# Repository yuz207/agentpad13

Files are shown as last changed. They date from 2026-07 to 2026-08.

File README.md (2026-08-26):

# agentpad13

A 13-key macropad for agentic work, designed from scratch: RP2040, USB-C, 12×1U + 1×2U hot-swap
keys, a clickable EC11 encoder, an analog tilt joystick, a capacitive-touch key, and 24 RGB LEDs
(per-key plus edge underglow) that an open Raw HID protocol drives to show what your agents are
doing — thinking, running, waiting, done, one key each.

## Build one

### → [Open the configurator](https://yuz207.github.io/agentpad13/configurator/site/)

Pick your options, turn the pad around in 3D, and get back an order sheet where every line links to
the exact file you upload to a fab or drop into a slicer. That is the way in. Prefer paper?
[`release/HOW-TO-ORDER.md`](release/HOW-TO-ORDER.md) is the same thing, static.

<p align="center">
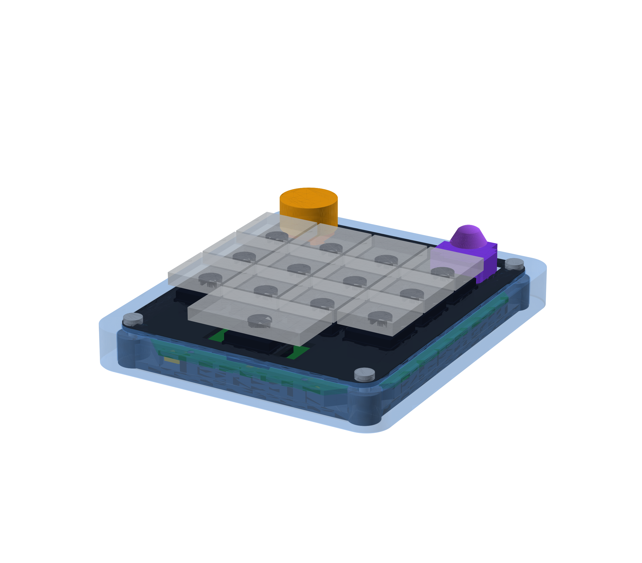
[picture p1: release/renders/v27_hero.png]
agentpad13 v5 board in the v2 case, from CAD
  
</p>

<p align="center"><sub>The shipping v5 board in the v2 case, straight from the CAD.</sub></p>

## What is where

```
release/            The bundle — everything you order, print or flash.
  HOW-TO-ORDER.md     The configurator's static form.
  RELEASE.md          What shipped and why, section by section.
  MANIFEST.md         Every file in the bundle with its md5 and byte count.
  hardware/           Board fab package, case, plate, bases, keycaps, toppers, gasket.
  firmware/           Flashable UF2s, BRING-UP.md, POLARITY-NOTE.md.
configurator/       The published site and its consumption assets; current outputs are copied from development.
firmware/           vial-qmk tree, simulations, conformance tests, BUILD.md.
docs/               The Raw HID protocol contract, and the design reviews.
```

Before you send anything to a fab, run `python3 manifest_selfverify.py` — it should print
**9/9 checks PASS**. Every listed file is present with the right hash, and nothing unlisted is
hiding in the bundle.

## Printed toppers already? Print them again

The v1 encoder knobs and stick caps are retired. The current release carries three Ø17.5 encoder
knob styles and three joystick toppers: a compact nub, restored TPU puck, and a conventional Ø12
topper paired with a TPU restrictor. Details are in [`release/RELEASE.md`](release/RELEASE.md) §(f).

## Status

- **PCB — complete.** v5_8, 84.2 × 100 mm, 2-layer, DRC clean, fab package ready to upload. It retains the v5.7 LED correction, adds the Ø4.0 TP5 solder landing, and factory-populates the encoder.
- **Case — complete.** v2.17: FR4 or printed plate, band in three sidewalls, printed tray.
- **Bases — complete.** Three optional printed bases; the case is finished without one.
- **Firmware — validated.** Emulator-booted and protocol-conformant. Flash `agentpad13.uf2`.
- **Configurator — live.** Static files: no build step, no network calls, no dependencies.

### AgentPad13 Direct OAI (experimental alternative)

The isolated `codex_oai` keymap is an experimental alternative for direct
Codex Desktop control. It is not Vial firmware and does not replace the normal,
recommended `release/firmware/prebuilt/agentpad13.uf2`. Codex Desktop talks to
this target directly—no helper, daemon, bridge, or Vial protocol—using the
locked `Codex Micro Lab OAI LED` identity (`303A:8360`, usage `FF00:61`, Report
ID 6, 64-byte reports).

The current unflashed candidate is
`release/firmware/prebuilt/agentpad13_codex_oai.uf2`, 93,696 bytes, SHA-256
`fcb50b2419419be43b7cf90b00a96b16063fcaf182bc24b9642d57e2e8adf54d`.
Start with the [keymap contract](firmware/loudest_micro/keymaps/codex_oai/README.md),
[source hand-off](firmware/CODEX-OAI-SOURCE.md), and
[Direct OAI build procedure](firmware/BUILD.md#agentpad13-direct-oai-experimental-alternative).
Run the complete host suite from the repository root:

```sh
python3 -m unittest discover -s firmware/tests/codex_oai -p 'test_*.py'
```

The checked-in [emulator capture](firmware/evidence/codex-oai-emulator.json)
and [current manifest](firmware/evidence/codex-oai-current-manifest.json) bind
that exact UF2 to the offline USB/protocol/LED checks. Physical validation is
still entirely PENDING; no install or flash occurred. Any future hardware
operation requires the literal authorization and observation record in the
[physical runbook](docs/codex-oai-physical-runbook.md).

## First power-on

Flash [`agentpad13.uf2`](release/firmware/prebuilt/agentpad13.uf2) — hold BOOTSEL and drag the file on. Then hold
SW14, the button in the back, for about a second and follow the 13 key LEDs: the board measures its
own joystick and stores the result. About 15 seconds, no host software, no reflash, once ever —
full procedure in [`release/firmware/BRING-UP.md`](release/firmware/BRING-UP.md). If an axis reads
backwards that is polarity, not calibration:
[`release/firmware/POLARITY-NOTE.md`](release/firmware/POLARITY-NOTE.md).

Firmware source is in [`firmware/loudest_micro/`](firmware/loudest_micro/); the exact Vial/QMK
build recipe and validation commands are in [`firmware/BUILD.md`](firmware/BUILD.md). The plain-QMK,
byte-reproducible build is [`agentpad13_reference.uf2`](release/firmware/prebuilt/agentpad13_reference.uf2).

## Licensing

- `release/hardware/` — **CERN-OHL-W-2.0** (PCB and case CAD).
- `firmware/` and `release/firmware/` — **GPL-2.0-or-later** (QMK/vial-qmk
  derivative), except `firmware/tests/conformance/protocol_oracle.py`, which is
  **MIT**. Corresponding source for the prebuilt UF2s = this tree built against
  [vial-qmk](https://github.com/vial-kb/vial-qmk) per `firmware/BUILD.md`.

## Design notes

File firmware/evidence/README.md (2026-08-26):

# Evidence files

`codex-oai-emulator.json` is the current emulator capture for
`release/firmware/prebuilt/agentpad13_codex_oai.uf2`. It was regenerated from
this checkout and must match the UF2 SHA-256 and byte size recorded in
`codex-oai-current-manifest.json`. The current port rebuild is 93,696 bytes
with SHA-256
`fcb50b2419419be43b7cf90b00a96b16063fcaf182bc24b9642d57e2e8adf54d`.

Two earlier provenance layers remain explicit:

- The imported phase-3 migration baseline was 92,160 bytes with SHA-256
  `d1768471eef4d0be12c1fc264279f20b9a7d293ea902c0608ebcfb4643ae35be`.
  It was copied byte-for-byte before the destination rebuild and is superseded
  by the current port artifact; it is not a claim about the final source.
- `codex-oai-manifest.json` is retained as historical full-image evidence for
  the still older 92,672-byte artifact with SHA-256
  `11ee3ed649cf198186fc1e3c190fcaf6a7a1cfbdb18f68ebbead974b09a1712b`.
  Its ELF metrics and hash intentionally refer to that older artifact; it is
  not a claim about the current release UF2.

To produce a new full manifest after a clean QMK build, run
`firmware/tools/verify_codex_oai_artifact.py` with the newly generated ELF, the
current emulator JSON and an output path below this directory. The verifier
checks the UF2 hash, ELF size/symbols and emulator handshake atomically; no
device or removable volume is accessed.

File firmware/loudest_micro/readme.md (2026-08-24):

# agentpad13

Open-hardware agent macropad (Rev A, RP2040). 13 keys (12x 1U grid + 1x 2U
hero), EC11 encoder with push, planar analog joystick, TTP223 touch pad, and
24 addressable LEDs (13 per-key + 1 layer indicator + 10 underglow) driven as
a live agent-status display over Raw HID.

* Keyboard Maintainer: [yuz207](https://github.com/yuz207)
* Hardware Supported: agentpad13 Rev A PCB (RP2040, public board `v5_8`)
* Hardware Availability: open source (CERN-OHL-W v2), <https://github.com/yuz207/agentpad13>

The QMK keyboard/module name is `loudest_micro` (the project's working name);
the user-visible product name, USB product string, and Vial sidebar name are
**agentpad13**. The directory name is kept because QMK derives build targets,
artifact names, and file names from it. The public Raw HID contract is
`docs/PROTOCOL-V1-CONTRACT.md`.

Pin map source of truth: the definitive table embedded in
`firmware/check_pins_v4.py`, extracted twice from the final copper and
re-verified against v5_6. The public v5_8 board retains the v5.7 LED20/LED21
orientation, so the GPIO map is identical; see `release/hardware/pcb/V5-NOTES.md`.

Make example for this keyboard (after setting up your build environment):

    qmk compile -kb loudest_micro -km default
    qmk compile -kb loudest_micro -km vial

Flashing example for this keyboard:

    qmk flash -kb loudest_micro -km default

To enter the bootloader, hold BOOTSEL while plugging in USB (or double-tap
RESET), then copy the `.uf2` onto the `RPI-RP2` drive.

See the [build environment setup](https://docs.qmk.fm/#/newbs_getting_started) and
the [make instructions](https://docs.qmk.fm/#/getting_started_make_guide) for more
information. Brand new to QMK? Start with our [Complete Newbs
Guide](https://docs.qmk.fm/#/newbs). The exact reproducible toolchain for this
board (vial-qmk fork, patch, versions) is in `firmware/BUILD.md`.

## Layout

```
 [JS]        USB        (ENC)      <- top control band (not in the key matrix)
 +----+----+----+----+
 |SW1 |SW2 |SW3 |SW4 |            row 0
 +----+----+----+----+
 |SW5 |SW6 |SW7 |SW8 |            row 1
 +----+----+----+----+
 |SW9 |SW10|SW11|SW12|            row 2
 +----+----+----+----+
 |TP| |  SW13   | |EP|            row 3: touch [3,2] | SW13 2U [3,0] | encoder push [3,1]
 +--+ +---------+ +--+
```

Direct-pin matrix (Rev A x-monotonic routing remap - logical positions are
unchanged, only the physical GPIOs moved):

| Function | GPIO |
|---|---|
| SW1..SW4 (row 0) | GP12, GP9, GP5, GP2 |
| SW5..SW8 (row 1) | GP11, GP8, GP4, GP1 |
| SW9..SW12 (row 2) | GP10, GP7, GP3, GP0 |
| SW13 (2U hero) | GP6 |
| Encoder A / B / push | GP13 / GP14 / GP15 |
| Touch (TTP223 OUT) | GP16 |
| WS2812 data (via level shifter) | GP17 |
| Joystick X / Y (ADC) | GP26 / GP27 |

## Firmware feature notes

* `ENCODER_MAP` - per-layer encoder actions (volume by default).
* `JOYSTICK` - GP26/GP27 analog axes as a HID gamepad; the `JS_MODE` keycode adds
  custom arrow (8-way) and scroll modes. **The board calibrates itself**: hold
  SW14 (the button in the back, inert while firmware runs) for about a second
  and the key LEDs guide a ~15 s routine that writes rest/min/max to EEPROM,
  where it survives unplugging and reflashing. No host software, no second
  firmware, no rebuild — see `firmware/BRING-UP.md`. The shipped
  `low 0 / rest 512 / high 1023` values are only the uncalibrated fallback.
* `RAW_ENABLE` - status protocol **v1** (`SET_KEY`/`SET_LAYER`/`CLEAR`/`PING`,
  plus `GET_JOYSTICK`/`SET_CALIBRATION`/`RESET_CALIBRATION` — the same
  calibration store the SW14 routine writes, exposed for host tooling), wire
  contract in `docs/PROTOCOL-V1-CONTRACT.md` with
  `firmware/tests/conformance/protocol_oracle.py` as the public, dependency-free
  host oracle. In the vial build the
  protocol coexists with VIA/Vial through a `via_command_kb()` dispatcher
  (see `firmware/BUILD.md` for the documented edge-case collisions).
* Touch key gated by the `TP_TOG` keycode.

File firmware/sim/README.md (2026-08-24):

# agentpad13 — pre-hardware behavioral simulation

Boots the **real production `.uf2`** in a headless RP2040 emulator and drives it
the way a user would: presses every switch, turns the encoder, taps the touch
pad, moves the joystick, and paints every LED over raw HID — then checks what
came back out over USB and what landed in the LED chain buffer.

This is the layer above [`firmware/tests/emulator/`](../tests/emulator/), which
proves the binary *boots, muxes its pins correctly, enumerates, and answers one
PING*. This directory answers the four questions you actually care about before
the boards land:

| Question | Answered here? |
|---|---|
| Do presses register? | **Yes** — all 13 switches, each to its own keycode |
| Do the LEDs trigger? | **Yes** — the ws2812 DMA buffer is read back per frame |
| Are they individually addressable? | **Yes** — 24/24 chain positions, byte-exact, in isolation |
| Does the firmware work? | **Now yes — after it found the reason it didn't.** See below. |

> ## ✅ FIXED 2026-08-13 — this harness caught a ships-broken defect, and the fix is in
>
> **As originally written, both shipped `.uf2`s FAILED 4 of 33 checks under the
> default `--touch=board`.** The cause was a real, ships-broken defect: the
> TTP223 touch strap is wired active-**high** and the firmware assumed
> active-**low**. Detail in
> [The defect this harness catches](#the-defect-this-harness-catches).
>
> The **firmware-only** remedy was applied (boards were already fabricated *and
> populated*, so the `R10` rework was not available): `GP16` was removed from
> `matrix_pins.direct` and is polled with its own active-high sense in
> `loudest_micro.c` `matrix_scan_kb()`, injecting the key event at the same
> logical `[3,2]`. **The current `firmware/prebuilt/*.uf2` pass 33/33 under
> `--touch=board`** — see [After the fix](#after-the-fix).
>
> Nothing in `behavior.cjs` was changed to make that happen; the harness that
> passed the fixed binaries was byte-identical to the one that failed the broken
> ones. *(`behavior.cjs` was edited once since, on 2026-08-15, and only to ADD
> the `--encoder=` A/B described below — an extension, not a relaxation: the
> check count is still 33 and the four touch failures under `--touch=firmware`
> are still byte-identical to the ones quoted here. No check was ever adjusted to
> make a failing thing pass.)*

---

## Run it

One-time setup (installs `rp2040js` and fetches the RP2040 B1 bootrom dump into
the *existing* emulator directory — this directory adds no dependencies of its
own):

```bash
cd firmware/tests/emulator
./get-bootrom.sh && npm install
```

Then:

```bash
cd firmware/sim
node behavior.cjs                                # reference build, board truth on both A/Bs
node behavior.cjs ../prebuilt/agentpad13.uf2     # the vial build
node behavior.cjs --touch=firmware               # the polarity config.h used to assume
node behavior.cjs --encoder=firmware             # the A/B landing config.h used to assume

node joystick.cjs                                # protocol-v1 referee (0x50/0x51/0x52 + EEPROM
                                                 #   + the SW14 on-board routine, section 10)
node joystick.cjs --no-eeprom                    # its counterfactual arm; must FAIL
```

or `npm run sim:default` / `sim:vial` / `sim:default:fwpolarity` /
`sim:default:fwencoder` / `joystick:default` / `joystick:vial` from this
directory. `behavior.cjs` takes **~35 s** on an M-series Mac and `joystick.cjs`
**~6 min** (it grew from ~45 s on 2026-08-15: section 10 drives the real
on-board calibration routine, which is ~15 s of *emulated* time per run and is
run three times — there is no way to shorten it without shortening the routine
the owner actually performs). Both exit non-zero on any failure, so they drop
straight into CI. No network, no account, no cloud upload, no browser.

> **Artifact names changed 2026-08-15.** `firmware/prebuilt/` now ships
> `agentpad13.uf2` (the vial build — the one users want) and
> `agentpad13_reference.uf2` (the plain-QMK, byte-reproducible reference). They
> replace `loudest_micro_vial.uf2` and `loudest_micro_default.uf2`, which is why
> older transcripts in this file name the old files.

### `--touch=` — the most important flag

| Mode | GP16 at rest | Meaning |
|---|---|---|
| `board` *(default)* | **LOW** | What the v5 PCB does. `R10` (0 Ω) ties `TOUCH_AHLB → GND`; on a TTP223, AHLB low selects **active-high** output, so Q idles LOW and drives HIGH while touched. **This is the mode that must pass.** |
| `firmware` | HIGH | The polarity `config.h` *used to* assume — *"idle high, touched low"*. Kept as the counterfactual arm of the A/B; it does **not** describe any board that exists, and since the fix it is the arm that fails. |

Both shipped builds, run four ways — **before** the fix (Rev-A binaries
`4af788ae…` / `e5008942…`) and **after** it (`cf5bd628…` / `b31673a7…`):

> **Hash note, 2026-08-15.** The shipped pair moved again — `1c0ff911…`
> (default) / `286fb09d…` (vial) — for the isotropic RGB layout and the
> `housekeeping_task_user()` de-duplication. Neither touches polarity, and the
> table below re-measures **identically** on the new binaries: 33/33 PASS under
> `--touch=board`, 4 failures under `--touch=firmware`. The `cf5bd628…` /
> `b31673a7…` labels are kept because this table is the record of the *touch
> fix*'s A/B, not a statement about which bytes ship today.

| Build | `--touch=firmware` | `--touch=board` |
|---|---|---|
| `loudest_micro_default.uf2` **before** | 33 checks, **0 failures** — PASS | 33 checks, **4 failures** — FAIL |
| `loudest_micro_vial.uf2` **before** | 33 checks, **0 failures** — PASS | 33 checks, **4 failures** — FAIL |
| `loudest_micro_default.uf2` **after** | 33 checks, **4 failures** — FAIL | 33 checks, **0 failures** — **PASS** |
| `loudest_micro_vial.uf2` **after** | 33 checks, **4 failures** — FAIL | 33 checks, **0 failures** — **PASS** |

That A/B is the whole diagnostic, and it inverted cleanly: **the same binary
passes under one polarity and fails under the other, and the fix moved which one
is which.** The keymap, the LED chain, the USB stack, the encoder and the
joystick were always fine — only the strap sense was wrong, and the four
failures are exactly the four polarity-bearing checks. A post-fix
`--touch=firmware` failure is therefore expected and *correct*: it is the harness
still proving it can tell the two polarities apart. (The DIAGNOSIS prose printed
in that arm was written for the pre-fix direction and now reads backwards; it is
left verbatim because `behavior.cjs` is the referee and was deliberately not
edited as part of the fix.)

### `--encoder=` — the same idea, for the EC11

Added **2026-08-15**, and for the same reason the touch A/B exists: this harness
had a hard-coded belief about the board that turned out to be false.

A quadrature walk on `GP13`/`GP14` has **no intrinsic handedness**. Which of the
two walks is a physically *clockwise* detent depends on which EC11 terminal
landed on `ENC_A` and which on `ENC_B` — a board fact, exactly like the AHLB
strap. `behavior.cjs` used to assert one answer outright: *the forward walk is
clockwise, therefore it must produce `KC_VOLU`.* Nobody had measured that.

**The owner measured it on the assembled board on 2026-08-15: turning the knob
clockwise produced volume-DOWN.** The firmware was corrected
(`config.h`: `#define ENCODER_DIRECTION_FLIP`, which swaps which walk vial-qmk's
`drivers/encoder/encoder_quadrature.c` calls clockwise), and the harness's
falsified assumption was turned into a switch rather than left standing:

| Mode | "Clockwise" is | Meaning |
|---|---|---|
| `board` *(default)* | the **reversed** GP13/GP14 walk | The fabricated v5_6 A/B landing, measured on hardware and unchanged in public v5_8. **This is the mode that must pass.** |
| `firmware` | the **forward** walk | What this file asserted before 2026-08-15, i.e. the pre-flip assumption. It describes no board that exists; since the flip it is the arm that fails. |

Both modes assert the **same behavior** — CW must give `KC_VOLU`, CCW must give
`KC_VOLD`. Only the walk that stands for "clockwise" moves, which is the one
thing the board decides. No check was relaxed and the count is still 33.

The two switches are independent and compose, which is itself the proof that
each isolates its own fault. Measured on both current builds:

| `--touch=` | `--encoder=` | checks | failures | which |
|---|---|---|---|---|
| `board` | `board` | 33 | **0 — PASS** | the gate |
| `board` | `firmware` | 33 | 2 | both encoder checks, and only those |
| `firmware` | `board` | 33 | 4 | the four touch checks, byte-identical to the 2026-08-13 table above |
| `firmware` | `firmware` | 33 | 6 | 4 + 2, no interaction |

---

## The defect this harness catches

> **Historical record — everything in this section describes the firmware as it
> shipped BEFORE 2026-08-13.** The board facts are still current; the firmware
> quotes are not (both comments were corrected). Kept verbatim so the failure and
> its evidence stay legible. See [After the fix](#after-the-fix).

**Board truth**, confirmed directly in the released board:

* `release/hardware/pcb/v5_8.kicad_pcb` — footprint `R10`, value `0R`, pads
  `1 → TOUCH_AHLB`, `2 → GND`

On a TTP223, **AHLB tied low selects active-high output**: `Q` idles LOW and
goes HIGH while the pad is touched.

**Firmware assumption**, which is the opposite:

* `firmware/loudest_micro/config.h:21` — *"The PCB straps the AHLB pad
  active-low, so the pad reads like a normal direct pin (idle high, touched
  low)."*
* `firmware/loudest_micro/keyboard.json:32` — *"PCB straps AHLB active-low so it
  reads like a normal direct pin"*

**And nothing reconciles them.** `MATRIX_INPUT_PRESSED_STATE` is never defined
anywhere in the keyboard tree, so QMK's default applies: a direct pin reading
LOW is *pressed*. There is no inversion in `matrix.c`, none in
`loudest_micro.c` (the only touch-related code there is `touch_enabled`, a
TP_TOG gate, not a polarity flip).

### What that does, as the sim demonstrates

GP16 rests LOW → matrix `[3,2]` is **held from power-on**. `[3,2]` is the
layer-cycle key, `TO(L_CTRL)` on layer 0. So:

```
0b. boot layer — the layer indicator must say layer 0 (BASE)
  ..   layer indicator (chain 13) at boot: 31,23,0
  [FAIL] device booted into layer 0 (indicator is pure red, hue 0)  <- 31,23,0

0c. blast radius — SW1 at the as-booted layer must still be KC_F13
  [FAIL] SW1 emits KC_F13 (0x68) from the as-booted layer  <- no keyboard report at all
  !!   The layer-0 keymap is unreachable: every one of the 12 macro keys, and the
  !!   2U hero key, resolves against L_CTRL instead (RGB/media/JS_MODE), and the
  !!   encoder maps to RGB_MOD rather than volume.

0d. touch polarity — the layer must advance ON TOUCH, not on release
  ..   layer indicator: rest 31,23,0 -> touched 31,23,0 -> released 15,31,0
  [FAIL] the layer advances while the pad is TOUCHED  <- still 31,23,0 while touched
  [FAIL] the layer does NOT advance again when the finger LIFTS  <- ... -> released 15,31,0
  !!   DIAGNOSIS: the layer moved on finger LIFT — the inverted-polarity signature.
```

Three separate user-visible symptoms, all from one strap:

1. **The pad boots into layer 1 (CTRL) and can never reach layer 0 (BASE).**
   `F13`–`F24` — the entire product — are unreachable. Indicator hue 32 (orange)
   at power-on instead of hue 0 (red).
2. **Pressing SW1 emits nothing at all**, because layer 1 puts `JS_MODE` there,
   a custom keycode with no USB report. The encoder becomes `RGB_MOD` instead of
   volume.
3. **Touch fires on finger LIFT, not on touch** — every touch action is off by
   one edge.

### How it was fixed — and one trap that was avoided

**⚠ `MATRIX_INPUT_PRESSED_STATE 1` is NOT the fix.** That define is *global*, not
per-pin: QMK's `readMatrixPin()` applies it to every direct pin
([`quantum/matrix.c:97`](https://github.com/qmk/qmk_firmware/blob/master/quantum/matrix.c)),
so setting it to `1` would invert all 13 mechanical switches — which really are
active-low to GND — and trade one broken key for thirteen.

There were two real options, **alternatives, not both**:

* **Hardware.** Move `R10` from `GND` to `+3V3`. AHLB high selects active-low
  output, which is what the firmware already expected — exactly the escape hatch
  `SCHEMATIC-REVIEW.md:156` documents (*"move to +3V3 for active-low"*). **Not
  available:** the boards are already fabricated *and populated*, so this would
  be a per-unit 0402 rework.
* **Firmware (the one taken, 2026-08-13).** `GP16` was dropped from
  `matrix_pins.direct` (`[3][2] → null`) and is polled in `loudest_micro.c`
  `matrix_scan_kb()` — matrix-scan cadence, 5 ms debounce — with its own
  active-high sense, injecting `action_exec(MAKE_KEYEVENT(3, 2, pressed))` so the
  key keeps its logical position, its keycode, its `TO()` layer chain and its
  `TP_TOG` gate. `keyboard_pre_init_kb()` configures the pin (pull-**down**, so a
  high-Z `U6` reads untouched), because `matrix_init_pins()` no longer sees it.
  Cost: Vial's matrix tester cannot display `[3,2]`, since that reads the scanned
  `matrix[]`.

Both comments that asserted the wrong polarity — `config.h:21` and
`keyboard.json:32` — were corrected in the same change.

---

## After the fix

`--touch=board` — the real hardware polarity — **33/33 on both builds**. This is
the acceptance run; the harness was not modified to produce it.

> **This transcript is the 2026-08-13 acceptance run, kept verbatim as the record
> of the touch fix.** It names `loudest_micro_default.uf2`, which no longer
> exists, and it predates the `--encoder=` A/B, so its summary line has no
> encoder model on it. The current gate is
> `node behavior.cjs --touch=board --encoder=board` against
> `agentpad13_reference.uf2` / `agentpad13.uf2`, and it still reads
> **33 checks, 0 failures** on both.

```
agentpad13 behavioral sim — loudest_micro_default.uf2
loaded 173 UF2 blocks
touch model: BOARD TRUTH — TTP223 AHLB->GND (R10) = active-high, GP16 idles LOW

0. boot + USB enumeration
  [ok] USB configured
  ..   interfaces: #0 cls3/proto1 in1  #1 cls3/proto0 in2/out3
  [ok] ws2812 DMA source buffer located
  ..   pixel buffer @ 0x200020c0 (24 x uint32, GRB in bits 31:8)
  [ok] pixel words carry GRB<<8 (low byte always 0)

0b. boot layer — the layer indicator must say layer 0 (BASE)
  ..   layer indicator (chain 13) at boot: 31,0,0
  [ok] device booted into layer 0 (indicator is pure red, hue 0)

0c. blast radius — SW1 at the as-booted layer must still be KC_F13
  [ok] SW1 emits KC_F13 (0x68) from the as-booted layer

0d. touch polarity — the layer must advance ON TOUCH, not on release
  ..   layer indicator: rest 31,0,0 -> touched 31,23,0 -> released 31,23,0
  [ok] the layer advances while the pad is TOUCHED
  [ok] the layer does NOT advance again when the finger LIFTS
  [ok] touch sends no USB key report (TO() is a layer move)

1. LED chain — 24 positions, one unique color each (raw HID SET_KEY)
  [ok] all 24 chain positions independently addressable
  ..   0-12 per-key: 10,100,200  13,98,195  ...  46,76,140
  ..   13 indicator: 49,74,135
  ..   14-23 underglow: 52,72,130  ...  79,54,85
  [ok] repainting LED 9 alone moves only LED 9
  [ok] LED 9 took the exact requested color 254,2,127

2. CLEAR releases the chain back to the on-device animation
  [ok] no LED is still holding its host-set color
  [ok] chain is live (some LED is lit by the local animation)
  ..   layer-0 indicator (chain 13): 31,0,0
  [ok] layer-0 indicator is pure red (hue 0 = layer 0)

3. every switch — GPIO low -> the keycode the default keymap assigns
  [ok] GP12 SW1  [0,0] -> KC_F13 (0x68) then release
  [ok] GP 9 SW2  [0,1] -> KC_F14 (0x69) then release
  [ok] GP 5 SW3  [0,2] -> KC_F15 (0x6a) then release
  [ok] GP 2 SW4  [0,3] -> KC_F16 (0x6b) then release
  [ok] GP11 SW5  [1,0] -> KC_F17 (0x6c) then release
  [ok] GP 8 SW6  [1,1] -> KC_F18 (0x6d) then release
  [ok] GP 4 SW7  [1,2] -> KC_F19 (0x6e) then release
  [ok] GP 1 SW8  [1,3] -> KC_F20 (0x6f) then release
  [ok] GP10 SW9  [2,0] -> KC_F21 (0x70) then release
  [ok] GP 7 SW10 [2,1] -> KC_F22 (0x71) then release
  [ok] GP 3 SW11 [2,2] -> KC_F23 (0x72) then release
  [ok] GP 0 SW12 [2,3] -> KC_F24 (0x73) then release
  [ok] GP 6 SW13 [3,0] 2U hero -> KC_MPLY (consumer 0xcd)
  [ok] GP15 ENC_SW [3,1] push -> KC_MUTE (consumer 0xe2)

4. EC11 encoder — quadrature on GP13/GP14, layer 0 maps to volume
  [ok] rotate CW -> KC_VOLU (consumer 0xe9)
  [ok] rotate CCW -> KC_VOLD (consumer 0xea)

5. analog joystick — ADC injection -> HID gamepad report (report id 0x07)
  ..   rest                   report (none)  axes=n/a
  ..   ADC0 high / ADC1 low   report 071afee801  axes=-486,488
  ..   ADC0 low / ADC1 high   report 07e8011afe  axes=488,-486
  [ok] joystick emits HID gamepad reports at all
  [ok] both axes swing to near full scale on a full ADC sweep
  [ok] the two axes move independently (swapping the ADC inputs flips both signs)
  ..   ADC channels the emulator serviced: [1,0]
  ..   axis IDENTITY (which report slot is X) is NOT decided by this run.

touch model: board   checks: 33   failures: 0
BEHAVIOR SIM: PASS
```

`loudest_micro_vial.uf2` produces the identical 33/33, with the pixel buffer at a
different address — which is exactly why the buffer address is **discovered at
runtime** rather than hardcoded. The default image grew by one 512-byte UF2 block
(172 → 173) for the out-of-matrix touch handling.

The sibling smoke test `firmware/tests/emulator/runner.cjs` carried the same
wrong idle-level assumption (it drove GP16 high with the switch lines and
asserted a pull-up on it) and was corrected to board truth in the same change; it
now fails on the pre-fix binaries and passes on the current ones.

---

## How the LED readback works

QMK's RP2040 `vendor` ws2812 driver hands its pixel array to a DMA channel that
feeds **PIO0's TX FIFO** (`PIO0_BASE + TXF0 = 0x50200010`). The harness watches
every DMA channel start; the lowest read address of whichever channel targets
`TXF0` *is* the pixel buffer, by definition. Nothing is hardcoded, so a rebuild
that moves the buffer does not break the test.

Each entry is one `uint32` carrying **GRB in bits 31:8** — the state machine
runs autopull with `PULL_THRESH = 24`, MSB first, so the low byte is always
zero. The harness asserts that invariant structurally; if a future QMK changes
the packing, the run fails loudly instead of printing plausible nonsense.

So the colors printed above are **the exact words the PIO shifts onto GP17** —
one hop short of the wire.

The chain-index proof is the important part: `SET_KEY(i, r, g, b)` was sent for
every `i` in `0..23` with a distinct color, and every one landed at chain
position `i` with the exact bytes requested. Then LED 9 alone was repainted and
**only** LED 9 moved. That is what "individually addressable" means, and it is
now demonstrated on the shipping binary rather than assumed.

---

## What this cannot tell you

Read this before treating a PASS as permission to skip bring-up.

### Not simulated at all — only real hardware can answer

* **WS2812/SK6812 bit timing on the wire.** The emulator is *not cycle-faithful*
  (the PIO is stepped from the harness loop because `RPPIO.run()` self-schedules
  via `setTimeout`, and its `CLKDIV` is parsed but never used to pace
  execution — [rp2040js PR #117](https://github.com/wokwi/rp2040js/pull/117) was
  closed unmerged). We validate the *data*, never the `T0H`/`T1H` pulse widths.
* **The SN74LVC1T45 level shifter, the 5 V rail, and the LED chain itself.**
  We stop at GP17. Whether LED 7 is physically wired seventh is a hardware fact.
* **Whether the touch pad works as a sensor.** We model GP16's *logic level*
  from the strap. Pad sensitivity through the case, C25 tuning, and false
  triggering are unanswerable without the board.
* **Encoder detent direction — *was* unanswerable here, and it bit us.** This
  bullet used to read *"we prove a CW quadrature walk produces `KC_VOLU`;
  whether turning the physical knob clockwise produces the CW walk depends on
  which way A and B are soldered"* — correctly identifying the gap, while the
  harness went on asserting one side of it anyway. The owner measured the real
  board on **2026-08-15** (clockwise gave volume-DOWN), the firmware got
  `ENCODER_DIRECTION_FLIP`, and the assumption became the `--encoder=` A/B
  above. The emulator still cannot tell you which walk your knob makes; it can
  now tell you which walk this *board* makes, because a human measured it once.
* **Joystick axis direction.** Which way the gimbal drives each wiper is
  mechanical and is still not answerable here — see `firmware/POLARITY-NOTE.md`.
  (Calibration itself is no longer in this list: see the next bullet.)
* **EEPROM / Vial persistence — no longer out of reach.** rp2040js's SSI
  peripheral is a stub and flash writes do not work in stock rp2040js
  ([#157](https://github.com/wokwi/rp2040js/issues/157)), and its `IO_QSPI` is
  an `UnimplementedPeripheral` whose `0xffffffff` reads make QMK's wear-levelling
  driver believe every flash access was aborted — so an EEPROM write used to be
  a silent no-op. `joystick.cjs` attaches a small serial-NOR model to the SSI
  (workaround **(g)** below) and therefore **does** exercise QMK's emulated
  EEPROM: it stores a calibration, restarts the emulated MCU carrying only the
  flash image, and reads the values back. Its `--no-eeprom` arm removes the model
  and must fail on exactly those checks. What is still out of reach is Vial's own
  dynamic-keymap persistence, which nothing here drives.
* **Anything electrical:** USB timing margins, inrush, the 500 mA budget,
  brownout, ESD, thermals.

### Simulated but NOT trustworthy

* **Joystick axis identity.** The run shows ADC0 (GP26, declared `x`) landing in
  the *second* report slot and ADC1 (GP27, declared `y`) in the *first*. **Do
  not read that as an axis swap in the firmware.** rp2040js's round-robin
  channel selector has a real masking bug — `adc.ts` writes
  `(channel & CS_AINSEL_SHIFT)` where `CS_AINSEL_SHIFT` is `12`, when it means
  `(channel & CS_AINSEL_MASK)` with mask `0x7`; that is the root cause of open
  issue [#141](https://github.com/wokwi/rp2040js/issues/141) *("only ADC0 (pin
  26) reads successfully")*. The harness prints the channel order the emulator
  actually serviced so the artifact is visible. The *magnitudes* are sound:
  12-bit `4000` → QMK's 10-bit `1000` → `+488`, and `100` → `25` → `-486`, both
  correct against `rest = 512`.
* **USB config descriptor completeness.** Continuation packets of a multi-packet
  control IN transfer never arrive, so the 91-byte configuration descriptor
  truncates at 64. The boot-keyboard and raw-HID interfaces are complete within
  that first packet; the third (shared: NKRO / consumer / joystick) interface is
  not, so the harness identifies its endpoint from observed traffic instead. A
  descriptor defect in those last 27 bytes would not be caught.
* **Timing-dependent behavior generally** — debounce windows, tap-hold terms,
  `RGB_MATRIX` frame rate. Simulated time is not wall time.

### Emulator workarounds in force

Seven rp2040js fidelity issues are worked around **in the harness, never in the
firmware**, each commented at its site.

**(a)–(e), in both harnesses** (the first four match
`firmware/tests/emulator/runner.cjs`): the ADC `FIFO_REG` interrupt latch,
unimplemented DMA `CHAN_ABORT` reads, DREQ latches that only update on FIFO
transitions, `chan.start()` ignoring an already-asserted DREQ, and the PIO's
`setTimeout` self-scheduling. Pull-ups are also not folded into `inputValue`
([#154](https://github.com/wokwi/rp2040js/issues/154)), so idle-high lines are
driven high explicitly — **and GP16 is driven from the polarity model rather
than assumed, which is precisely what let this harness catch the strap bug.**

**(f) and (g), in `joystick.cjs` only, and both switchable** — a workaround that
cannot be switched off cannot be audited:

* **(f) `ADC.CS.START_ONCE` is self-clearing on silicon and not in rp2040js.**
  ChibiOS's RP ADC LLD sets the channel with a read-modify-write of `CS`, so the
  stale bit is written back and kicks off a second conversion; every
  `adcConvert()` then returns the previous conversion's value. Switch it off
  with `--no-adc-fix` and the board reports `live X=200 Y=800` for an injected
  `800/200` — the swap signature of a strict one-sample lag. **Measured, 2 of 48
  checks fail, and only the live-ADC ones.**
* **(g) flash writes do not work in stock rp2040js.** The SSI peripheral is a
  stub that discards `DR0` writes and always reports `RXFLR = 0`, and `IO_QSPI`
  is an `UnimplementedPeripheral` returning `0xffffffff` — which QMK's
  wear-levelling driver reads as *"flash access aborted"*, so its write loops
  bail out and the EEPROM silently never changes. `joystick.cjs` attaches a
  byte-level serial-NOR model (WREN / page-program / sector- and block-erase /
  read-status) to the SSI and a real register file to `IO_QSPI`, so writes land
  in the same `flash` array the XIP read path already serves. Two things had to
  be measured rather than guessed to make it work: the FIFO must answer even
  while CS is **high** (the bootrom's `flash_exit_xip()` clocks dummy bursts
  through the same loop, and the loop's only other exit was the now-honest abort
  flag — boot hangs in ROM at `0x1784` otherwise), and the FIFO must be cleared
  at **both** CS edges (boot2, re-run from RAM after every program, leaves bytes
  behind; without the clear exactly five EEPROM writes succeed and the sixth
  hangs). Switch it off with `--no-eeprom`: **5 of 48 checks fail, and only the
  persistence ones.**

---

## Why this and not Wokwi

The v4 plan called for "a Wokwi sim of the real UF2". Wokwi **cannot do the
important half of that job**, and this harness can, because it uses Wokwi's own
emulator engine directly instead of Wokwi's product.

Wokwi accepts a pre-built RP2040 `.uf2` and has a real headless CLI, and its
RP2040 model does cover GPIO, PIO, DMA-for-PIO, and ADC on GP26/GP27
([docs.wokwi.com/parts/wokwi-pi-pico](https://docs.wokwi.com/parts/wokwi-pi-pico),
[docs.wokwi.com/vscode/project-config](https://docs.wokwi.com/vscode/project-config)).
But:

* **Its USB is CDC-serial only — HID is not implemented.** The Pico support
  matrix says so, and the request to observe HID traffic
  ([wokwi-features#306](https://github.com/wokwi/wokwi-features/issues/306)) has
  been open with zero votes since February 2022. For a *keyboard*, that removes
  the entire point: no keycodes, no layers, no Raw HID / VIA.
* **No scenario verb sets a GPIO**; each switch must be modelled as a
  `wokwi-pushbutton` part. The rotary encoder part (`wokwi-ky-040`) has **no**
  automation control at all, and **no TTP223 part exists** — so the very defect
  above would have been unreachable.
* **Per-LED colors are only readable as a rendered PNG** (`take-screenshot` on
  the NeoPixel part), not as an RGB array.
* It is **cloud-only** — firmware is uploaded to Wokwi's servers — needs an
  account and a `WOKWI_CLI_TOKEN`, allows 50 simulation-minutes/month on the
  free tier, and its scenario API is self-described as alpha
  ([docs.wokwi.com/wokwi-ci/getting-started](https://docs.wokwi.com/wokwi-ci/getting-started)).

Wokwi's engine is the MIT-licensed [`rp2040js`](https://github.com/wokwi/rp2040js),
which exposes raw USB device hooks (`onEndpointWrite`, `onEndpointRead`,
`sendSetupPacket`) that the Wokwi product does not surface. Using the library
directly gives HID observation, direct GPIO injection, direct ADC injection,
and exact per-LED bytes — offline, free, in ~35 seconds.

**The Wokwi item on the v4 plan should be considered closed by this directory,
not still outstanding.**

---

## Files

| File | What it is |
|---|---|
| `behavior.cjs` | The behavioral harness. Reuses `../tests/emulator/node_modules` + `bootrom.cjs`. Two A/B switches, `--touch=` and `--encoder=`, both defaulting to board truth. |
| `joystick.cjs` | Added 2026-08-15. Referee for the **protocol-v1 calibration commands** on the same shipped `.uf2`s: `0x50` framing and live ADC, `0x51` acceptance with `floor(60%)` threshold derivation and the SRAM gamepad rescale, every `0x51` rejection class (out-of-range, `min ≥ rest`, `rest ≥ max`, the 99-vs-100 half-swing boundary, a truncated frame) each proven to write **nothing**, `0x52`, CAPS reporting version 1, and **EEPROM persistence across a simulated power cycle**. A/B arms `--no-eeprom` and `--no-adc-fix` must FAIL. **Section 10, added later on 2026-08-15, drives the whole SW14 ON-BOARD routine** with no host at all — the button is presented on `qspi[1]`, the stick is swept through the ADC, and the board arms, centres, tracks its envelope, validates, derives and stores entirely by itself; it then asserts the resulting EEPROM image is **byte-identical** to pushing the same six numbers over `0x51`, and that a failed run (half-swing under the contract's minimum) writes **nothing at all**. It also times the interrupts-disabled window inside `sw14_pressed()`. **62 checks.** |
| `package.json` | Convenience scripts only — no dependencies of its own. |

*(`calibrate.cjs` lived here from 2026-08-13 to 2026-08-15. It refereed the
separate bring-up firmware `loudest_micro_calibrate.uf2` by decoding the text
that firmware **typed** over HID. That keymap, its UF2 and this referee are all
deleted; `joystick.cjs` is not its successor in kind — it tests the EEPROM
store and the wire protocol, which is where the calibration actually lives now.)*

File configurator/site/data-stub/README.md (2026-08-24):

# data-stub — stand-in data for the configurator site

The site loads `../build/out/{catalog,positions,costs}.json` first. If the build
has not produced them, it falls back to this directory and says so in the
console. Everything here is **marked `"STUB": true`** and exists so the page —
layout, rules, build sheet, viewer placement — can be developed and tested
before the pipeline lands.

Do not regenerate these files in the public repository. Current consumption
assets are copied from the development repository and validated before
publication; the helper script is retained only as implementation history.

## What is real and what is not

| | status |
|---|---|
| `release/…` paths in `catalog.json` | **real** — every one resolves in the release bundle, and `configurator/tests/site_data.test.mjs` fails if one does not |
| geometry in `positions.json` | **real** — read off `contract_v4.json` and `agentpad13_case_v2.py` |
| `meshes/*.glb` | **stubs** — boxes, rounded prisms, rings and cylinders at the real footprints and the real z stack. Not the shipping geometry |
| `costs.json` | empty by design: `updated: null`, so the sheet renders no prices |

The stub `board.glb` additionally carries the EC11 body and the joystick body
(envelopes from the case script's keep-outs) so the plate's encoder and stick
openings read as hardware rather than as holes into an empty case. The real
`board.glb` is a bare slab, so with generated data those two openings show the
tray floor.

## Frame and placement — the same contract as the generated data

Meshes are already in glTF's **Y-up right-handed** space. A board-frame
position `(x, y)` at height `z` is placed at `(x, z, y)` — the **determinant
−1** swap `positions.json` documents. That swap is what turns the case model's
*left-handed* design frame into the correctly handed real device; the usual
det +1 Z-up→Y-up rotation `(x, z, −y)` would render the **mirror image**.
`viewer.js` therefore applies no rotation of its own.

- **baked** — `board`, `plate`, `band_*`, `tray`, `base_*` carry their assembly
  position in the vertex data: load and add.
- **instance** — `cap_*`, `knob_*`, `stick_cap_*` sit at their own local
  origin. Caps start at `y = 0` (bottom rim) and are placed at
  `keycap_seat_z`; knobs and stick caps carry their absolute height and are
  placed at `(x, 0, y)`.

`../assets/switch_mx.glb` is **not** catalog data: MX switches are user-supplied
and no release file exists for them, so the site owns that stand-in.

## Deltas between this stub and `build/out/` (2026-08-20)

Both files are kept key-for-key in step, and
`site_data.test.mjs` fails when they drift. Two fields exist here that the
generated data does not carry yet:

1. `catalog.firmware.flash` — the flash command line the spec's fixed footer
   requires (`release/firmware/BRING-UP.md` step 1). `sheet.js` falls back to a
   constant when it is absent.
2. `positions.base.tilt_deg` — per-variant base tilt, so the viewer can level a
   wedge or pedestal on the desk (`agentpad13_base_params.json`
   `variants[].tilt_deg`). `viewer.js` falls back to a constant when absent.

`board.texture` is `null` here (a stub has no board render to show); the viewer
uses the mesh's own authored material and texture when the generated data
supplies one.

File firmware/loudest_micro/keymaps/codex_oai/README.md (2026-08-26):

# AgentPad13 direct Codex OAI keymap

`codex_oai` is an isolated laboratory keymap for checking whether Codex Desktop
can drive an AgentPad13 directly through OAI Raw HID. It is **not** the normal
AgentPad13 firmware and it does not change the `default` or `vial` keymaps.

## Local USB identity

The keymap intentionally reproduces the local Codex Micro OAI LED endpoint:

| Property | Value |
|---|---|
| VID:PID | `303A:8360` |
| Manufacturer / product | `hirlu` / `Codex Micro Lab OAI LED` |
| Device version | `0x0005` |
| Raw HID usage | `FF00:61` |
| Report format | Report ID 6; 64 bytes total |

This identity is only for this local experiment. It must not be confused with
the regular AgentPad13 identity, and it must not be shipped as the normal
`default` or `vial` firmware.

## Direct endpoint

Codex Desktop talks straight to the keyboard's Raw HID endpoint. There is no
Python helper, daemon, bridge, Vial protocol, or Vial configuration interface
in this target. OAI RPC fragments use the validated Report-ID-6, 64-byte
framing. Controls do not emit OAI notifications until the endpoint has
received both `v.oai.rgbcfg` and `v.oai.thstatus`.

The only keyboard-originated OAI control names are:

`AG00`–`AG05`, `ACT06`–`ACT12`, `ENC`, `ENC_CW`, and `ENC_CC`.

The board has thirteen key switches: twelve matrix keys plus the separate
bottom-left 2U key. The CODEX layer assigns those thirteen physical positions
to the official action order (`AG00`–`AG05`, `ACT06`–`ACT12`); `ACT10` is the
protected ACCEPT wire route, `ACT11` is the second microphone contact, and
`ACT12` is SEND. The encoder click and TP5 touch pad are additional controls,
not extra matrix keys. The legacy `MICROPHONE` action digit remains accepted
in custom maps and aliases ACT10 for backwards compatibility.

Joystick movement is deliberately not translated into invented OAI events.

## Personalización de la capa CODEX/OAI por HID

Codex puede leer y cambiar las 15 posiciones de la capa CODEX sin helper ni
Vial. El mapa se representa como 15 dígitos hexadecimales, uno por posición:

| Dígito | Acción |
|---|---|
| `0` | NOOP |
| `1` | PREVIOUS |
| `2` | NEXT |
| `3` | NEW |
| `4` | REVIEW |
| `5` | PLAN |
| `6` | IMPLEMENT |
| `7` | REFACTOR |
| `8` | TEST |
| `9` | ABORT |
| `a` | SAFE |
| `b` | ACCEPT |
| `c` | SEND |
| `d` | ENC (solo click del encoder, posición 13) |
| `e` | MICROPHONE (`ACT10` push-to-talk) |
| `f` | ACT11 (second official microphone contact) |

El mapa de fábrica es `123456789abfcd1`: las posiciones 0–12 siguen el orden
oficial `AG00..AG05`, `ACT06..ACT12`; la posición 13 es el click del encoder y
14 se conserva como ranura OAI legacy para compatibilidad del protocolo. TP5
ya no emite esa ranura: cambia de capa. Las capas FN/NAV/MEDIA
siguen siendo keymap QMK normal y se pueden modificar en `keymap.c`; la API
solo cambia CODEX/OAI.

Leer el mapa:

```json
{"method":"v.oai.keymap.get","id":42,"params":{"l":0}}
```

Respuesta compacta:

```json
{"result":{"l":0,"m":"123456789abfcd1"},"id":42}
```

Guardar un mapa personalizado:

```json
{"method":"v.oai.keymap.set","id":42,"params":{"l":0,"m":"0123456789abcd0"}}
```

El firmware valida la longitud, cada dígito, la capa (`l` debe ser 0) y la
posición reservada de `ENC` antes de sustituir nada. Una respuesta
`{"result":true,"id":42}` confirma la escritura; los errores devuelven
`{"error":"invalid_keymap","id":42}` y dejan el mapa anterior intacto.
La copia se guarda con magic, versión y checksum en el wear-leveling del
RP2040 (fuera del área `eeconfig`); tras reiniciar se recupera automáticamente.
El formato persistido está en la versión 3. Las copias de fábrica anteriores
(`...abccd1` y `...abced1`) se migran al nuevo mapa `...abfcd1`, mientras que
un mapa personalizado se conserva. Si la copia está ausente o corrupta se
reinstala el mapa de fábrica. Un reset de EEPROM (`eeconfig_init_user`) también
vuelve a los defaults.

## Layer behavior and native fallback

The default firmware has four layers. TP5 is the only layer control and cycles
`CODEX -> FN -> NAV -> MEDIA -> CODEX`. Its input is intentionally ignored
during the 2.28-second power-on LED self-check, which filters the TTP223
settling edge and preserves the CODEX boot layer. The encoder press always
emits the OAI `ENC` press/release pair; neither a tap nor a hold changes layer
or OS mode. SAFE/ACCEPT arming is an internal timer state and is not a layer.

`CODEX` is human layer 1 and QMK layer index 0. At each boot the firmware
resets both QMK RAM layer-state sources to that layer, so an earlier persisted
default FN/NAV/MEDIA layer cannot override it. The direct OAI keymap RPC
accepts only `l:0`; FN/NAV/MEDIA are ordinary auxiliary layers and never
replace the OAI map at startup.

| Layer | Grid defaults | Hero / encoder / touch |
|---|---|---|
| `CODEX` | OAI controls below | `SEND` / OAI `ENC` / TP5 layer cycle |
| `FN` | `JS_MODE`, F2–F12 | media play / OAI `ENC` / TP5 layer cycle |
| `NAV` | Escape, home/end, arrows, paging and editing | OAI `ENC` / TP5 cycle / `TP_TOG` |
| `MEDIA` | media, volume and RGB controls | OAI `ENC` / TP5 layer cycle |

The FN/NAV/MEDIA rows are intentionally ordinary keymap data in `keymap.c`:
users can replace them without touching the OAI parser or LED renderer.
Additional extension layers remain compile-time opt-in through
`CODEX_EXTRA_LAYERS` (up to the three declared extension rows). `TP_TOG` lives on
NAV so touch can be re-enabled after it has been disabled; TP5 itself remains
the layer-cycle gesture while enabled.

Before the OAI handshake is ready, CODEX controls fall back to the proven
native Codex shortcuts: AG00/AG01 previous/next, AG02 new task, AG03 review,
AG04 plan, AG05 implement, ACT06 refactor, ACT07 test, ACT08 abort, ACT09 SAFE,
ACT10 protected ACCEPT, ACT11 microphone, and ACT12 SEND. ACCEPT is a no-op on a short tap
and fires once on release after 600 ms or after SAFE has been held long enough
to arm. NEW emits the primary-modifier+N shortcut on a short tap and
Control+grave when held for `TAPPING_TERM` or longer. Releasing SAFE always
clears the arm. Encoder rotation changes reasoning in CODEX and scrolls in FN.
The fallback
is mutually exclusive with OAI routing, so one physical event cannot emit both
a native shortcut and an OAI frame.

## Physical layout and OAI controls

The `LAYOUT` has fifteen positions: thirteen key switches, encoder click and
TP5. The thirteen switches use the official OAI order; the bottom-left 2U is
the physical position 12 and therefore carries `ACT12`/SEND in the default
map. TP5 is reserved for layer cycling; it is no longer an additional `AG00`
route. The normal `AG00` action remains on K00.

| Matrix position | Physical control | OAI control |
|---|---|---|
| `[0,0]` | grid key | `AG00` |
| `[0,1]` | grid key | `AG01` |
| `[0,2]` | grid key | `AG02` |
| `[0,3]` | grid key | `AG03` |
| `[1,0]` | grid key | `AG04` |
| `[1,1]` | grid key | `AG05` |
| `[1,2]` | grid key | `ACT06` |
| `[1,3]` | grid key | `ACT07` |
| `[2,0]` | grid key | `ACT08` |
| `[2,1]` | grid key | `ACT09` |
| `[2,2]` | matrix key 11 | `ACT10` / protected `ACCEPT` |
| `[2,3]` | matrix key 12 | `ACT11` / microphone |
| `[3,0]` | separate 2U key | `ACT12` / SEND |
| `[3,1]` | encoder press | `ENC` |
| `[3,2]` | capacitive touch TP5 | cycle layer |

When the endpoint is ready, encoder rotation sends `ENC_CW` or `ENC_CC` and an
encoder press sends `ENC` on every layer. The encoder never changes layers;
TP5 alone cycles the layer table without generating an OAI control. `[0,0]` is
also the ordinary Bootmagic Lite recovery position; that recovery behaviour
remains QMK-native.

## LED contract

The 24-pixel RGB chain is rendered locally from the six OAI task slots and the
endpoint link state. The direct keymap owns the renderer; the older AgentPad
status renderer is bypassed only for this keymap.

| LEDs | Meaning |
|---|---|
| 0–5 | one RGB task slot per LED (six slots) |
| 6–12 | white press feedback for function keys `ACT06`–`ACT12` |
| 12 | white press feedback for the physical `ACT12`/SEND position, otherwise selected task summary |
| 13 | TP5/layer indicator: exact active-layer colour; optional animation may pulse brightness only |
| 14–23 | dim global underglow for the selected task |

Action feedback is white for 160 ms on every physical function key (positions
6–12). The six task positions `AG00`–`AG05` never flash white, even if a
custom OAI map assigns them another action; their LEDs remain task-state LEDs.
By default, a task LED holds its selected
RGB/brightness value until that task changes or is removed. LED 13 always
identifies the active layer: CODEX/OAI red, FN yellow, NAV green, and MEDIA
cyan (additional layers continue through the palette), even while the OAI link
is waiting or in error. This keeps a fresh CODEX boot visibly distinct from
FN before the handshake. The optional animation build may add a slow brightness
pulse without changing the hue; the steady default build does not blink. LED 12 and the
underglow prefer the active working task when one exists. A build that wants the earlier animated mode can opt in explicitly with
`CODEX_LED_ANIMATION_ENABLE=1`; that compatibility mode is deliberately slow
and uses a non-zero colour fade instead of a hard blink. The shipped/default
build leaves it disabled.

## Power-on LED self-check

After each USB power-up the firmware runs a one-shot physical-chain check:
LEDs **1 → 24** (renderer indexes `0..23`) light one at a time in white for
80 ms each. The complete chain then flashes green twice and normal task/link
rendering resumes after approximately 2.28 seconds. If RGB had been disabled,
the keymap enables it with the `*_noeeprom` API and keeps it active for the
task/link renderer; no EEPROM or OAI event is written. This proves
the local WS2812 data path and ordering, but it does not prove USB enumeration,
the OAI handshake, or task notifications; those remain separate checks.

## Safe build and validation

The target is build-only. It does not search for, open, or write to a USB
device. Use the disposable-worktree builder in
[`../../../tools/build_codex_oai.py`](../../../tools/build_codex_oai.py) and
the complete recipe in [`../../../BUILD.md`](../../../BUILD.md). The builder
requires Vial-QMK commit `00fc4627`, the local VIA pre-hook and Raw HID
Report-ID patches, initialized submodules, and Arm GNU Toolchain 15.2.Rel1. It
publishes only
[`release/firmware/prebuilt/agentpad13_codex_oai.uf2`](../../../../release/firmware/prebuilt/agentpad13_codex_oai.uf2)
after clean builds pass. The current candidate is 93,696 bytes with SHA-256
`fcb50b2419419be43b7cf90b00a96b16063fcaf182bc24b9642d57e2e8adf54d`.

Run the complete host gate from the repository root with
`python3 -m unittest discover -s firmware/tests/codex_oai -p 'test_*.py'`.
The current offline result is bound to the exact release UF2 by the
[`emulator capture`](../../../evidence/codex-oai-emulator.json) and
[`current manifest`](../../../evidence/codex-oai-current-manifest.json).
Neither the builder nor these checks install or flash firmware.

Before any future hardware operation, complete the explicit authorization and
matrix in [`../../../../docs/codex-oai-physical-runbook.md`](../../../../docs/codex-oai-physical-runbook.md).
For the temporary Raspberry Pi Pico bench, use the pin-by-pin jumper guide in
[`../../../../docs/codex-oai-pico-runbook.md`](../../../../docs/codex-oai-pico-runbook.md).
The current host/build/emulator evidence and the still-pending physical matrix
are recorded in
[`../../../../docs/codex-oai-prehardware-results.md`](../../../../docs/codex-oai-prehardware-results.md).

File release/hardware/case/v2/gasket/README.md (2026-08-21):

# Optional PORON ledge-gasket kit — agentpad13 v2

A small, **optional** foam accessory for the v2 band. It adds a gentle downward
preload on the PCB rim by seating user-cut adhesive PORON segments under the
band's rabbet ledge.

> **This is OPTIONAL.** The bare band ledge already sits `+0.3 mm` above the PCB
> top rim and is the sandwich backstop on its own. The gasket only converts that
> `0.3 mm` air gap into a soft, always-in-contact preload. Skip it and nothing
> is wrong.

> **No design geometry changed anywhere.** This kit is a paper/foam accessory
> *derived* from the existing band geometry. Nothing here is ordered from a fab.
>
> **v2.6 update (2026-07-23).** The band's SIDEWALL was thickened (`WALL`
> 2.4 → 3.0, owner order after PCBWay's thin-crescent EQ), so the band STL hash
> changed and the **`36980cc2ff011dc32d923fb04f7429f7` invariance gate is
> RETIRED by owner order** (that hash = the superseded 2.4-wall band; do not
> print it). **This kit is unchanged-valid:** the ledge is INNER-derived and the
> band grew outward only — the rebuild removed zero material and added zero
> material into any mating void, and `gen_gasket.py` re-measures the ledge from
> the new band to the same numbers. `gasket_template.svg` and `.png` regenerate
> byte-identical.
>
> **v2.7 update (2026-07-24) — DEFAULT WALL now 5.4.** Owner decision; the
> shipping band is `agentpad13_v2_band_1.6mm_w5.4.stl`
> (`34be6bf79a6bb81995807448639f4822`), with `_w3.0`
> (`887b2538619db46d63b07cf044762bab`) and `_w7.4`
> (`163669962a928793a4e65347a80e4cfe`) as gated variants. **This kit is
> STILL unchanged-valid, and now for all three walls:** re-run against the 5.4
> band it re-measures the west ledge underside flat run at `x [-0.300, 0.900]
> @ z 0.3` and the ring at `84.8 × 100.6 / 82.4 × 98.2, width 1.2` — the values
> in the table below, unchanged — and `gasket_template.svg` / `.png` regenerate
> **byte-identical** (`527bba7d1ed7b545caed6f37d2197c02` /
> `4568f75a886266aef3597a21d1fd54aa`). `.pdf` / `.dxf` differ only in embedded
> timestamps/GUIDs. The kit is INNER-derived, so it is the same part at every
> wall.

---

## What the ledge is (derived, not invented)

The band's inner wall steps inward over a `+0.3 .. +3.4 mm` z-band to form a
**rabbet ledge** — a `1.2 mm`-wide perimeter ring the FR4 plate drops onto. That
ring is cut in `band()` of `../agentpad13_case_v2.py` from these constants
(read there, never retyped):

| quantity | value | source |
|---|---|---|
| ledge width `LEDGE_W` | `1.2 mm` | `agentpad13_case_v2.py` |
| ledge underside `LEDGE_Z0` | `+0.3 mm` above PCB top | `agentpad13_case_v2.py` |
| band inner wall `INNER_W × INNER_H` (ledge OUTER outline) | `84.8 × 100.6 mm`, R`5.6` | derived `PCB + 2·PCB_CLEARANCE`; R is the FROZEN `INNER_R` (v2.6 — was `OUTER_R − WALL`, pinned so a wall change cannot move the ledge, the plate's R5.4 or the tray's R5.35) |
| ledge INNER outline `INNER_ − 2·LEDGE_W` | `82.4 × 98.2 mm`, R`4.4` | derived |
| PCB outline | `84.2 × 100.0 mm` octagon | `contract_v4.json` |

So the ledge underside is a flat `1.2 mm` ring at `z = +0.3`. The PCB edge sits
`PCB_CLEARANCE = 0.3 mm` inside the band wall, so of that `1.2 mm` strip the
inner **`0.9 mm` overhangs the PCB rim** (the preload contact patch) and the
outer `0.3 mm` hangs over the edge-clearance gap. *(Verified against the actual
band STL: a plane-slice at y=50 / x=25 / x=60 shows the underside is a flat
`z = 0.300` face on all four sides — the code's inner-edge print chamfer was
OCCT-refused and left square, so there is a full flat `1.2 mm` face to bond to.)*

## The compression math

- PORON segment nominal thickness: **`0.5 mm`**
- Gap it compresses into (ledge underside → PCB top): **`0.3 mm`**
- Strain = `(0.5 − 0.3) / 0.5` = **`40 %`**

PORON's useful compression band is ~`20–50 %`, so `40 %` sits in the sweet spot:
a gentle, spring-back preload — not a hard clamp. Contact/preload develops over
the `0.9 mm`-wide strip that overhangs the board rim.

## Material

- **0.5 mm PORON** microcellular urethane foam sheet (any PORON 4701-30 /
  92-class soft grade; generic soft PORON is fine — this is a compliance pad,
  not a seal).
- **Adhesive-backed**: a **3M 468MP / 9471LE-class** (or equivalent) high-tack
  transfer-adhesive backing. Any thin PSA foam tape of `0.5 mm` total thickness
  works.
- **Quantity**: a single `100 × 100 mm` sheet is *many times* more than needed —
  all 10 segments together are only ~`180 mm²` (a `100 × 100` sheet is
  `10 000 mm²`, i.e. **>50× surplus**; buy the smallest sheet sold).

## The segments (10 total)

`~15 mm` long × `1.2 mm` wide (matches the ledge width), placed along the four
sides and **clear of the four corner caps and the USB aperture**:

| side | count | positions (board coords, mm) | strip |
|---|---|---|---|
| West  | 3 | y = 25, 50, 75 | x −0.3 … 0.9 |
| East  | 3 | y = 25, 50, 75 | x 83.3 … 84.5 |
| North | 2 | x = 24.9, 59.3 (either side of the USB) | y −0.3 … 0.9 |
| South | 2 | x = 24.9, 59.3 | y 99.1 … 100.3 |

Corner keep-out = `BOSS_CENTERS ± SOCKET_D` (10 mm around each corner-cap
socket); USB keep-out = the `10 mm` J1 aperture span at x `42.1 ± 5`, plus a
`1 mm` margin. The template draws both keep-outs so you can see why the segments
stop where they do. Segments are all identical — orientation does not matter.

## Cut and place

1. **Print `gasket_template.pdf` at 100% / actual size** (turn OFF "fit to
   page" / "shrink to fit"). Measure the 50 mm scale bar — it must read 50 mm.
2. Lay the PORON sheet over the template (or cut free-hand to the listed size).
   With a sharp **X-Acto / craft knife and a steel straightedge**, cut 10
   rectangles `15 × 1.2 mm`. The width may be trimmed slightly (`1.0–1.2 mm`) —
   err narrow rather than wide so no foam overhangs the ledge inner edge.
   *(Craft-cutter users: `gasket_segments.dxf` has the 10 rectangles in mm.)*
3. **Peel and stick each segment to the BAND ledge underside — NOT to the
   board.** Reach up into the band from the open (tray) side; the ledge is the
   `1.2 mm` shelf `0.3 mm` down from the plate recess. Press the foam flat, its
   outboard edge against the band inner wall, following the side positions
   above. Skip the four corners and the USB mouth.
4. Assemble as normal. The plate/screws set the stack height; the foam simply
   takes up the `0.3 mm` and lightly loads the board rim.

If a segment peels or you want more/less preload, add or remove segments — the
kit is fully reversible and does not affect any fit.

## Files

| file | what |
|---|---|
| `gasket_template.svg` | 1:1 source (mm units); ledge ring + cut rects + scale bar |
| `gasket_template.pdf` | print-ready, exactly 1:1 (page 190 × 250 mm; fits A4 & US-Letter) |
| `gasket_template.png` | raster preview |
| `gasket_segments.dxf` | the 10 cut rectangles only, mm units (craft cutters) |
| `gen_gasket.py` | regenerates all of the above from the case-model constants |

**1:1 provenance.** The SVG declares `width="190mm" height="250mm"` with
`viewBox="0 0 190 250"`, so 1 user unit = 1 mm by construction and the scale bar
is authored at exactly 50 units. The PDF was produced with Inkscape and its page
box was re-measured with PyMuPDF at **190.000 × 250.000 mm** — a 1:1 page, so
any element (the 50 mm bar, the 15 mm segments) prints at true size.

Regenerate: `python3 gen_gasket.py` (needs `inkscape` + `ezdxf` + `pymupdf`;
asserts the band md5 is unchanged before emitting anything).

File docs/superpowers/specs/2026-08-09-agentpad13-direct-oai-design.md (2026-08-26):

# AgentPad13 Direct OAI — Especificación de diseño

> **Especificación histórica:** conserva las decisiones y enmiendas del diseño
> original. Las comparaciones con prototipos previos se han retirado para que
> este documento describa únicamente AgentPad13. El artefacto actual es
> `release/firmware/prebuilt/agentpad13_codex_oai.uf2`, 93.696 bytes, SHA-256
> `fcb50b2419419be43b7cf90b00a96b16063fcaf182bc24b9642d57e2e8adf54d`;
> la validación física sigue PENDING y no hubo flash.

Fecha: 2026-08-09
Estado: propuesta revisada para validación pre-hardware

## Objetivo

Demostrar, antes de que llegue la PCB de AgentPad13, que el hardware puede
ejecutar directamente el software OAI ya validado con la Raspberry Pi Pico:
Codex Desktop hablará con el teclado mediante Raw HID, el teclado
responderá al handshake OAI, emitirá los controles físicos admitidos y
representará en sus 24 LEDs RGB los estados de hasta seis tareas.

No habrá helper entre Codex y el teclado en este experimento.

```text
Codex Desktop
     │  OAI Raw HID directo
     ▼
AgentPad13 codex_oai
     ├── rgbcfg / thstatus / device.status
     ├── AG00..AG05 / ACT06..ACT12 / ENC
     └── 24 LEDs RGB
```

## Ubicación del trabajo

Todo el código, las pruebas, los oráculos Python, la documentación y los
artefactos de validación se guardarán en:

```text
/Users/hirlu/Documents/Projects/agentpad13
```

El checkout `/Users/hirlu/Documents/Projects/vial-qmk` será una fuente de
referencia y el árbol externo de compilación QMK. No será el destino de los
cambios de esta fase.

## Estrategia de aislamiento

Se añadirá un keymap experimental independiente:

```text
firmware/loudest_micro/keymaps/codex_oai/
```

Los keymaps `default` y `vial` de AgentPad13 permanecerán funcionalmente
intactos. El target `codex_oai` desactivará Vial porque el descriptor OAI
experimental no es el descriptor Raw HID/Vial normal de AgentPad13.

El código común solo recibirá guardas de compilación explícitas para permitir
que `codex_oai.c` sea propietario de `raw_hid_receive()` y del overlay RGB en
este target. En cualquier otro keymap continuará activo el protocolo de estado
AgentPad13 de 32 bytes existente.

## Contrato USB experimental

El target local reproducirá el contrato ya observado y validado:

| Campo | Valor |
|---|---|
| VID/PID | `303A:8360` |
| Manufacturer / Product | `hirlu` / `Codex Micro Lab OAI LED` |
| Device version | `0x0005` para distinguir el port AgentPad13 |
| Usage Page / Usage | `FF00:61` |
| Report ID | `6` |
| Tamaño | 64 bytes totales; 63 bytes de datos |
| Canales | debug `1`, RPC `2` |
| Fragmento RPC | máximo 61 bytes |

Esta identidad pertenece a un tercero y se utilizará exclusivamente para la
prueba local. El target no se publicará ni se instalará en hardware sin una
revisión explícita del artefacto y una autorización de flash específica.

## Protocolo OAI

Se portará el motor comprobado de `codex_micro_lab_oai_led` con estas
responsabilidades:

- reassembly acotado de mensajes JSON fragmentados;
- profundidad JSON máxima 8 y buffer RX acotado;
- respuesta exacta a `v.oai.rgbcfg`, `v.oai.thstatus` y `device.status`;
- readiness únicamente después de recibir `rgbcfg` y `thstatus` válidos;
- rechazo silencioso o respuesta acotada para métodos y frames no admitidos;
- emisión de eventos físicos solo cuando el motor está ready;
- conservación de seis slots OAI con color, efecto, brillo, velocidad y flags;
- revisión monotónica del estado para actualizar LEDs solo cuando sea necesario.

No se añadirán métodos inferidos. El contrato seguirá las capturas, fixtures y
tests ya existentes en `codex_micro_lab`.

## Mapeo físico

Las trece posiciones físicas conservan el orden oficial validado por el
prototipo Direct OAI anterior:

```text
AG00   AG01   AG02   AG03
AG04   AG05   ACT06  ACT07
ACT08  ACT09  ACT10  ACT11
2U=ACT12/SEND
```

Controles adicionales de AgentPad13:

- tecla 2U `[3,0]`: `MICROPHONE` mediante press/release `ACT10`;
- click del encoder `[3,1]`: `ENC` press/release;
- touch `[3,2]`: duplicado de `AG00` para verificar el sensor capacitivo;
- encoder CW: `ENC_CW`, `act=2`;
- encoder CCW: `ENC_CC`, `act=2`;
- joystick: permanece enumerado por QMK, pero no se enviarán eventos OAI
  inventados porque el protocolo observado no define controles de joystick.

### Enmienda física 2026-08-18

La placa tiene trece teclas físicas: las doce teclas de la matriz y una tecla
2U separada; el click del encoder y TP5 son controles adicionales. La matriz
conserva `ACT10`/ACCEPT en la tecla 11 (`[2,2]`) y `ACT11` en la tecla 12
(`[2,3]`). La 2U (`[3,0]`) es `ACT12`/`SEND`. El mapa OAI de fábrica
correspondiente es `123456789abfcd1`; el índice interno 12 representa la ruta
2U. El dígito legacy `e` (`MICROPHONE`) sigue aceptándose en mapas
personalizados y se enruta por `ACT10`.

`AG00..AG05` solo emiten su evento de press. `ACT06..ACT12` y `ENC` emiten
press/release. Los giros emiten un único evento `act=2`.

## Arquitectura de LEDs

AgentPad13 dispone de trece LEDs por tecla, un indicador y diez LEDs de
underglow. Se conservarán el RGB, brillo, velocidad y efecto recibidos en
`v.oai.thstatus`; los 24 LEDs de AgentPad13 permiten representar el color sin
codificarlo mediante destellos.

### Distribución

| LEDs | Uso |
|---|---|
| 0–5 | slots OAI 0–5, junto a `AG00..AG05` |
| 6–12 | feedback local de las funciones `ACT06..ACT12` al pulsar |
| 12 | feedback local de la posición 2U `ACT12`/SEND / resumen de tarea activa |
| 13 | handshake: esperando, ready o error de protocolo |
| 14–23 | estado global de la tarea activa mediante underglow |

Un slot invisible —color negro, brillo cero o efecto cero— apaga su LED. La
tarea global se seleccionará con la misma prioridad ya validada: un slot con
efecto working tiene prioridad; en su ausencia se usa el primer slot visible.

### Animaciones

El motor trabajará con aritmética entera y tiempo modular de 32 bits. Portará
la matriz de efectos 0–6 y el patrón working comprobado:

- efecto 0: apagado;
- efecto 1: sólido/patrón determinado por el estado recibido;
- efecto 2: blink;
- efecto 3: ripple;
- efecto 4: breath/working;
- efecto 5: spark;
- efecto 6: beacon.

El patrón azul working especial conservará su triple destello, onda de nueve
pasos, triple destello y pausa. La intensidad calculada se multiplicará por el
RGB original, en vez de producir un único nivel PWM monocromo.

Los LEDs de acción tendrán un feedback corto y local que no modifica el estado
OAI. Al terminar ese feedback volverán al estado base. El underglow reflejará
la tarea global a intensidad reducida y con el mismo reloj de animación.

## Reutilización del software Python RP2040

El código Python existente se empleará como oráculo, no como firmware final de
AgentPad13:

- `rp2040_oai_emulator/oai_engine.py`: framing, reassembly, respuestas y
  eventos OAI;
- `tools/oai_led_lab.py`: selección de slots, efectos, working pattern y
  rollover;
- fixtures `v.oai.rgbcfg` y `v.oai.thstatus`: entradas deterministas;
- tests de paridad existentes: referencia byte a byte frente al C de QMK.

Dentro de AgentPad13 se añadirá una copia mínima y autónoma del oráculo
necesario para que sus pruebas no dependan de otro repositorio. El oráculo
producirá timelines RGB para seis slots y se comparará contra un harness que
compile el C real del nuevo target.

## Archivos previstos

```text
firmware/loudest_micro/keymaps/codex_oai/
  config.h
  rules.mk
  keymap.c
  codex_oai.c
  codex_oai.h
  codex_led.c
  codex_led.h
  README.md

firmware/tests/codex_oai/
  protocol_oracle.py
  led_oracle.py
  protocol_harness.c
  led_harness.c
  test_protocol.py
  test_leds.py
  test_keymap_contract.py

firmware/tools/
  build_codex_oai.py
  verify_codex_oai_artifact.py

docs/
  codex-oai-prehardware-results.md
  codex-oai-physical-runbook.md
```

`build_codex_oai.py` preparará el árbol de build sin escribir en el teclado.
`verify_codex_oai_artifact.py` comprobará target, tamaño, SHA-256, descriptor,
Report ID y símbolos esperados antes de que exista cualquier autorización de
flash.

## Validación antes de recibir la PCB

La fase se considera validada en software cuando pase todo lo siguiente:

1. Pruebas del parser, reassembly, límites, readiness y respuestas OAI.
2. Paridad byte a byte entre el motor C y el oráculo Python.
3. Las quince entradas físicas generan únicamente los controles allowlisted.
4. Los seis slots se proyectan en sus LEDs correctos y conservan RGB, brillo,
   velocidad y efecto.
5. El patrón working y los efectos 0–6 coinciden con el timeline Python,
   incluido rollover de `uint32_t`.
6. El target `loudest_micro:codex_oai` pasa lint y build limpio.
7. Los targets `default` y `vial` continúan compilando sin cambios funcionales.
8. El UF2 arranca en el emulador RP2040, enumera teclado + OAI Raw HID y
   completa el handshake OAI con el descriptor esperado.
9. El verificador genera un manifiesto reproducible con SHA-256 y no contiene
   ninguna ruta de flash implícita.

Los resultados, comandos y logs se conservarán dentro de AgentPad13.

## Verificación física posterior

Cuando llegue la placa habrá un paso separado y autorizado:

1. comprobar identidad física y BOOTSEL;
2. construir de nuevo y comparar el manifiesto aprobado;
3. copiar el UF2 autorizado;
4. verificar enumeración `303A:8360`, `FF00:61`, Report ID 6;
5. observar handshake `rgbcfg + thstatus + device.status`;
6. probar `AG00..AG05`, `ACT06..ACT12`, encoder y touch;
7. comprobar cada slot LED y el underglow con cambios de estado reales;
8. restaurar el firmware AgentPad13 normal al terminar si se desea.

No se flasheará nada durante la implementación pre-hardware.

## Fuera de alcance

- helper Python entre Codex y AgentPad13;
- Vial dentro del target OAI experimental;
- inventar eventos OAI para el joystick;
- modificar PCB, GPIOs o el orden físico de la cadena WS2812;
- publicar la identidad USB experimental de terceros;
- flash, commit remoto o push sin autorización posterior.

## Addendum — 2026-08-18: official ACT11 physical order

The implemented CODEX map uses the official thirteen-action order through
position 12: `AG00..AG05`, `ACT06..ACT12`. Position 13 remains encoder click
and position 14 is retained only for wire compatibility. On the AgentPad13
geometry, matrix key 11 is the protected `ACT10`/ACCEPT route, matrix key 12
is `ACT11` (the second microphone contact), and the separate 2U key is
`ACT12`/SEND. The old `MICROPHONE` action digit is still accepted in custom
maps as a compatibility alias for ACT10.

The wear-leveling schema is version 3. Both earlier factory maps migrate to
`123456789abfcd1`; user-defined maps are preserved. This correction is covered
by the C/Python protocol tests, the keymap contract, a clean pinned-QMK build,
and the RP2040 emulator. No hardware flash has occurred.

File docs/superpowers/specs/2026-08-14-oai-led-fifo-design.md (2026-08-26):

# AgentPad13 OAI LED FIFO Design

> **Historical design record:** this preserves the approved FIFO contract.
> Artifact status from this phase is superseded by
> `release/firmware/prebuilt/agentpad13_codex_oai.uf2` (93,696 bytes, SHA-256
> `fcb50b2419419be43b7cf90b00a96b16063fcaf182bc24b9642d57e2e8adf54d`).
> Physical validation remains PENDING and no flash occurred.

## Goal

Project active OAI tasks on the six task LEDs in first-activation order while
keeping each task's source slot stable in the OAI protocol.

## Approved behavior

- The LED projection is a FIFO queue with a maximum of six entries.
- A newly visible source slot is appended to the tail.
- Updating an already-visible source slot updates its task in place and keeps
  its LED position. Existing animation-reset behavior on task-content change
  is retained.
- Deactivating a source slot removes it and compacts later entries toward LED0.
- Reactivating a previously removed source slot appends it to the tail.
- If all six positions are occupied, activating a new source slot evicts LED0
  (the oldest entry), shifts the remaining entries left, and appends the new
  entry at LED5.
- Firmware restart clears the queue. A new successful OAI RGB configuration
  handshake also clears the queue before the next task snapshot is rendered.
- The task's `source_slot` remains unchanged; only the LED projection order is
  changed. Global-task selection and underglow continue to use the projected
  entries, including the existing preference for a working task.

## Architecture

The FIFO lives in `codex_led.c`, where `tasks_by_led` already represents the
rendered six-position projection. `codex_led_set_tasks()` reconciles the
source-slot snapshot against that projection: remove missing slots, update
survivors in place, then append newly active slots with oldest-first eviction.
No OAI wire format or slot API changes are required.

The OAI parser exposes a monotonically wrapping handshake revision incremented
after each valid `v.oai.rgbcfg` request. The keymap tracks that revision and
calls `codex_led_reset_tasks()` before syncing the first task snapshot after a
new handshake. This handles a repeated handshake even when the task values
themselves are unchanged.

## Data flow

```text
OAI source slots (stable IDs)
        |
        | active snapshot + source_slot
        v
codex_led_set_tasks()
  remove inactive -> update in place -> append/evict
        |
        v
LED0..LED5 FIFO projection -> global/underglow renderer
```

## Error and reset behavior

- Invalid OAI requests do not change the handshake revision or FIFO.
- A valid RGB configuration request increments the handshake revision even if
  the device was already ready; this is the reset trigger.
- A reset empties all six contexts, clears their task values, and sets their
  animation start timestamps to the supplied time.
- Existing link-state, action-feedback, and animation contracts remain intact.

## Tests and acceptance

The C harness and independent Python oracle will cover:

1. first activation order;
2. update-in-place position preservation;
3. removal/compaction and reactivation-at-tail;
4. full-queue oldest eviction;
5. explicit renderer reset;
6. C/Python frame parity for those sequences;
7. handshake revision increment and keymap reset wiring.

The existing host suite, emulator smoke tests, static checks, and pinned
artifact gates must remain green. This change does not authorize flashing.

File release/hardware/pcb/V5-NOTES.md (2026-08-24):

# V5-NOTES — corrected board lineage (started fresh 2026-07-19, evening)

Predecessor v5 attempt discarded in full → `v5-discarded/` (owner order; kept as evidence).
This v5 = **v4_r27 + the RE1 block move**, executed per `hardware/pcb/v4/RE1-MOVE-CHARTER.md`
and the owner's block-shift doctrine (poo3-1/2/3, poo4 — rigid cluster move, straight shears,
bypass pass-throughs, surgical-route only the flagged stubs).

## v5.kicad_pcb — EXECUTION LEDGER (2026-07-19, append-only)

**Base:** `hardware/pcb/v4/v4_r27.kicad_pcb` md5 `af5ad274558fc034d2d098a72d423a25` (verified at load).
**Target (charter §1, MEASURED):** plate file `hardware/case/v2/fab/agentpad13_v2_plate.kicad_pcb`
frame maps 1:1 to board frame (outline 84.4×100.2 rim, M3 circles on boss centers); 13×13 encoder
opening center = **(13.525, 12.5)**. Shaft = RE1 anchor + (7.5, 2.5) ⇒ anchor (13.525,12.5) → **(6.025,10.0)**,
Δ = (−7.5, −2.5).

**Method:** manifest-first block move. Box [11.9,29.2]×[7.6,21.2]; rides = RE1 + all in-box copper of
ENC_A/ENC_B/ENC_SW/GP28/RGB_MCU/+5V + 1 GND stitcher (re-seated (16.96,11.13)→(9.46,9.3));
bypassed (untouched) = GP20, GP21, SW1, RGB_D14, +3V3, GND rest, 3 anchor stubs (ENC_A via
(25.8395,10.6549)+F tail, RGB_MCU vertical (22.9,7.9–11.1), GP28 tip (19.3,7.6)–(19.1,7.8)).
Full clearance sweep (all moved + reconnects vs all static incl. every foreign pad, both layers,
0.152/hole/edge rules) = **0 violations** before any board mutation
(generator: session scratchpad `gen_manifest.py` → `move_manifest.json`).

**Applied (guarded executor `exec_re1_move.py`, pcbnew 9.0.9, assert→mutate→assert):**
- RE1 (13.525,12.5)→(6.025,10.0), rot 0 preserved, stock pads kept (no shrink, no facet)
- SW chamfer leg 14.6→13.2 (3 Edge.Cuts endpoints; owner: asymmetric OK, band+screws move out in case pass)
- J2 DNP set
- 7 whole segs translated; 6 cuts (ENC_B N, ENC_SW E, GP28 N+S, RGB_MCU N+S… see manifest); 5 moved
  cut-parts re-added; +5V west moved-horizontal DROPPED (owner poo3-3) + static stub trimmed to (11.5,19.0238)
- 18 manual reconnect segments (straight shears + computed bows, all sweep-verified)
- Surgical A* (tools_exec3/autoroute.py, all other copper locked): +5V east (21.7,6.0635)→(29.2,8.5635)
  5 tracks + 2 vias; ENC_A rejoin (18.3395,8.1549)→(25.8395,10.6549) 4 tracks + 2 vias (routed after +5V applied)
- 1 fix post-DRC: GP28 rejoin bend (15.55,5.95)→(15.55,5.6) (slot rect corner graze, stadium-model artifact)
- Zones refilled (3), both layers

**Adjudicated contract/referee updates (charter §3 — owner-directed geometry changes, not reverts):**
- `harness/contract_v4.json`: RE1 → (6.025,10.0); chamfer_vertices SW leg → 13.2; status annotated
- `harness/grade_board.py` CHAMFER_VERTS: SW leg → 13.2 (hard-coded product geometry, same adjudication)

**Verification battery:**
- kicad-cli DRC: **0 violations, 0 unconnected**
- Full harness `grade_board.py v5.kicad_pcb --no-ring`: **PASS all gates** — DRC 0, unconnected 0,
  contract 45/45, ABSENT ok, outline 84.2×100.0 chamfer=ok, +5V spine 207 segs min 0.5, USB pair clean,
  TP5 pour 177mm²
- Positional diff vs v4_r27: 126/126 footprints, **only RE1 moved**; DNP delta = {J2} only;
  segments 1100→1132 (+32 = 18 manual + 5 cut-parts + 9 router — matches manifest exactly); vias 178→182 (+4 router)
- Renders: `~/Desktop/v5_before_after.png` (owner-inspected), poo4.png (plan schematic)

## OPEN ITEMS (in order)
1. **Owner render inspection** (renders-before-commit law) — then optional streamline pass
   (ratcheted, keep-iff-better re-grade) on the moved diagonals/rejoins aesthetics.
2. **Fabpack rebuild** from v5.kicad_pcb (`fabpack/build_fabpack.py` + verify 17/17).
3. **⚠️ PCBWay: DO NOT PAY** — order in audit has the OLD encoder position. Owner swaps gerbers
   (+ verify CPL diff empty; RE1 is hand-solder) BEFORE payment. Plate already ordered = correct.
4. Case pass: band/screw stack moves outward for the 13.2 chamfer (owner-approved growth); khana re-run;
   contract cross_check re-adjudication by coordinator.
5. J1 USB-C 180° blocker: still open, next board action after this banks.

## v5_2.kicad_pcb — streamline pass (2026-07-19 evening, owner-directed de-kink)

Owner directive: smooth the kinks, avoid the new vias where possible (v5_fixed.png). Executed as
rip-and-relay of exactly four affected chains (nothing else touched): ENC_A (now ONE clean B.Cu run
pad→via, (6.025,10)→(19,9.2)→(19.5,8.7)→(21.6,8.7)→(25.8395,10.6549), **0 vias**), GP28 (single F.Cu
re-lay (19.1,7.8)→(15.75,17.6)→(15.35,19.65)→(13.5,20.11)→(12.5736,21.2)), RGB_MCU (single F.Cu re-lay
(22.9,11.1)→(19.3,14)→(16.4,18.4)→(16.05,19.9)→(13.5436,21.2)), +5V (A* re-route, 25.7mm).
**Via floor proven, not assumed:** exhaustive A* at via_pen=50 in every routing order — the ENC_A×+5V
corridor crossing is intrinsic (2 vias) and +5V's entry past the static GP20/GP21 B stubs costs 2 more;
total stays +4 vs v4 (same as v5), but ENC_A is via-free and all paths are single clean runs.
Tool fact for the ledger: tools_exec3/autoroute.py requires BOTH endpoints reachable on B.Cu
(THT-era design) — F.Cu-to-F.Cu reconnects (GP28/RGB_MCU) must be hand-laid or the tool reports
"no path"; hand paths verified against slot/S1/SW1-diag/each-other before apply.
Battery: DRC 0/0; full harness --no-ring ALL GREEN (+5V spine 209 segs min 0.5); segs 1126 (v5: 1132),
vias 182. Banked: v5/hardware/pcb/v5_2.kicad_pcb (+.kicad_pro).

## Case-stack finding (2026-07-19, flagged to owner): chamfer 13.2 vs SW boss
Boss slip at leg 13.2 = (13.2−7.4)/√2 − 4.75 = **−0.649mm (interference)**. Options: (1) notch SW tray
boss 0.65 flat (tray reprint only; ORDERED PLATE STAYS VALID) ← recommended; (2) move boss+screws out
~0.95mm (band grows; plate holes+R5.4 corners move → PLATE RE-ORDER); (3) boss OD shrink (rejected,
knife-edge). Decision at CAD pass.

## Independent verification (background agent, 2026-07-19 night) — ALL PASS, FINALIZATION MET
Report: v5/verify_out/VERIFICATION-REPORT.md. Verdicts: electrical parity PASS (503/503 pads, 87 nets
identical, only RE1 moved, only J2-DNP attr delta); plate lineup PASS (ALL 22 plate features Δ=0.000mm
incl. encoder=shaft exact, 13/13 switches, JS1, LED14 viewing hole, STAB1 wings); firmware PASS
(U1 pad→net byte-identical, check_pins 51/51, conformance 80/80, emulator smoke PASS both UF2s,
UF2 SHA exact — ZERO firmware changes needed); CPL byte-identical to v4 (owner uploads ONLY the new
gerber zip); drill/chamfer deltas exact; DRC 0/0. Surprises (non-blocking): 2 spec-label corrections
(plate Ø3 hole = LED14 viewing hole; 6.65×12.3 slots = STAB1 wings); 1 NEW cosmetic severity-all DRC
warning — RE1 silkscreen RefDes clipped by the 13.2 chamfer (electrically nil; optional silk nudge +
fabpack re-run, owner call). **FINALIZATION CRITERIA: parity MET; plate lineup MET.**

## v5_3.kicad_pcb — owner-directed de-jag round 2 (2026-07-19 late night) — SHIPPING BOARD
Owner rejected v5_2's +5V (jagged, 4 vias "not my line"). Proven at 0.025mm exhaustive: owner's 0-via
line is valid ONLY at signal width; at the mandated 0.5mm (+5V spine gate + LED rail) 0-via AND 1-hop
(2-via) are both impossible (F-islands from west and remnant never meet) → 4 vias = true floor at 0.5mm.
Executed: +5V re-laid (same route class), then the NEW LOS shortcut smoothing pass (smooth_pass analyzer:
LOS vertex-collapse per chain vs full obstacle model NOW INCLUDING footprint Edge.Cuts windows — the LED
aperture arcs; first pass without them clipped 11 apertures, caught by DRC, reverted). Final: 26/30 chains
smoothed (segments 262→~225 on touched nets), 4 chains kept original near 2 mis-sampled arcs.
RE1 silk RefDes → (9.5,8.2) (chamfer clip warning cleared). Battery: DRC 0/0, harness --no-ring ALL GREEN.
Fabpack rebuilt from v5_3, verify 17/17, both SKUs. Tool banked: smooth_pass (LOS de-jag, no re-routing) —
candidate for tools_exec3 adoption; MUST include footprint Edge.Cuts in any obstacle model (lesson).

## v5_3 delta re-verification (background agent, 2026-07-19 late night) — ALL PASS, FINALIZATION MET
D1 pad→net parity vs v4_r27 identical (503/503, 87 nets, only RE1 moved, J2-DNP only attr); D2 DRC 0/0,
zones filled, netlist sync exact; D3 CPL byte-identical (no re-upload); D4 shaft (13.5250,12.5000) exact,
Edge.Cuts byte-identical to v5_2; D5 all six smoothed nets = exactly 1 connected component each;
D6 severity-all = 63 = v4 baseline exactly (silk warning gone, zero RE1-referencing items).
Note: agent's "ENC_A 2 vias" = ENC_A's two PRE-EXISTING v4 vias ((25.8395,10.6549),(28.2854,23.4169));
the v5_2/v5_3 ledger phrase "0 vias" meant zero NEW vias on the rejoin. Total 182 = 178 original + 4 (+5V).
**v5_3 FINALIZATION: MET both criteria. Owner action: swap gerbers_v5_3.zip at PCBWay, CPL/BOM unchanged, then pay.**

## ORDER HOLD (owner, 2026-07-20): NO PCBWay upload/payment until J1 is fixed
v5_3 is the verified BASE, not the order candidate — J1 USB-C is still mounted 180° backwards
(mating face points into the board; unbuildable as a product). Sequence: J1 block-move fix (rotate 180°
about anchor + move to (42.1,3.16), face 0.49 proud; CC1/CC2 swap sides, DP/DM mirror in-row; same
manifest→sweep→executor→harness→verify pipeline as RE1) → bank → fabpack rebuild → re-verify →
ONE gerber swap at PCBWay → pay. Supersedes the earlier "swap gerbers_v5_3 and pay" line above.

## v5_4.kicad_pcb — owner's zero-via +5V line, executed (2026-07-19 night) — SHIPPING BOARD
Owner-approved revised_plan_v2: +5V re-laid as ONE all-B.Cu run on the owner's drawn line — west diagonal
truncated at (14.43,12.55), then (18.3,12.55)→(20.525,12.35) THROUGH THE S1/S2 PAD GAP →(23.3,11.7)→
(26.1,10.85) through the widened via-window →(26.9,10.5)→(28.9,9.8)→ tie (30.3,7.4635) on the remnant.
DELETED: all 8 hop segments + ALL 4 VIAS of the old route. ENC_SW: same spot ~1mm lower, beside +5V:
(20.525,15)→(21.6,12.9)→(23.5,12.3)→(26,11.65)→(26.9,11.6)→(28.9,11.3)→(31.6,10.15)→(32.64,9.81), 0 vias.
Enabler: ENC_A's via slid 0.56mm along its own F track (25.8395,10.6549)→(25.79,10.1) + 0.152 F jog —
widens the GP21/ENC_A via window 1.74→2.24mm; all window margins ≥0.15. Guarded executor exec_v54.py
(exact-endpoint rips, count asserts — two aborts caught bad rip windows before any mutation; final rip:
8 segs + 4 vias + 1 truncation + 2 ENC_SW segs). Battery: DRC 0/0; harness --no-ring ALL GREEN.
**Board vias now 178 = EXACTLY v4's count. Net delta vs v4: 0 vias.** Fabpack rebuilt from v5_4.

## v5_4 delta re-verification (background agent) — ALL PASS, FINALIZATION MET
E1 parity identical (503/503; vias 178 = v4 EXACT); E2 DRC 0/0, severity-all 63 item-for-item = v4
baseline; E3 CPL byte-identical; E4 shaft (13.5250,12.5000) exact; E5 +5V/ENC_SW/ENC_A each exactly
1 component, ties carry copper, NO rip stubs; E6 drill census identical to v4 (178×Ø0.2, PTH 223/NPTH 48),
fabpack md5 = board md5. v5_4 = the encoder-fixed board at ZERO routing cost vs v4. J1 fix next.

## J1 fix (v5_5) — PLAN 85% CONVERGED, NOT EXECUTED (2026-07-20, session end — clean handoff)
Board is UNTOUCHED: v5_4 remains the banked, verified baseline. Plan artifacts: `v5/hardware/pcb/j1_plan.py`
(survey + sweep, run against v5_4 — currently 15 violations in 3 knots) + `j1_manifest.json`.
SETTLED by 4 sweep iterations: rotation 180→0 + anchor (42.1,5.1)→(42.1,3.16) (row→y7.205, face −0.49 proud,
verified pad map: A/B pairs same-net, CC1/CC2 symmetric 5.1k Rd → NO firmware/netlist changes); complete rip
lists for CC1/CC2/DP/DM/VBUS approaches (+6 vias ripped incl. 2 legacy DP-hop vias); deterministic re-dresses
verified: CC1 (via under-body), CC2 (under-body to (47.869,0.465)), GP21 (under-body north of the moved pegs,
west descent x40.6), JOY re-jog ((42.7,11.7)→(42.7,8.7)→(43.5,8.6)→(45,10)); ENC_B via relocation to the
vacated strip (east side, (44.4,1.5)); F-under-body is FREE (pads are B-side) — key routing resource.
REMAINING 3 KNOTS (exact): (1) RUN-vs-ENC_B F-parity crossing — RUN's west tie (41.4,8.7) vs ENC_B's F
descent x43.3–44.4: every corridor tried crosses; candidate: RUN via the far-north strip, blocked by the
+5V-F piece (46.226,4.0614)→(48.9302,1.3572) whose CONNECTIVITY after rips is unverified — resolve what its
ends join first; (2) +5V-B U4 approach: KEEP the original vertical (47.2,7.5215→8.0625) (don't rip), bow only
the diagonal ((50.3083,4.4132)→(47.55,6.6)→(47.2,7.5215)); east-peg 0.334-vs-0.402 is a rect-vs-oval model
artifact — let DRC arbitrate; (3) GP21 vs NPTH (39.21,5.76): reroute leg to (38.6,4.6)→(40.3,4.8)→(41.0,6.3).
THE FUNNEL (DM×2/DP×2/VBUS×2 → U4 anchors (46.25,8.0625)/(45.9273,8.9797)+(47.53,8.98)/(45.7808,9.3463)):
interleaved DM-DP-DM-DP row + crossed anchor order forces ≥1 hop (v4 spent 2 vias on DP-A6 here);
plan: surgical A* per net (all endpoints B-side ✓ tool-compatible), order DM-A7(trapped), DP-A6, DM-B7,
DP-B6, VBUS-E, VBUS-W. NEXT SESSION: resolve knot-1 connectivity → sweep to 0 → executor (guarded, pattern
exec_v54.py) → A* funnel chain → refill → DRC → harness --no-ring → USB-pair gate → bank v5_5 → fabpack →
delta re-verify → THEN the single PCBWay gerber swap. ORDER HOLD STANDS.

## v5_5 execution attempt (2026-07-19 night) — ANCHOR RESOLVED, ROUTING WALL — NOT BANKED
**Base:** v5_4.kicad_pcb md5 `8db3e8e972666bbb430fb705110d1740` (.kicad_pro `21155fc0f4eb6f798484edca0e04d403`) —
recorded as the base hash (ledger gap closed; only v4_r27 hash was previously recorded). v5_4 lineage byte-identical/UNTOUCHED throughout.
**Anchor decision (coordinator-approved, 2 escalations):** pure-rotation-to-3.16 both rejected in favor of
**J1 (42.1,5.1,rot180) → (42.1,3.05,rot0)**, face **0.60mm proud**, row y=7.095. Chain: brief said "pure rotation
anchor-fixed 5.1" (face RECESSED 1.45mm — coordinator agreed unbuildable, chose ledger's reach intent); ledger's
3.16 then found INFEASIBLE — J1's tall east shell tab S1(46.42,6.29) top y=7.34 vs U4.4 bottom y=7.40 = **0.060mm,
need 0.152** (hard pad-pad, not routing-fixable). Feasible window anchor≤3.068; 3.05 chosen (gap 0.170, more proud, still reaches aperture).
**TOOL-TRUTH #1 (prior sweep blind spots — successors MUST know):** `j1_plan.py` parses pad geometry WITHOUT
applying pad rotation (U4 is rot 90°, real extent 0.6×1.325 not 1.325×0.6) AND never checks J1 shell-tabs vs fixed
pads. Both bugs hid the S1-vs-U4.4 conflict and gave false +5V-vs-U4 violations. Use kicad-cli DRC as the authority for any rotated-pad clearance.
**TOOL-TRUTH #2 (over-rip discovery):** the prior manifest over-ripped. DRC on rotate-only board proves the TRUE
minimal rip set at 3.05 = 36 segs + 6 vias (CC1 2, CC2 6+2v, DM 5, DP 7+2v, VBUS 8+2v, ENC_B 1 diagonal, RUN 3, JOY 4).
**+5V needs ZERO rip** (all its copper is x≥47.2, east of the connector body — never conflicts; U4.5 stays connected).
**GP21 and JOY-conflict-with-J1 = ZERO** (all F.Cu; J1 pads are B.Cu-only — no cross-layer conflict). JOY still ripped, but only because it BLOCKS ENC_B's reconnection (not a J1 conflict).
**ROUTING WALL (the blocker):** rip+rotate executor verified (assert 36/6). Reconnection routed via FREEROUTING
1.9.0 (java at /opt/homebrew/Cellar/openjdk/26.0.1; full-network keep-wiring, NO subset dialog — mission-sanctioned).
FR achieves **0 DRC violations** on ~95% of the reconnection but CANNOT close 3 connections in any config
(DM cluster→U4.4, ENC_B→stub-via 43.201/8.236, VBUS A9→tie 45.781/9.346) — genuine 2-layer density limit: J1's
16-pad escape + the U4 funnel + the 3 foreign crossers (ENC_B/RUN/JOY, which now traverse the space J1 occupies)
cram a ~6mm band. FR itself logs "finish the board manually." TOOL FACT: the custom A* (tools_exec3/autoroute.py)
is UNUSABLE for clean finishing — original max(hx,hy)-square pads = can't start (over-conservative); bbox-patched =
DRC-DIRTY (821 viol on a full funnel). FR is the only clean router; it leaves the last ~5%.
**ORDER-FLIP EXECUTED (coordinator's hard-first doctrine, 2nd round):** net-filtered FR (strip easy manifest nets →
filter DSN to hard set → FR) placed the 3 HARD nets (DM/ENC_B/VBUS) SOLID through virgin space (0 DRC) — the method
works for the hard nets. BUT the wall SHIFTS not closes: FR leaves ~4 stragglers in EVERY config tried
(plain→DP unrouted; DP-first→DM/ENC_B/VBUS; hard-first→CC1/DP-B6 + RUN/JOY far-copper gaps). Family-resolving the
easy nets (strip+re-FR) DISTURBS their far/perfect copper (RUN/JOY left FAR gaps at U1.26/U1.38, x>60) — NOT minimal.
**FINDING: the reconnection at 3.05 is at/beyond clean 2-layer routability; no FR ordering closes 100%; the last ~4
connections need DISPLACEMENT (settled-element/via nudge to open ~0.2mm) — each is a judgment call.** Best clean
artifacts (both 0 DRC): `wip305_it.kicad_pcb` (3 local gaps, no far disturbance) and `wip305_full2.kicad_pcb`
(hard nets solid + 4 stragglers incl. 2 near-trivial: RUN 0.08mm, JOY 0.8mm). AWAITING coordinator ruling on the
specific displacement levers. NOT BANKED. ORDER HOLD STANDS.

## CASE v2.2 CONVERGENCE + v5_5 ORDER-SET CORRECTIONS (coordinator, 2026-07-19)

Case side is DONE and green against v5 (see hardware/case/v2/CASE-V2-NOTES.md
§12): khana 63/63, tray notched for the 13.2 chamfer (new files
agentpad13_v2_tray_v5.stl/.step), band geometry PROVEN unchanged (re-export
md5-identical to the ordered-geometry STL), EC11 shaft-true gates landed,
usb_recept envelope = the flip ledger (face 0.49 PROUD; x 37.3–46.9,
y −0.49..6.81) with a sign tripwire + section renders as the eyeball gate.

FOR THE v5_5 EXECUTOR — two order-set corrections found this session:

1. **CPL is NOT unchanged for v5_5** (supersedes the earlier "one gerber
   swap, CPL/BOM unchanged" ledger line — that was true for v5_4 only).
   J1 is machine-placed: both SKU CPLs carry `J1 ... 42.100000,-5.100000,
   180.000000,bottom`; after the flip the row must read y −3.16, rot 0.
   build_fabpack derives CPL from the board via kicad-cli, so a REBUILD
   from v5_5 fixes it automatically — but the PCBWay swap must therefore be
   **gerbers + BOTH cpl_*.csv** (BOM genuinely unchanged, same C165948).
   Recommended: add a targeted verify_fabpack assert on the J1 CPL row
   (y=-3.16, rot=0, bottom) — the numeric twin of the render requirement.
2. **contract_v4.json J1 ref still reads y 5.1 rot 180** — adjudicate to
   y 3.16 rot 0 when banking v5_5 or the harness contract check fails.

Also verified case-side, for the record: no bottom-side component bbox
intersects the flipped J1 body region (nearest U4 at y≥7.8, 0.99 clear);
drill-file diff (pegs/NPTH moved with the footprint) stays on the executor's
battery per the named hazard-1.

ORDER GATES (case side): tray_v5 = self-print, no order; band upload file
UNCHANGED and valid, but the band ORDER stays gated on the §12 JS caliper
rule (cage reach toward (80.5,3.7) ≤ 8.1 mm at z≤3.4; height < 3.15) —
a 60-second measurement of the physical PSP-3000 module.

### ADDENDUM (coordinator): 0.60 proud ACCEPTED — bake it
Case-side answer to the executor's pre-bank question: NO tighter max-proud
exists at x≈42 — the band aperture is a through-wall void; 0.60 accepted and
baked into the case (v2.2.1: khana 63/63, band/tray files byte-identical,
renders updated). No re-land needed. Correction to item 2 above: adjudicate
contract_v4.json J1 to **y 3.05** rot 0 (not 3.16 — that was the plan
value; 3.05 is the authorized anchor). CPL rows will read y −3.05.

## JS1 REPLACEMENT — SOURCING RECORD (BOM-ready; coordinator, 2026-07-19)

Owner decision: the PSP-3000 slider (Adafruit 3103 class) is REJECTED (no real
travel + its Ø18.4 disc rides 0.4 into the plate underside per its own drawing
C4812-001). Replacement selected: **YTL YA13 tilt gimbal, default MPN
YA13-FL7.4-B5Ka(45-10)-R-Y06, LCSC C37323742** ($0.456@1/$0.233@1k, 1014 in
stock, machine-placeable by PCBWay from LCSC).

Verified by drawing (local copies in session scratchpad; datasheet
https://datasheet.lcsc.com/datasheet/pdf/14431af5f0bc0c9a36d5b7490e4ae0c6.pdf):
frame 13x13 / bbox 16.7x16.7, body 11.0, stem tip 18.4 (= body 11.0 + free
lever FL7.4), blade top 1.85x1.15, +-30 deg mech (60 deg total), 45+-5 deg
electrical, 2x 5k B +-20%, 100k cycles, stem pull-out >= 3 kgf, pins 6x Ø1.0
(two 3-groups, 2.5 pitch) + 4x Ø1.2 lugs on 10.6x12.5, pin tails ~3.7.
**PIVOT z = 6.1 +- 0.3 above PCB [D]** (1.1 above deck; lever arm to bare tip
12.3) — the sweep-cone input for the case gate.

FOOTPRINT FREEZE: GO. The J13-series base (frame, body, PCB pattern) is
drawing-proven IDENTICAL across variants (YA13 vs YA13S dwg CF-G04-J13-016);
lever length is a reference dim that only moves the stem tip (tip = 11.0+FL).
Shorter levers: NOT commercially available (LCSC carries only FL7.4;
manufacturer publishes no J13 catalog; factory-inquiry only). Owner accepted
FL7.4 height ("couple of keycaps at most").

BOM lines (take effect with the JS1 footprint rev):
- DEFAULT: JS1 = YTL YA13-FL7.4-B5Ka(45-10)-R-Y06, LCSC C37323742,
  machine-placed THT. Nets map 1:1 to existing +3V3/JOY_X/JOY_Y/GND; lugs to
  GND (terminal-frame isolation >=100 Mohm per spec 1.11).
- ALTERNATE 1: YTL YA13S-L7.4-B10Ka(60)-0-DL01, LCSC C37323748 ($0.574, 62
  stock) — SAME core/footprint + integrated tact switch (12V/50mA, travel
  0.3+-0.2); its 4 switch pads extend the pattern to 22.6 wide — NOT in the
  frozen footprint; adopting it needs a footprint extension + spare GPIO.
- ALTERNATE 2 (hand-solder, low-profile): Adafruit 5628 / K-Silver JP19-012
  (+-16 deg, cap+click included) — different footprint, kept as record only.
- DELETED: Adafruit 3103 slider line.
- HOUSE PARTS: printed stick cap (blade-socket 1.85x1.15, sets final height;
  min top ~ +14.2 above deck) + printed encoder knob (Ø>=18 floor) — designed
  as a matched pair. Stock caps: NONE verifiable for the blade; PS4-class caps
  proven INCOMPATIBLE (round Ø4/3.0-flats socket); Joy-Con-class caps
  plausible-unverified (optional $6 caliper test).

Caliper-on-sample list: blade corner radii/tip step (for the printed cap
socket), pivot 6.1 confirmation if any sweep margin < 0.3, Joy-Con cap fit.
Board-side rework scoped on live copper (see js1_pad_swap.png): re-dress
JOY_X/JOY_Y/+3V3 approaches, nudge FB1/C9 ~1mm (W signal column lands 0.55
from FB1 pad), FID2 relocate only if mirrored. RGB_D16 and +5V untouched.

## RELEASE PLAN (owner decision, 2026-07-19): ONE-SHOT v5
Single public release: v5 = J1-flipped board + JS1->YA13 footprint rev +
square-opening plate refab + case v2.3 slice + printed cap/knob, released
together. v5_5 stays an INTERNAL verified checkpoint (no public tag, no
orders from it). Sequence: (1) executor banks v5_5 (in progress — everything
else waits on this); (2) YA13 design pass (task: footprint + FB1/C9 nudge,
plate files, case gates incl. keycap-clearance cone from pivot 6.1, cap+knob
pair); (3) sample caliper confirms; (4) fabpack both SKUs + full checklist;
(5) orders. No PCBWay upload/payment before step 4 completes.
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

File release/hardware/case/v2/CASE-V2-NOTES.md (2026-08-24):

# agentpad13 case v2 — plate-as-deck over the v4_r27 octagon

Built 2026-07-18 against the FROZEN board `hardware/pcb/v4/v4_r27.kicad_pcb`
(md5 `af5ad274558fc034d2d098a72d423a25`, verified this session). The board was
not touched. **Gate: PASS — case 62/62 assertions, coupons 15/15, zero
unexplained interferences.**

Owner directives folded in (2026-07-18, this session, verbatim):
- "Let's go ahead with plate as deck concept"
- Plate outline "ROUNDED RECTANGLE (fillet ~R8 …); final radius is an
  owner-sign-off aesthetic"
- Single-PCB alternative **withdrawn**; locked stack: "a screwed-down FR4
  face-plus-skeleton on top, a floating octagonal brain in the middle, a
  printed chassis with the threads and feet on the bottom — three layers,
  four screws"
- "top case should be able to be 3D printed via FDM (same with bottom case),
  or optionally, top case can be clear/frosted ordered via resin printing.
  Bottom case should be FDM always for heat set inserts" — two printed parts
  total, "the top case looks like a band around the side"
- "we absolutely are NOT copying verbatim the silkscreen from the Work Louder
  product!!" — plate ships **BLANK**; "We'll decorate later separately"
- "the top plate should also sit flush with the top of the case … the top
  case should be countersunk so to speak" — the band carries a rabbet ledge
  the plate drops into, flush at the deck plane

## 0. The product (4 parts + hardware)

| # | Part | Made how | File(s) |
|---|---|---|---|
| 1 | `fr4_plate` — face + switch skeleton, BLANK | ordered, 1.5 mm FR4 | `fab/agentpad13_v2_plate.kicad_pcb` (+`.dxf`), `step/agentpad13_v2_plate.step` |
| 2 | `band` — top case, the visible side wall | FDM PETG **or** resin (frosted default look) | `stl/ step/ agentpad13_v2_band.*` |
| 3 | PCB v4_r27 — floating, never screwed | already ordered (frozen) | — |
| 4 | `tray` — bottom case, all inserts + pins | FDM PETG **always** | `stl/ step/ agentpad13_v2_tray.*` |

Hardware: 4× M3×8 ISO 7380 button-head; 4× standard Voron-style M3×4×5
heat-set inserts (4 mm long, nominal 5 mm OD, Ø4.7 tray cavity) in the tray
only; 4× 3M SJ61A1 bumpons (Ø7.9×2.2,
clear) on the corner-boss bottom faces; 2 mm PORON around sockets
(unmodeled, v1 §10 carry-over); conductive foam pad pending the touch coupon.

**One screw path** (the whole assembly): M3 head proud on the deck → plate
Ø3.2 → band cap Ø4.4 (z +1.5…+3.5) → tray boss insert (bore Ø4.7,
+1.5…−4.2). Plate, band, and tray clamp as one stack; the PCB floats inside
on three press pins (H5/H6/H7) and support bosses — the owner's "it just
sits in its spot" model, verbatim.

**Why no ears.** v1's blocking defect (CASE-NOTES §v1.1) was that Ø9.5
bosses could not pass the old board's R5 corners inside a clean rectangle —
bbox grew to 89.6×129. The v4 octagon's 14.6 mm chamfers are exactly §v1.1's
lever 1 (a coordinated PCB respin): the bosses now live INSIDE the rounded
rectangle, in the voids the chamfers vacate. Case is 89.6 × 105.4 × R8.

## 1. Z stack (desk → keycap; datum z = 0 at PCB top face)

| z (mm) | Interface | Source |
|---:|---|---|
| +6.8 | screw head top (proud button head) | ISO 7380 env (v1 §4 1.8) |
| **+5.0** | **plate TOP = band rim top (flush deck)** | MX shoulder→PCB 5.0, §1 |
| +3.5 | plate underside = ledge top = cap top | plate 1.5 [D std FR4] |
| +1.5 | cap underside = tray boss top (v1 parting plane) | §3 |
| +0.3 | band ledge underside (floats over the PCB rim) | this doc §3 |
| 0.0 | PCB TOP (datum) | contract |
| −1.51 | PCB bottom (real STEP; design datum −1.6) | [S] |
| −3.45 | hotswap socket bottom | §1 SOCKET_DROP |
| −5.10 | cavity floor = tray floor top | §1 UNDER_PCB_CAVITY 3.5 |
| −5.895 | BOOT/RESET tact bottoms → tray service slots | [S] fresh STEP |
| −7.50 | band bottom (FROZEN — `BAND_Z_BOT`; the band is ordered) | §4 |
| **−9.50** | **tray bottom (v2.11 plinth — NO LONGER flush with the band)** | §4 TRAY_T 4.4 |
| −11.7 | desk (SJ61A1 bumpons on boss bottoms) | 3M catalog |

Stack 14.5 mm (band top +5.0 to tray bottom −9.5; the band itself is
still 12.5) + 2.2 feet. Tact bottoms sit recessed 3.6 above the tray bottom
(5.8 above the desk) inside the slots.
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

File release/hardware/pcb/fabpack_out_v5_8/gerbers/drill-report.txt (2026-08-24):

Drill report for v5_8.kicad_pcb
Created on 2026-08-24T15:10:29-0700

Copper Layer Stackup:
    =============================================================
    L1 :  F.Cu                      front
    L2 :  B.Cu                      back

Drill file 'v5_8-PTH.drl' contains
    plated through holes:
    =============================================================
    T1  0.200mm  0.0079"  (181 holes)
    T2  0.300mm  0.0118"  (5 holes)
    T3  0.600mm  0.0236"  (4 holes)  (with 4 slots)
    T4  1.000mm  0.0394"  (19 holes)
    T5  1.200mm  0.0472"  (4 holes)
    T6  1.500mm  0.0591"  (2 holes)  (with 2 slots)
    T7  3.000mm  0.1181"  (26 holes)

    Total plated holes count 241

Drill file 'v5_8-NPTH.drl' contains
    unplated through holes:
    =============================================================
    T1  0.650mm  0.0256"  (2 holes)
    T2  1.750mm  0.0689"  (26 holes)
    T3  2.200mm  0.0866"  (3 holes)
    T4  3.048mm  0.1200"  (2 holes)
    T5  3.988mm  0.1570"  (15 holes)

    Total unplated holes count 48

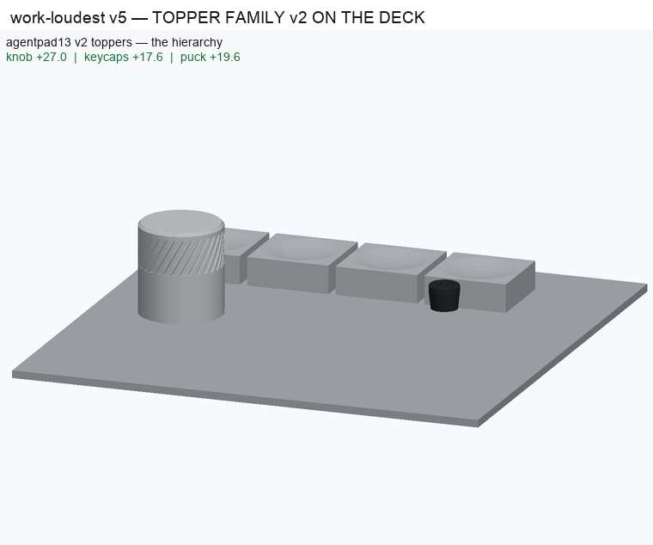
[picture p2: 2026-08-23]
release/hardware/case/v2/toppers/renders/toppers_v2_family_hero.png

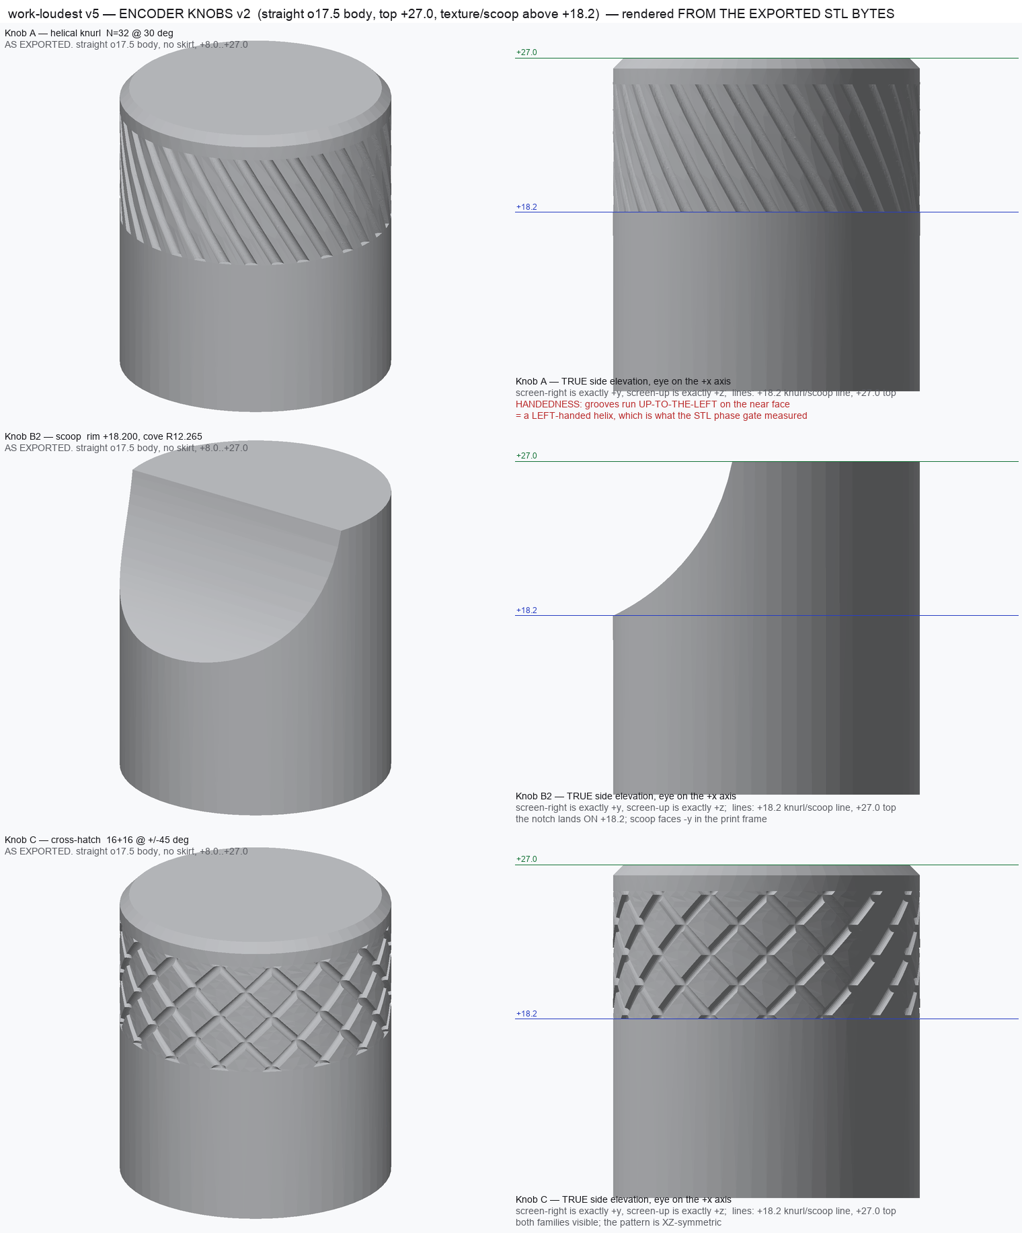
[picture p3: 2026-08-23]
release/hardware/case/v2/toppers/renders/toppers_v2_knobs.png

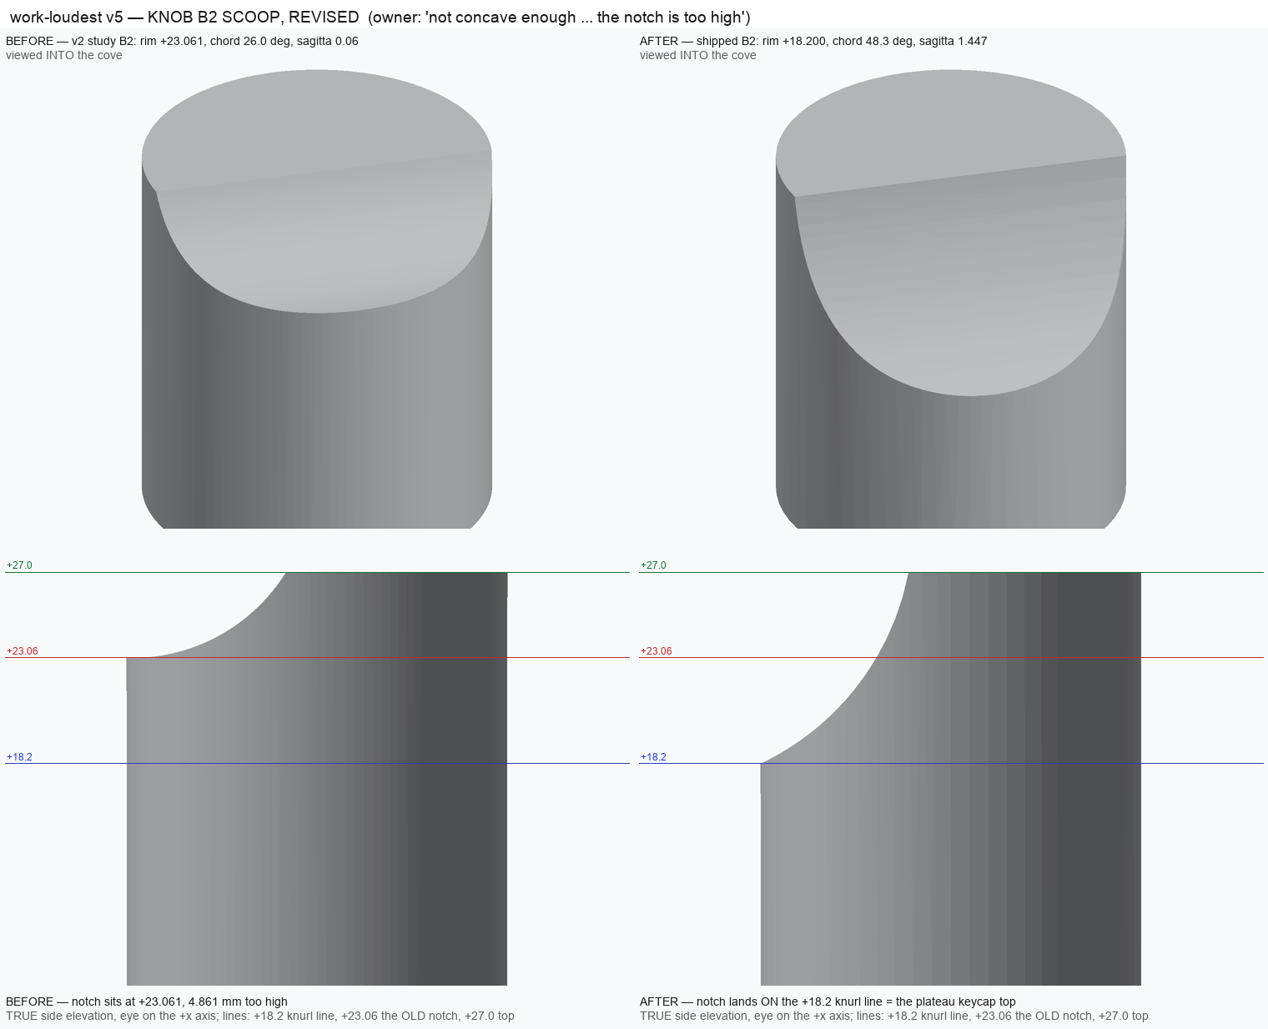
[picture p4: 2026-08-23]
release/hardware/case/v2/toppers/renders/toppers_v2_knobB2_before_after.png

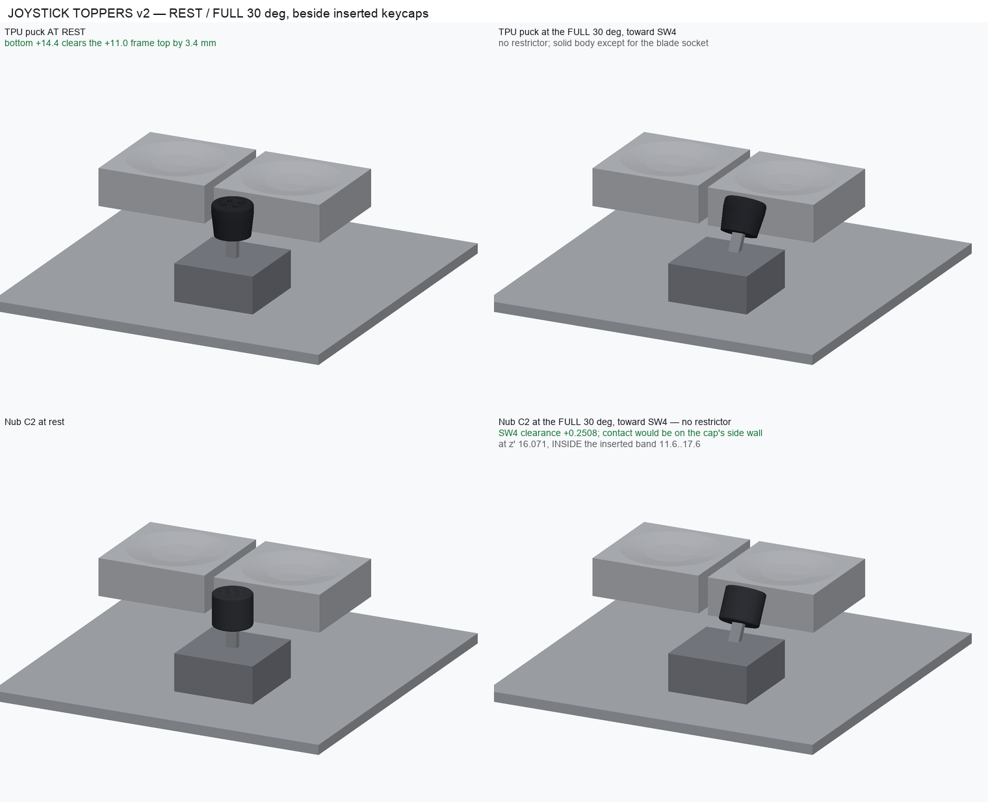
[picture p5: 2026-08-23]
release/hardware/case/v2/toppers/renders/toppers_v2_stick_on_deck.png

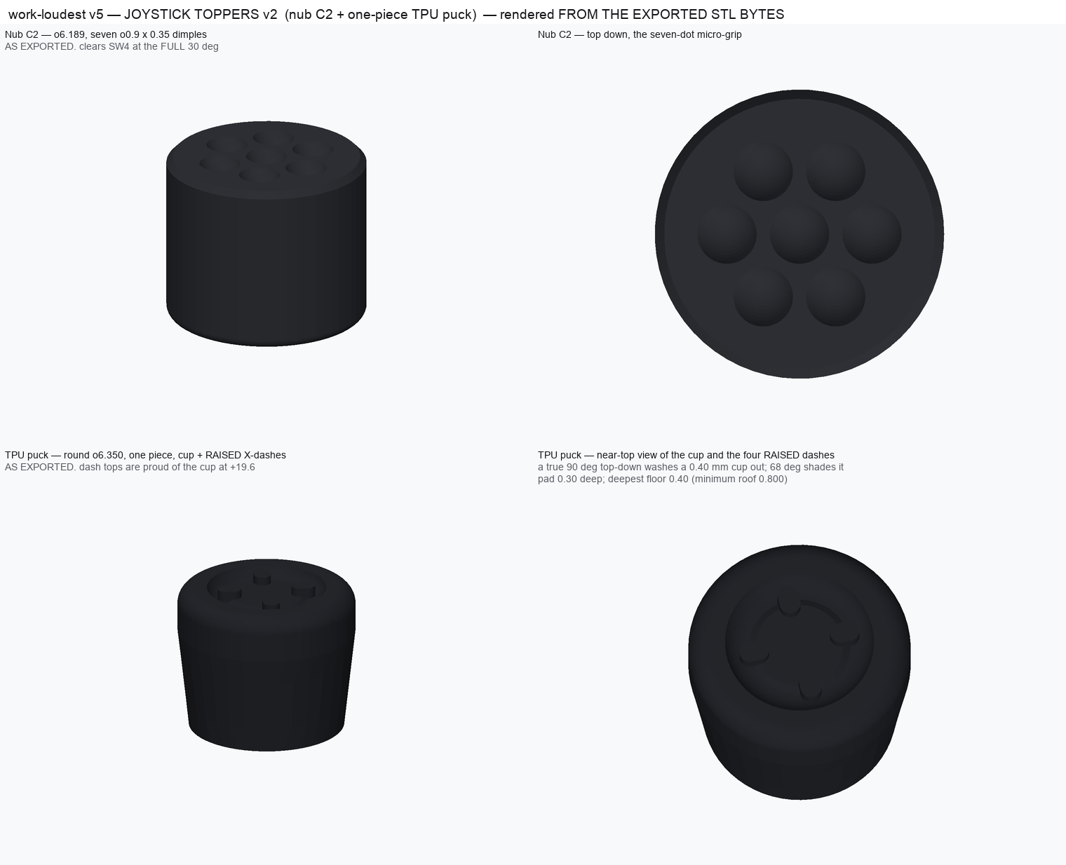
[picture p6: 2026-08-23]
release/hardware/case/v2/toppers/renders/toppers_v2_stick.png

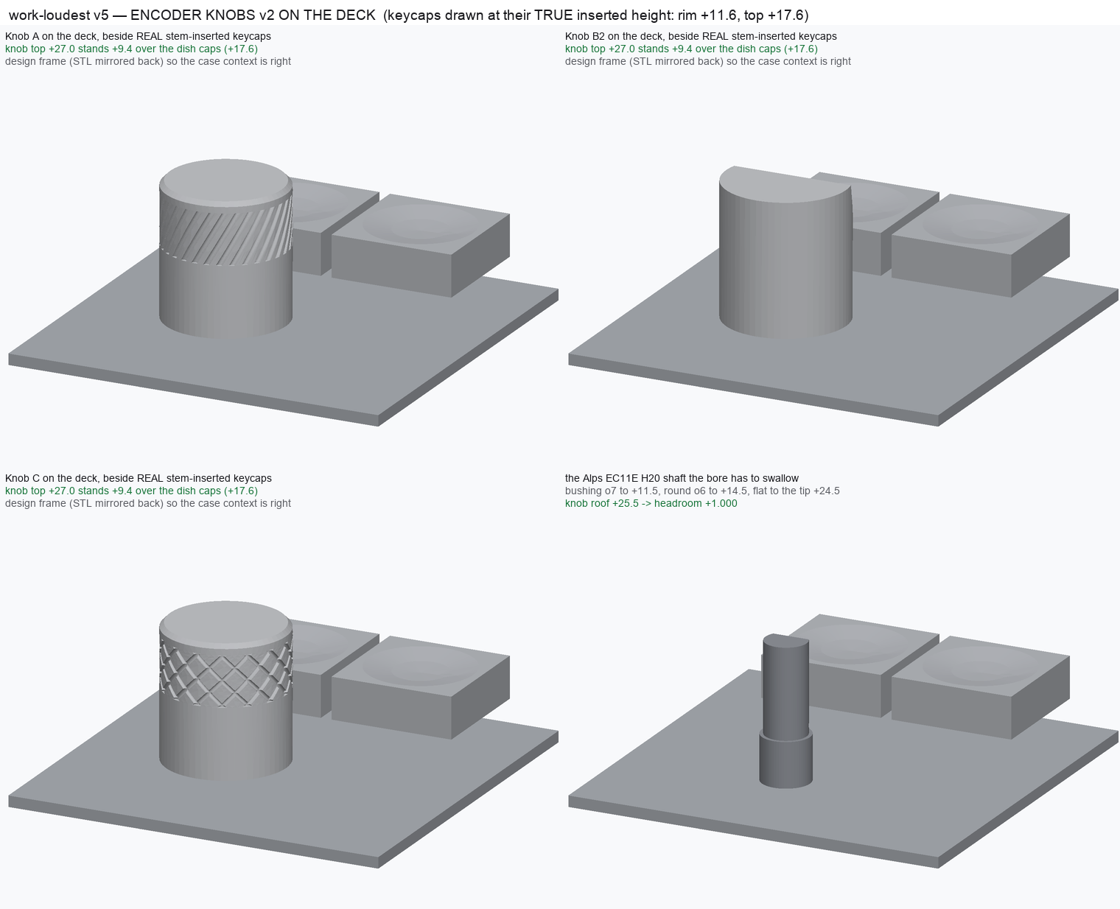
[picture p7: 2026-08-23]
release/hardware/case/v2/toppers/renders/toppers_v2_knobs_on_deck.png

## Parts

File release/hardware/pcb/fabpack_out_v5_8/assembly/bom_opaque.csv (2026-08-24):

References | Qty | Value | MPN | Manufacturer | LCSC | DigiKey | Footprint | Populate | Assembly | Notes
C1,C2,C3,C4,C5,C6,C7,C8,C9,C10,C13,C20,C21,C22,C23,C24,C26,C27,C28,C29,C30,C31,C32,C33,C34,C35,C36,C37,C38,C39 | 30 | 100n 0402 X7R | CL05B104KO5NNNC | Samsung | C1525 | 1276-1003-1-ND | C_0402_1005Metric | Place | PCBWay-SMD | decoupling/bypass/RC; always-populated set (C1-C10 C13 C20-C24 C26-C39)
C11,C12,C14,C15 | 4 | 1u 0402 X5R | CL05A105KA5NQNC | Samsung | C52923 | 1276-1182-1-ND | C_0402_1005Metric | Place | PCBWay-SMD | VREG + LDO in/out
C16,C17 | 2 | 10u 0805 X5R | CL21A106KAYNNNE | Samsung | C15850 | 1276-2892-1-ND | C_0805_2012Metric | Place | PCBWay-SMD | +5V/+3V3 bulk
C18,C19 | 2 | 15p 0402 C0G | 0402CG150J500NT | FH/multi | C1548 | by MPN | C_0402_1005Metric | Place | PCBWay-SMD | crystal load (do NOT substitute value)
C25 | 1 | DNP touch cap | C_0402 | generic |  |  | C_0402_1005Metric | DNP | DNP | touch sensitivity tune; DNP populate if needed
C40,C41,C42,C43,C44,C45,C46,C47,C48,C49 | 10 | 100n 0402 X7R | CL05B104KO5NNNC | Samsung | C1525 | 1276-1003-1-ND | C_0402_1005Metric | DNP | PCBWay-SMD/populate-per-variant | VARIANT: LED15-24 decoupling (C40-C49); populate with underglow, else DNP
D1 | 1 | SD05C TVS | SD05C | PANJIT/multi | C1884584 | by MPN | D_SOD-323 | DNP | DNP | DELTA: DNP for Rev A confirmed; footprint stays; USBLC6 already covers D+/D- ESD
F1 | 1 | 750mA hold | MF-MSMF075/24-2 | Bourns | C208467 | MF-MSMF075/24-2CT-ND | Fuse_1812_4532Metric | Place | PCBWay-SMD | DECISION B bumped from 0.5A; 1.5A trip; 0.45ohm vs 1.0ohm; 15V+ rating
FB1 | 1 | 600R@100MHz | BLM15AG601SN1D | Murata | C76884 | 490-1053-1-ND | L_0402_1005Metric | Place | PCBWay-SMD | DECISION C NEW ADC_AVDD supply filter (RPi Pico pattern)
J1 | 1 | USB-C 2.0 16P | TYPE-C-31-M-12 | Korean Hroparts (HRO) | C165948 | by MPN | USB_C_Receptacle_HRO_TYPE-C-31-M-12 | Place | PCBWay-SMD | official KiCad FP; 16-pin USB2.0
J2 | 1 | 1x08 header 2.54 | PinHeader_1x08 | generic | by MPN |  | PinHeader_1x08_P2.54mm_Vertical | DNP | DNP | DELTA: DNP for Rev A (pads/holes stay); populate later for OLED/sensor/debug
JS1 | 1 | 2-axis tilt joystick | YA13-FL7.4-B5Ka(45-10)-R-Y06 | Shenzhen Yatelian/YTL | C37323742 | by LCSC C# | YA13-FL7.4-B5Ka_C37323742 | Place | PCBWay-THT | tilt joystick, THT, 10 pads; replaces PSP slider
LED1,LED2,LED3,LED4,LED5,LED6,LED7,LED8,LED9,LED10,LED11,LED12,LED13,LED14 | 14 | SK6812MINI-E | SK6812MINI-E | OPSCO/Normand | C5149201 | by MPN | LED_6028R | Place | PCBWay-SMD | reverse-mount per-key + LED14 layer indicator; POPULATED ALWAYS
LED15,LED16,LED17,LED18,LED19,LED20,LED21,LED22,LED23,LED24 | 10 | SK6812-SIDE | SK6812SIDE-A | OPSCO/Normand | C5378721 | by MPN | LED_WS2812_4020 | DNP | PCBWay-SMD/populate-per-variant | VARIANT: translucent top -> populate; opaque top (Rev A default) -> DNP. FP stays permanent. layout must match FP pkg + pin order
R1,R2 | 2 | 5.1k 0402 1% | 0402WGF5101TCE | UNI-ROYAL | C25905 | by MPN | R_0402_1005Metric | Place | PCBWay-SMD | USB-C CC pulldowns (one per pin)
R3,R4 | 2 | 27R 0402 | 0402WGF270JTCE | UNI-ROYAL | C25100 | by MPN | R_0402_1005Metric | Place | PCBWay-SMD | USB D+/D- series (do NOT substitute value)
R5,R6,R11,R12 | 4 | 1k 0402 | 0402WGF1001TCE | UNI-ROYAL | C11702 | by MPN | R_0402_1005Metric | Place | PCBWay-SMD | XOUT/BOOTSEL/joystick RC series
R7 | 1 | 10k 0402 | 0402WGF1002TCE | UNI-ROYAL | C25744 | by MPN | R_0402_1005Metric | Place | PCBWay-SMD | RUN pull-up
R8,R9 | 2 | 4.7k 0402 | 0402WGF4701TCE | UNI-ROYAL | C25900 | by MPN | R_0402_1005Metric | Place | PCBWay-SMD | I2C SDA/SCL pull-ups
R10 | 1 | 0R 0402 | 0402WGF0000TCE | UNI-ROYAL | C17168 | by MPN | R_0402_1005Metric | Place | PCBWay-SMD | AHLB strap (GND=active-high)
RE1 | 1 | EC11 encoder+push | PEC11R-4215F-S0024 | Bourns | C143790 | 4499665 | RotaryEncoder_Alps_EC11E-Switch_Vertical_H20mm | Place | PCBWay-THT | Factory-placed THT alongside JS1; exact MPN only
SW1,SW2,SW3,SW4,SW5,SW6,SW7,SW8,SW9,SW10,SW11,SW12,SW13 | 13 | MX hotswap socket | Kailh CPG151101S11 | Kailh | C41430893 | via KBDfans | SW_MX_HS_CPG151101S11_1u | Place | PCBWay-SMD(back) | DELTA: fab-placed BASELINE (owner: no fine-SMD hand work). Hand-solder alt priced in COST-ANALYSIS ($79.6 vs $81.8/bd qty5). MX-only; Choc path deleted; socket-on-back south-facing
SW14,SW15 | 2 | BOOT/RESET tact | PTS645SM43SMTR92 LFS | C&K | C221880 | CKN9112CT-ND | SW_SPST_PTS645Sx43SMTR92 | Place | PCBWay-SMD | 6.0x6.0mm H4.3 SMT gull-wing 160gf SPST-NO; matches FP SW_SPST_PTS645Sx43SMTR92. 2026-08-04 CORRECTION: prior TS-1187A (C318884) REJECTED by PCBWay component verification - 5.1x5.1mm body / 6.5mm lead span vs 7.96mm pad span (not solderable). DO NOT substitute PTS645SM43JSMTR92 LFS (C2801847) - J-lead, DIFFERENT land pattern. Reachable through case holes
U1 | 1 | RP2040 | RP2040 | Raspberry Pi | C2040 | 2648-RP2040TR | QFN-56-1EP_7x7mm_P0.4mm_EP3.2x3.2mm | Place | PCBWay-SMD | QFN-56 0.4mm pitch; only active with no alt by decision
U2 | 1 | W25Q128JVSIQ | W25Q128JVSIQ | Winbond | C97521 | W25Q128JVSIQ-ND | SOIC-8_5.3x5.3mm_P1.27mm | Place | PCBWay-SMD | 16MB QSPI SOIC-8; 2MB no cheaper so ship 16MB
U3 | 1 | AP2112K-3.3 | AP2112K-3.3TRG1 | Diodes Inc | C51118 | AP2112K-3.3TRG1DICT-ND | SOT-23-5 | Place | PCBWay-SMD | 600mA SOT-23-5 LDO; verify pinout at FP bind
U4 | 1 | USBLC6-2SC6 | USBLC6-2SC6 | STMicroelectronics | C7519 | 497-5235-1-ND | SOT-23-6 | Place | PCBWay-SMD | D+/D- ESD array SOT-23-6
U5 | 1 | SN74LVC1T45 | SN74LVC1T45DBVR | Texas Instruments | C7843 | 296-16972-1-ND | SOT-23-6 | Place | PCBWay-SMD | level shifter ship populated; DIR=A->B
U6 | 1 | TTP223-BA6 | TTP223-BA6 | Tontek/multi | C42422127 | by MPN | SOT-23-6 | Place | PCBWay-SMD | SOT-23-6; old code C80757 not indexed by jlcsearch - verify at order
Y1 | 1 | 12MHz ABM8-272-T3 | ABM8-272-T3 | Abracon | C20625731 | 535-ABM8-272-T3-ND | Crystal_SMD_3225-4Pin_3.2x2.5mm | Place | PCBWay-SMD | LIVE stock 15726

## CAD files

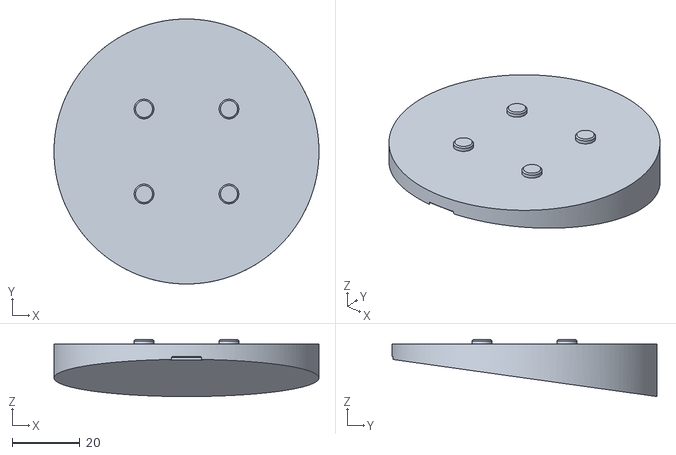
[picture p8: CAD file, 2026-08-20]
release/hardware/case/v2/bases/stl/base_pedestal_peg_5p8.stl
78.0 x 78.0 x 16.8

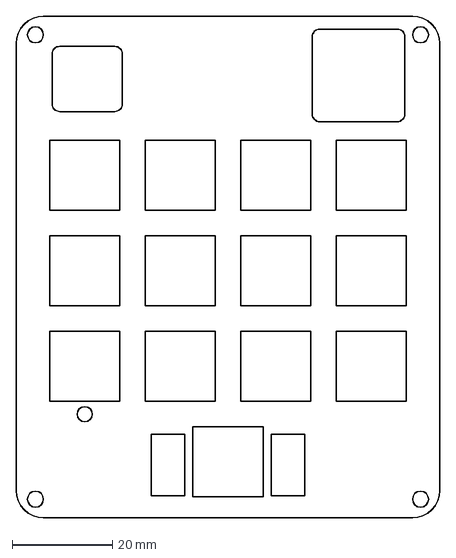
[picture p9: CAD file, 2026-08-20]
release/hardware/case/v2/fab/agentpad13_v2_plate_v5.dxf
84.4 x 100.0 mm

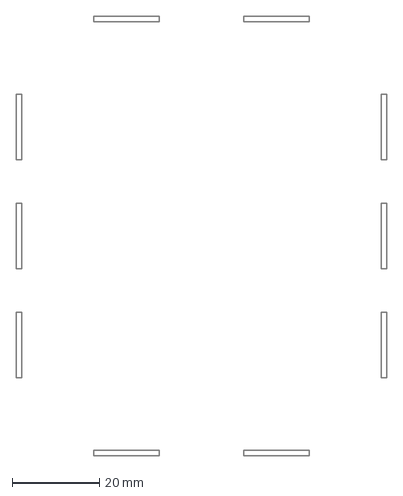
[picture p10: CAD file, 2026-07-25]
release/hardware/case/v2/gasket/gasket_segments.dxf
84.8 x 100.6 mm

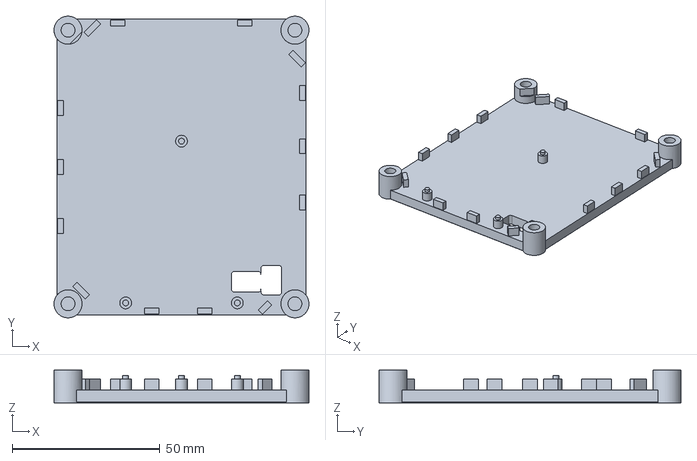
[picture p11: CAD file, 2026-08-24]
release/hardware/case/v2/step/agentpad13_v2_tray_v5.step
86.3 x 102.1 x 11.0 mm

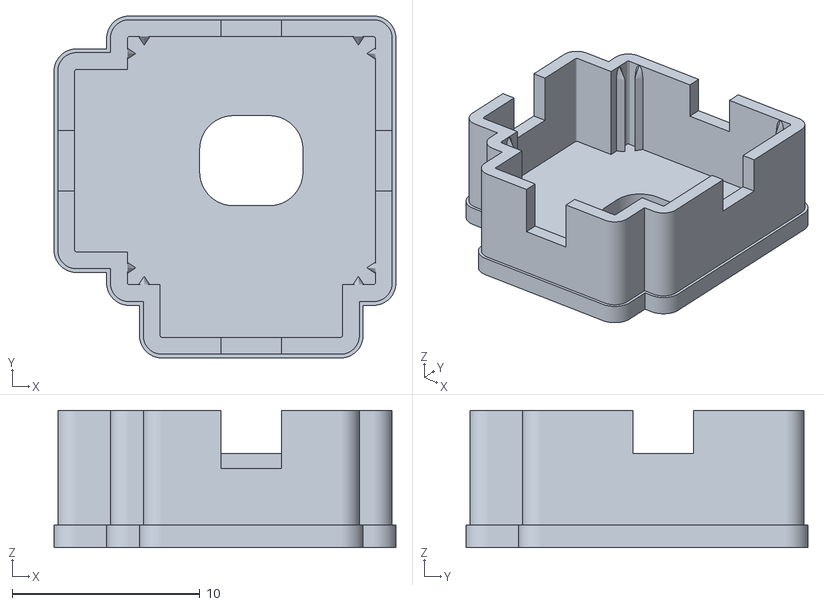
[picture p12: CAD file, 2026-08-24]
release/hardware/case/v2/toppers/stl/ya13_restrictor_cap_TPU_print_roof_down.stl
18.2 x 18.2 x 7.30

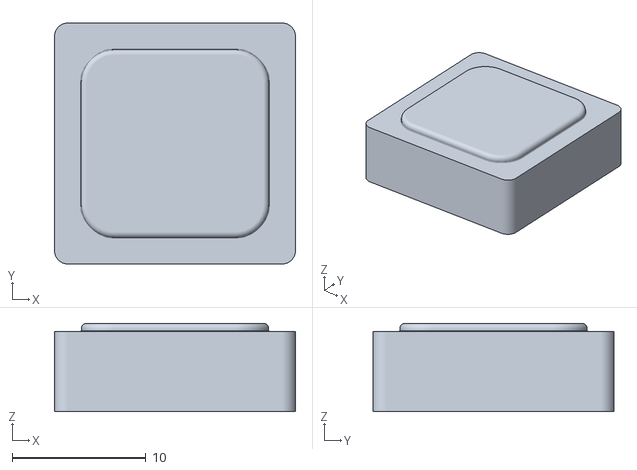
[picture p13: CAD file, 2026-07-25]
release/hardware/PCBWay_keycaps_boxfit_2026-07-24/cap_plateau_1u_boxfit.stl
18.0 x 18.0 x 6.60

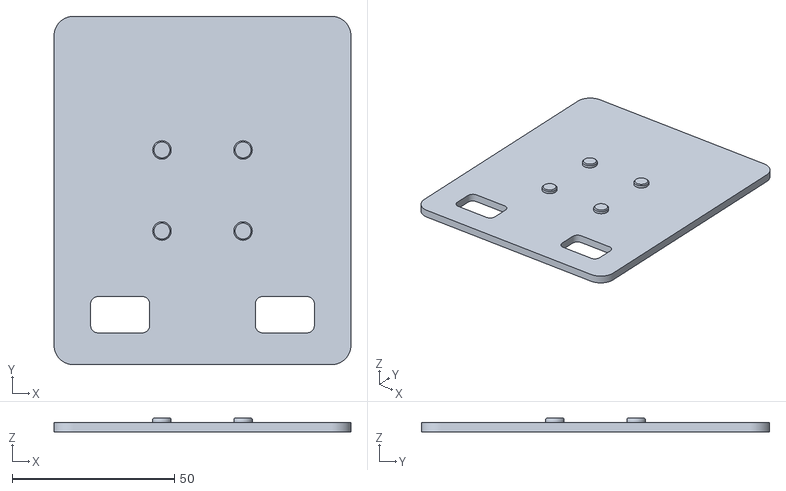
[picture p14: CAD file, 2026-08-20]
release/hardware/case/v2/bases/stl/base_riser_peg_5p7.stl
91.6 x 107.4 x 4.40

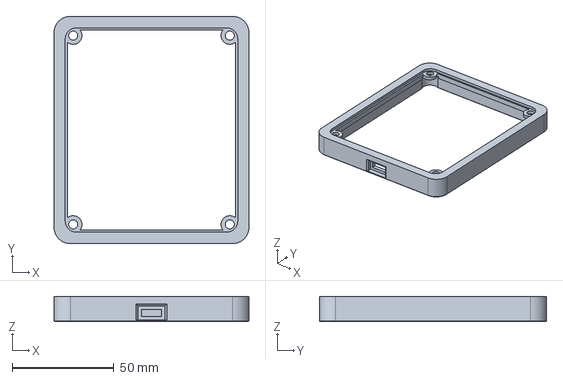
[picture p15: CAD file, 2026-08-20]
release/hardware/case/v2/step/agentpad13_v2_band_1.6mm_w5.4.step
95.6 x 111.4 x 12.5 mm

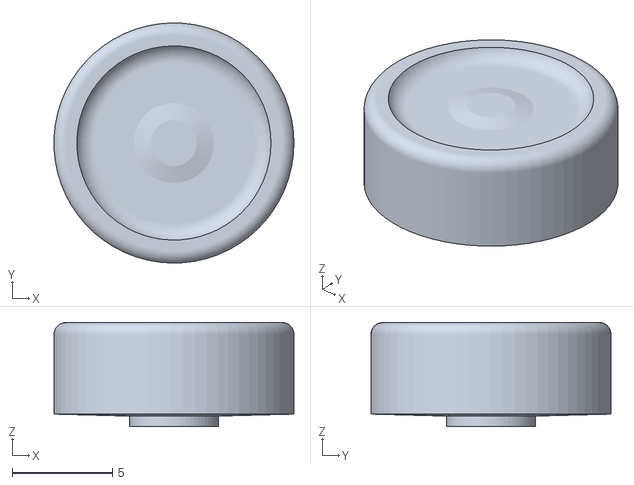
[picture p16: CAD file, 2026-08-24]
release/hardware/case/v2/toppers/stl/stick_topper_v2_restricted_12mm_cell2.stl
12.0 x 12.0 x 5.20

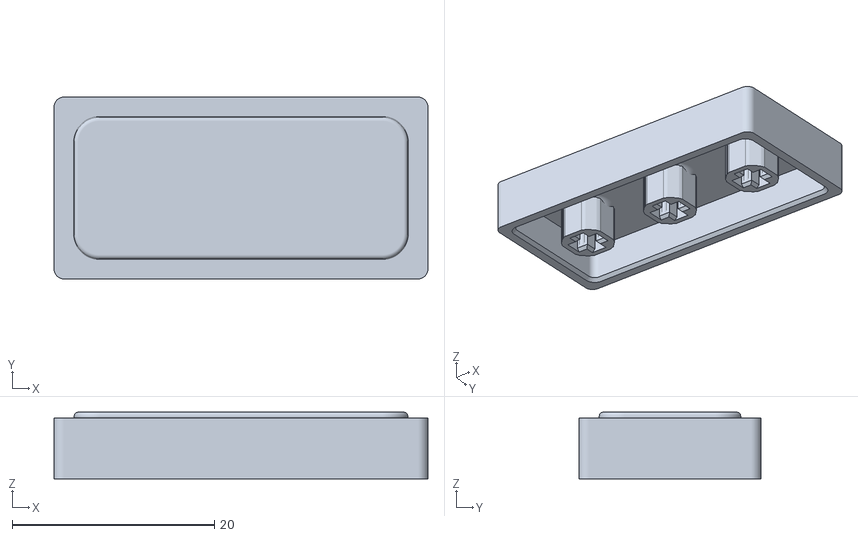
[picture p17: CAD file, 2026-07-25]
release/hardware/PCBWay_keycaps_boxfit_2026-07-24/cap_plateau_2u_stab_boxfit.stl
37.0 x 18.0 x 6.60

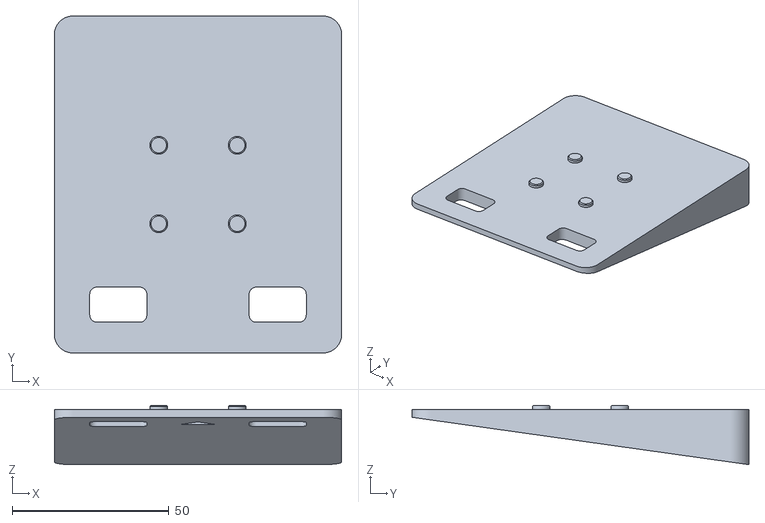
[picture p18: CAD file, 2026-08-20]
release/hardware/case/v2/bases/stl/base_wedge_peg_5p7.stl
91.6 x 107.4 x 18.9

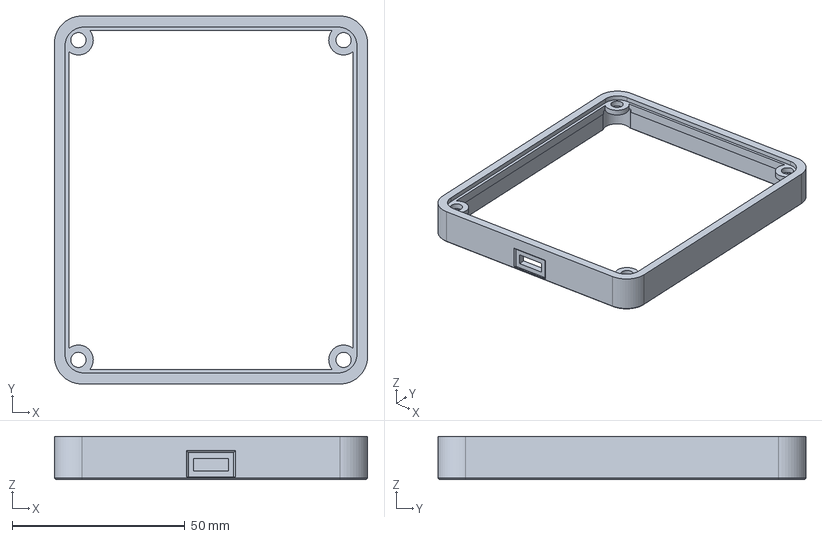
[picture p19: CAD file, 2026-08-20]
release/hardware/case/v2/step/agentpad13_v2_band_1.6mm_w3.0.step
90.8 x 106.6 x 12.5 mm

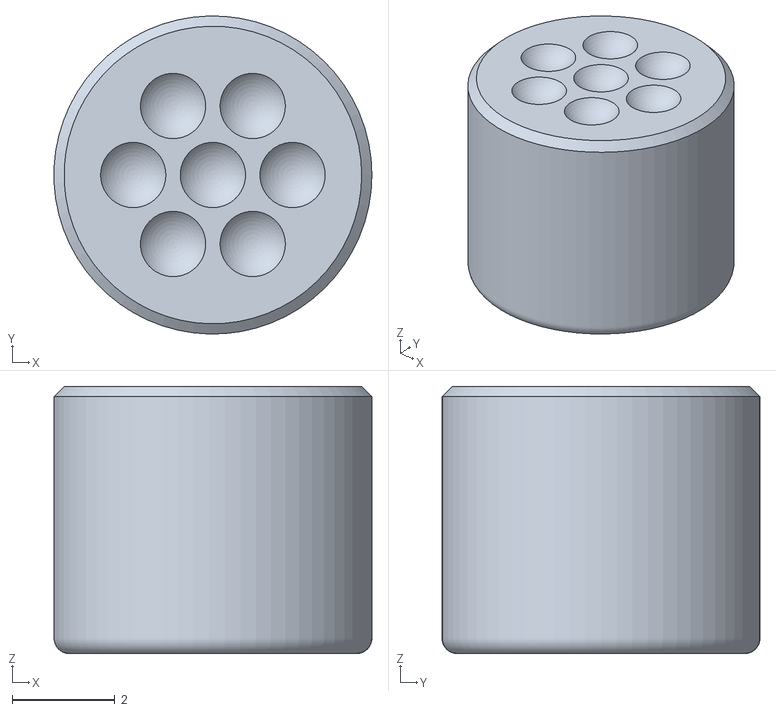
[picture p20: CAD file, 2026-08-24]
release/hardware/case/v2/toppers/stl/stick_nub_v2_C2_cell2.stl
6.19 x 6.19 x 5.20

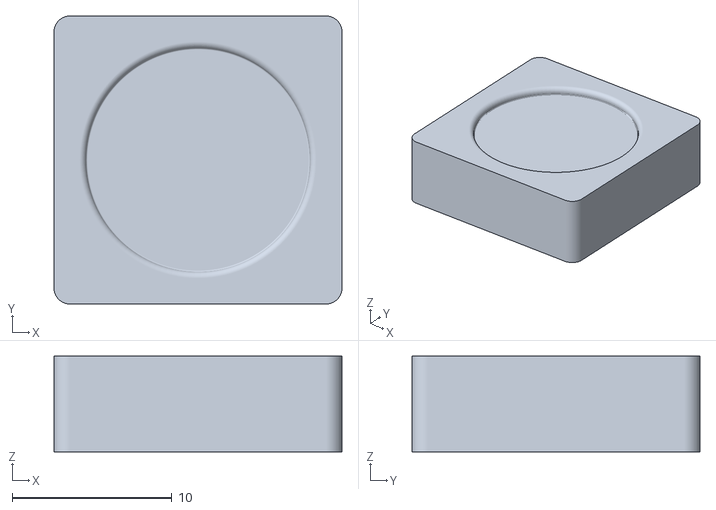
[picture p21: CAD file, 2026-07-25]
release/hardware/PCBWay_keycaps_boxfit_2026-07-24/cap_dish_1u_boxfit.stl
18.0 x 18.0 x 6.00

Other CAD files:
release/hardware/case/v2/bases/stl/base_wedge_peg_5p8.stl
release/hardware/case/v2/step/agentpad13_v2_plate.step
release/hardware/case/v2/toppers/stl/stick_puck_v2_TPU_cell2.stl
release/hardware/PCBWay_keycaps_boxfit_2026-07-24/cap_dish_1u_17p5_boxfit.stl
release/hardware/PCBWay_keycaps_boxfit_2026-07-24/cap_dish_2u_17p5_boxfit.stl
release/hardware/PCBWay_keycaps_boxfit_2026-07-24/cap_dish_2u_boxfit.stl
release/hardware/PCBWay_keycaps_boxfit_2026-07-24/cap_dish_2u_stab_17p5_boxfit.stl
release/hardware/PCBWay_keycaps_boxfit_2026-07-24/cap_dish_2u_stab_boxfit.stl
release/hardware/PCBWay_keycaps_boxfit_2026-07-24/cap_plateau_1u_17p5_boxfit.stl
release/hardware/PCBWay_keycaps_boxfit_2026-07-24/cap_plateau_2u_17p5_boxfit.stl
release/hardware/PCBWay_keycaps_boxfit_2026-07-24/cap_plateau_2u_boxfit.stl
release/hardware/PCBWay_keycaps_boxfit_2026-07-24/cap_plateau_2u_stab_17p5_boxfit.stl
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

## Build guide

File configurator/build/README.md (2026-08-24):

# agentpad13 configurator — legacy build snapshot

The public repository is a consumption release. Its current catalog, viewer
meshes, and printable files are copied from the development repository and
validated as published bytes; the public copy does not regenerate itself.

The scripts in this directory are retained as a legacy implementation record.
They predate the 2026-08-24 joystick refresh and are not current authority for
the published joystick outputs. Do not use `build_all.py`, `gen_catalog.py`, or
`gen_meshes.py` to refresh the public release.

## Historical pipeline components

| stage | writes | gate |
|---|---|---|
| `gen_catalog.py` | `out/catalog.json` | **manifest gate** — every emitted path must be listed in `release/MANIFEST.md` *and* exist on disk; the flash command is parsed out of `BRING-UP.md` and STOPs if it is not there |
| `gen_positions.py` | `out/positions.json` | every value read from a cited source; STOPs rather than guessing |
| `gen_meshes.py` | `out/meshes/*.glb`, `out/meshes/board_top.png` | inputs must be in the manifest; per-mesh volume/bbox and winding gates; texture **chirality gate** |
| `gen_textures.py` | `out/textures/*.png` | the three plate boards must share one Edge.Cuts profile; **loop census**; **orientation gate**; per-variant marker census |
| `gen_costs.py` | `out/costs.json` | emits `{"updated": null, "lines": {}}` and refuses to clobber owner data |
| `check_links.py` | — | every `release/...` path, every fixed build-sheet link, every `meshes/...` and `textures/...` reference resolves, and every plate variant declares a `decal` key |
| `unittest` | — | the full Python suite in `configurator/tests/` |

Optional, needs `matplotlib` (not required by the build):

```sh
python3 configurator/build/verify_chirality.py out/chirality_check.png
```

## Historical environment

The retained snapshot used Python 3.13.7 and the direct dependencies in
`requirements.txt`. This records provenance; it is not a public release
regeneration procedure.

| package | used by | why |
|---|---|---|
| `numpy` | everything | mesh arrays |
| `Pillow` | `gen_meshes.py` | crop the board texture |
| `build123d` / `OCP` (7.9.3.1) | `gen_meshes.py` | tessellate the shipped plate STEP |
| `matplotlib` | `verify_chirality.py` only | optional visual check |

No decimation, glTF or DXF library is required — the QEM decimator and the
glTF 2.0 binary writer are in `meshlib.py`, precisely so that the output stays
byte-deterministic under our own control.

`OCP` pins the plate mesh: OCCT tessellation is deterministic for a fixed
version and fixed deflection, but a different OCCT could retessellate. If
`plate.glb` ever changes without the STEP changing, that is why.

## Handedness — read before touching a transform

The case model's board frame is **left-handed**. That is not an opinion;
`release/hardware/case/v2/agentpad13_case_v2.py:1077` says so:

> The design frame is LEFT-handed (x right, y DOWN from raw KiCad board
> coords, z up) while STL/STEP are right-handed, so every solid exported
> through this path is the ENANTIOMORPH of the intended part.

Two consequences, both load-bearing:

1. **Source STLs are in two different frames.** The tray and the bases are
   mirrored at export (`agentpad13_case_v2.py:2483`,
   `bases/agentpad13_base.py:513`, both `Pos(0, PCB_H, 0) * mirror(part,
   about=Plane.XZ)`), so they contain `y_print = 100.0 − y_board`. The bands,
   the plate STEP, the keycaps and the toppers are exported un-mirrored and
   contain board-frame `y` directly. `gen_meshes.py` applies `M_PRINT` to the
   first group and `M_BOARD` to the second.

   *Verified, not assumed.* The tray's corner-boss notch exists at exactly one
   corner — the board's `(0,0)` corner, the only one with a 13.2 mm chamfer leg
   (`contract_v4.json outline.chamfer_vertices`; the other three are 14.6). In
   the shipped tray STL that notch face lies on the plane `x − y = −87.30`,
   i.e. board-frame `x + y = 12.70`, at the STL corner `(0, 100)`. Board `(0,0)`
   → STL `(0,100)` confirms `y_print = 100 − y_board`.

2. **The board→glTF map must have determinant −1.** `(X, Y, Z)_gltf =
   (x, z, y)_board`. This is *not* the usual Z-up→Y-up rotation `(x, z, −y)`;
   that one is determinant +1 and, applied to left-handed numbers, renders the
   mirror image. `meshlib.transform` reverses triangle winding whenever the
   matrix determinant is negative, and `gen_meshes.emit` then asserts the
   transformed solid still has positive signed volume.

`positions.json` publishes numbers in the **board frame** (so `encoder` is
`13.525, 12.5`, exactly as the case model has it) and carries the `frame` block
with the definition, the handedness and the matrix. The meshes are emitted
already in glTF space, so the viewer never applies a mirror itself.

### The visual check, and its result

`verify_chirality.py` composes the emitted meshes using `positions.json` and
renders three orthographic views. Compared by eye against the shipped renders:

| view | expected | observed |
|---|---|---|
| top-down | USB centred on the far edge, encoder TOP-LEFT, stick TOP-RIGHT, 2U key at the near edge | matches the TOP-DOWN panel of `release/renders/v27_turntable.png` |
| 3/4 iso from the user's side | encoder far-LEFT, stick far-RIGHT | matches `release/renders/v27_hero.png` |
| far wall | USB port centred | centred (`USB_X == CX`, `agentpad13_case_v2.py:1111`) |

`gen_meshes.py` additionally gates the texture: the board plot's top outline
edge must span the 13.2 → 69.6 chamfer and the bottom edge 14.6 → 69.6. Those
legs differ, so the check pins image-top to board `y = 0` and a flipped or
mirrored plot fails the build. Measured: top `13.07..69.71`, bottom
`14.49..69.71` (line-width slop; tolerance 0.35 mm) — **PASS**.

## The plate art — layered, never a baked colour

`gen_textures.py` renders the plate's top face from the three ORDERED boards
(`release/hardware/case/v2/fab/agentpad13_v2_plate{,_tented_ring,_blank}_v5.kicad_pcb`)
in pure Python. It emits **23 KiB** total:

| file | what |
|---|---|
| `textures/plate_openings.png` | 844 × 1000 RGBA, 10 px/mm. White + opaque where the plate is material, fully transparent where the fab routes an opening. **Shared by all three variants.** |
| `textures/plate_decal_standard.png` | transparent except the Ø12 exposed ENIG gold disc over TP5 |
| `textures/plate_decal_tented_ring.png` | transparent except the Ø16 white silkscreen ring, 0.2 stroke |
| *(blank)* | none. `catalog.plate.variants[].decal` is `null` — markerless by design, not a missing file |

**No ground colour is baked in.** The configurator lets the owner pick the
plate's colour (soldermask on the FR4 path, filament or resin on the printed
path), so the ground is the viewer's material tint at runtime and the map
carries only coverage. RGB is written at full strength in every pixel,
transparent ones included, so bilinear filtering cannot bleed black into an
antialiased edge.

The frame is board-frame: image row 0 is board `y = 0` (the FAR / USB edge),
column 0 is board `x = −0.1`. `catalog.plate.openings_map` publishes
`px_per_mm`, `size_px` and `extent_mm` so the viewer can map UVs without
guessing.

### Why not `kicad-cli`

Measured on kicad-cli 9.0.9, not assumed:

* its SVG carries a wall-clock timestamp — two runs differ by exactly
  `<title>SVG Image created as X date 2026/08/20 19:20:02 </title>` — so it is
  not byte-stable without post-processing;
* nothing in the build interpreter can rasterise an SVG (no `cairosvg`,
  `svglib`, `cairo`, `skia`, `resvg`; no `rsvg-convert`, no ImageMagick), so a
  second heavy external tool would be needed on top of KiCad itself;
* and it draws the wrong picture. That export — and the shipped
  `agentpad13_v2_plate_v5_top.png`, which **is** that export — is a fab-check
  plot: white page, KiCad theme colours, the mask layer in magenta. The real
  plate is matte black soldermask with an ENIG gold disc.

Filling the Edge.Cuts contours here instead keeps the pipeline hermetic and
byte-deterministic under our own control — the same argument `meshlib.py`
makes for writing its own glTF.

### Its gates

1. **Edge.Cuts identity.** All three variants must carry the same 89-shape
   profile, re-proved from the boards themselves, before one map is shared.
2. **Loop census.** 1 outline (84.4 × 100.0) + 13 MX cutouts (14.0 × 14.0) +
   2 stab slots (6.65 × 12.3) + 1 encoder opening (14.0 × 13.0) + 1 YA13
   opening (18.45 × 18.45) + 1 layer-indicator hole (Ø3.0) + 4 M3 holes
   (Ø3.2) = **23 contours**. A board that lost or gained an opening fails.
3. **Closure.** An open contour is a `GateError`, never a flood fill.
4. **Orientation.** The plate outline is a symmetric rounded rectangle and
   carries no handedness at all. The layer-indicator hole does: LED14 at
   (13.525, 79.35) is open, and **both** of its mirror images — about the x
   centreline and about the y centreline — land on solid plate. Plus the
   encoder opening open and TP5 solid. A mirrored or flipped raster fails at
   least one of the five probes. Measured: `LED14 hole open (alpha 0); LED14
   mirrored in x solid (alpha 255); LED14 mirrored in y solid (alpha 255);
   encoder opening open (alpha 0); TP5 touch pad solid (alpha 255)` — **PASS**.
5. **Marker census.** Each variant must carry exactly the one marker
   `common.PLATE_MARKERS` claims, or the catalog would describe a plate nobody
   can order.

Determinism is by construction: integer supersampled coverage (4 × 4), integer
averaging, `optimize=False` with a fixed `compress_level`, and PIL writes no
`tIME`/`tEXt` chunk. `test_plate_art.py` runs the generator twice into two
fresh directories and compares sha256, and separately asserts the committed
bytes are what the generator produces.

## Mesh weights

28 `.glb` + 1 `.png` = **3.80 MiB** total. One configured scene (tray, one
band, plate, board, one base, 1U + 2U caps, knob, stick cap) = **1.34 MiB**.

Triangle budgets, chosen so any single scene stays near 45k triangles:
tray 12000 · band/base/plate 6000–8000 · keycaps 6000 · toppers 5000.
Only the keycaps (27k–45k source triangles) and three toppers are decimated;
everything else ships at source resolution. Decimation is gated at ≤5 % volume
change and ≤0.25 mm bounding-box drift.

## Board frame at a glance

```
                 y = 0   FAR EDGE — USB (J1 x=42.1), encoder (13.525, 12.5),
                         stick (69.71, 13.37)
   x = 0  +-----------------------------------------+  x = 84.2
   LEFT   |  SW1   SW2   SW3   SW4      y = 31.70   |  RIGHT
          |  SW5   SW6   SW7   SW8      y = 50.75   |
          |  SW9   SW10  SW11  SW12     y = 69.80   |
          |            SW13 (2U)        y = 88.85   |
          +-----------------------------------------+
                 y = 100  NEAR EDGE (toward the user)

   z = 0 at PCB top · PCB −1.6..0 · plate 3.4..5.0 (deck) · keycap seat 11.6
   tray −9.5..  · band −7.5..5.0 · base mating plane −9.5, peg top −8.1
```

## Notes for the site (contract deltas)

The JSON contract is implemented as specified. Everything below is **additive**
— no specified key changed name, type or meaning.

* `catalog.board`: `gerbers`, `assembly.*` (HOW-TO-ORDER §2 uploads the
  gerber zip and the BOM/CPL separately from the fabpack), `outline_mm`,
  `thickness_mm`, `mesh`, `texture`.
* `catalog.plate`: `mesh`, `stl`, `step`, `dxf`, `size_mm`, `thickness_mm`; each
  variant also carries `kicad_pcb`. One mesh serves all three variants — they
  share one Edge.Cuts profile (`CASE-V2-NOTES.md` §14, "ALL GATES PASS (3/3
  variants)").
* `catalog.band`: `default` (`w5.4`, HOW-TO-ORDER §4), per-width
  `step` and `wall_mm`.
* `catalog.bases`: `interface`, `default_peg` (`5p8`, `INTERFACE.md:41`),
  `peg_rungs`.
* `catalog.toppers`: `bores` / `socks` maps (the fit ladders, mirroring how
  `bases.items[].pegs` works) alongside the single `stl`, which points at the
  documented starting rung `nom` (HOW-TO-ORDER §8); `default` flags the
  shipped default parts (`A` knob / `nub_C2`).
* `catalog.keycaps.files[]`: `width_mm`. `catalog.firmware`: `polarity_doc`.
  `catalog.docs`: `how_to_order`, `release_notes`, `base_interface`.
* `positions.json`: `frame`, `mesh_placement`, `pcb`, `stabilizer`, `base`.

### Round 2 (also additive — no round-1 key renamed, retyped or removed)

* `catalog.firmware.flash` — the `dd` command, parsed verbatim out of
  `release/firmware/BRING-UP.md` (Step 1, the "This always works" block), plus
  `flash_source` naming the line. This retires the hardcoded `FLASH_FALLBACK`
  constant in `site/sheet.js`; a test asserts the two agree today and
  `gen_catalog` STOPs rather than falling back if the doc loses the command.
* `catalog.plate.openings_map` and `catalog.plate.variants[].{marker, decal,
  marker_note}` — see "The plate art" above.
* `positions.bases` — per-variant tilt, desk plane, hinge line, plan
  silhouette and mesh. **And** `positions.base.tilt_deg`, the plain
  `{id: degrees}` map `site/viewer.js:255` already reads. Both come from one
  computation, so they cannot disagree.
* `positions.touch_pad` — TP5 centre, the Ø14/Ø14/Ø8 electrode stack, and the
  per-variant marker (Ø12 exposed disc / Ø16 silk ring / none). Every diameter
  is measured off the ordered boards.
* `positions.screws` — the four Ø3.2 corner holes at (3.7, 3.7), (80.5, 3.7),
  (3.7, 96.3), (80.5, 96.3) with the M3×8 **ISO 7380 button head** envelope
  (Ø5.7 × 1.8, proud on the deck — *not* a socket-head cap).
* `positions.stab` — the two slots as rectangles (6.65 × 12.3 at
  (30.162, 89.47) and (54.038, 89.47)). **And** `positions.stabilizer.slot_size`
  / `.slots`, additive inside the round-1 object. One computation again.

**One published parameter disagreement is recorded, not hidden:**

`bases/params/agentpad13_base_params.json` lists `base_height_mm: 17.49`
for the **pedestal**, which is the wedge's full-footprint figure inherited
unchanged. The pedestal's own solid is **15.428** tall below the mating plane,
because its Ø78 plan never reaches the far edge. The geometry-derived value is
published and it matches the shipped STL.

**2U stabilizer rule.** `keycaps.counts` publishes both valid mixes:

* `counts` = 12 × 1U + 1 × 2U without a stabilizer.
* `counts.with_stabilizer` = 12 × 1U + 1 × 2U-stab when the optional 2U
  plate-mount stabilizer is fitted, exactly as HOW-TO-ORDER §7 specifies.

The slots themselves are measured from all three shipped plate boards. Public
`CASE-V2-NOTES.md` §8 item 6 keeps the real-stabilizer coupon fit check open.

## Note for this public tree

The shipped site runs entirely off the committed `build/out/` data. The public
pipeline regenerates it from the shipped release artifacts and public source
files in this repository; it does not call a keycap, case, plate, or board CAD
generator. `gen_meshes.py` only tessellates the shipped plate STEP and converts
the shipped STL files to viewer GLBs. Everything the site serves, links to, or
puts on an order sheet is public and checksummed.

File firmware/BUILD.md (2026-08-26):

# agentpad13 — firmware build guide

Reproducible build of the agentpad13 Rev A firmware (RP2040) against the Vial
fork of QMK. This directory (`firmware/loudest_micro/`) is a **drop-in QMK
keyboard tree** — it is copied into `vial-qmk/keyboards/loudest_micro/` and
compiled there. (`loudest_micro` is the project's QMK keyboard/module name;
the product and all user-visible strings are **agentpad13** — see
`loudest_micro/readme.md` for why the internal name stays.) Only the keyboard
tree, this guide, the core patches in `patches/`, the validation tools
(`check_pins_v4.py`, `tests/conformance/`), and the prebuilt `.uf2`s under
`release/firmware/prebuilt/` live in the repo; the multi-gigabyte vial-qmk
checkout does not.

Status: **both keymaps compile to a clean `.uf2` with zero code warnings**
(`-Werror` is on). No features were stubbed — the joystick, RGB status
protocol, touch toggle, encoder map, Vial + VialRGB, and joystick modes are
all real code. The pin map targets the **current public board
`release/hardware/pcb/v5_8.kicad_pcb`** (v5_8, md5
`8c32ff4a6e6d77a87c4584029d4a1c75`). The map was re-verified 20/20 GPIO against
v5_6; v5_8 retains the v5.7 LED20/LED21 correction and changes only the TP5
solder landing, with zero pin-map changes. `check_pins_v4.py` (below) embeds the definitive table and
asserts this tree against it. Board revision details and the v5_6-to-v5_8 deltas
are in `release/hardware/pcb/V5-NOTES.md` and `release/RELEASE.md` rows M and R.

---

## 1. Toolchain (versions actually used)

| Tool | Version | Notes |
|---|---|---|
| macOS | 15 (Darwin 25.4, arm64) | |
| QMK CLI | 1.2.0 | `pip install --user qmk` |
| Python | 3.12 | |
| vial-qmk | branch `vial`, commit `00fc4627` | + 1 small core patch, see §2 |
| arm-none-eabi-gcc | **Arm GNU Toolchain 15.2.Rel1** (gcc 15.2.1) | official Arm build, self-contained (bundles newlib) |

### 1.1 Toolchain install — and the blocker we hit

`brew install --cask gcc-arm-embedded` and `brew install arm-none-eabi-gcc`
both have pitfalls on a non-interactive machine; here is exactly what happens
and what works:

* **`brew install --cask gcc-arm-embedded` → BLOCKED without a TTY.** The cask
  downloads the official Arm `.pkg` but runs the Apple installer under `sudo`,
  which needs an interactive password (`sudo: a terminal is required…`). The
  download still lands in Homebrew's cache.
* **`brew install arm-none-eabi-gcc` (formula) → COMPILES BUT CANNOT LINK C.**
  The bottled formula (gcc 16.x) installs the compiler **without** the newlib C
  library/headers, so the very first QMK object fails with
  `fatal error: stdint.h: No such file or directory` (a bare `include_next`).
  gcc 16 is also newer than QMK targets.
* **What works (no sudo):** extract the official Arm `.pkg` that the cask
  already cached, into a user directory, and put its `bin/` on `PATH`:

  ```bash
  PKG="$HOME/Library/Caches/Homebrew/downloads/"*arm-gnu-toolchain-15.2*darwin-arm64-arm-none-eabi.pkg
  pkgutil --expand-full $PKG /tmp/armgnu_expand           # no sudo needed
  mv /tmp/armgnu_expand/Payload ~/arm-gnu-toolchain       # any user-writable dir
  export PATH="$HOME/arm-gnu-toolchain/bin:$PATH"
  arm-none-eabi-gcc --version   # -> Arm GNU Toolchain 15.2.Rel1
  ```

  (With a normal desktop session, `brew install --cask gcc-arm-embedded` works
  too — it just prompts for your password once. The extracted tree is the same
  official toolchain, minus the sudo step.)

## 2. Set up the QMK build tree

```bash
pip install --user qmk                          # qmk 1.2.0

# Clone the Vial fork somewhere outside this repo, at the pinned commit:
git clone --branch vial https://github.com/vial-kb/vial-qmk.git
cd vial-qmk
git checkout 00fc4627
qmk config user.qmk_home="$PWD"
qmk git-submodule       # chibios, chibios-contrib, pico-sdk, printf, lufa, ...
                        # (lufa IS required: ChibiOS USB descriptors use its headers)

# Apply the one core patch (see §6 for what it does and why):
git apply /path/to/agentpad13/firmware/patches/0001-via-command-kb-backport.patch

# Drop our keyboard tree in:
cp -R /path/to/agentpad13/firmware/loudest_micro keyboards/loudest_micro
```

> **Do not skip the patch.** Without it the vial build still compiles, but
> VIA silently swallows the agent-status protocol (IDs 0x01–0x04). The
> checker below fails loudly on an unpatched tree.

## 3. Build

```bash
export PATH="$HOME/arm-gnu-toolchain/bin:$HOME/.local/bin:$PATH"

qmk compile -kb loudest_micro -km default       # -> loudest_micro_default.uf2
qmk compile -kb loudest_micro -km vial          # -> loudest_micro_vial.uf2
```

Both drop a `.uf2` in the vial-qmk root. Prebuilt copies live in
`release/firmware/prebuilt/` (SHA-256 hashes in `firmware/FIRMWARE-V4-NOTES.md`) —
**note the shipped names differ from the build output** *(renamed 2026-08-15)*:

| build | emits | ships as |
|---|---|---|
| `-km vial` | `loudest_micro_vial.uf2` | **`release/firmware/prebuilt/agentpad13.uf2`** — the one users want |
| `-km default` | `loudest_micro_default.uf2` | **`release/firmware/prebuilt/agentpad13_reference.uf2`** — the byte-reproducible reference |

### 3.1 Validate

```bash
# 1. Static pin-map check against the board's per-GPIO table (mandatory
#    before flashing anything new). --qmk-info additionally checks the
#    resolved build config; --qmk-home verifies the §2 patch was applied.
qmk info -kb loudest_micro -f json > /tmp/info.json
python3 firmware/check_pins_v4.py --qmk-info /tmp/info.json --qmk-home /path/to/vial-qmk

# 2. Protocol conformance (v0 + v1 since 2026-08-15): compiles the real
#    firmware handler on the host and drives it with frames built by the
#    vendored host wire-format oracle. Contract: docs/PROTOCOL-V1-CONTRACT.md.
python3 firmware/tests/conformance/run_conformance.py

# 3. QMK lint
qmk lint -kb loudest_micro -km default --strict
```

> `qmk lint -km vial` prints **“The keymap vial should not exist!”** — this is
> a mainline-QMK lint rule (`INVALID_KM_NAMES = ['via', 'vial']`) that every
> Vial keyboard trips. It is a false positive here; Vial's own CI uses
> `util/ci_compile_vial_keyboards.py`, not `qmk lint`, for `vial` keymaps. The
> `default` keymap passes `--strict`, and the `vial` keymap compiles cleanly
> (which means `vial.json` was parsed and embedded).

There is also a full-image smoke test that boots the real `.uf2` in the
rp2040js emulator (pin muxing, WS2812 activity, USB enumeration, key scan,
raw HID PING→CAPS):

```bash
cd firmware/tests/emulator
./get-bootrom.sh && npm install
npm run smoke:default && npm run smoke:vial     # -> EMULATOR SMOKE: PASS
```

Recorded results and the emulator-fidelity caveats are in
`firmware/FIRMWARE-V4-NOTES.md` §4d.

### AgentPad13 Direct OAI (experimental alternative)

`loudest_micro:codex_oai` is isolated from the normal default/Vial firmware.
It uses the locked product string `Codex Micro Lab OAI LED`, USB `303A:8360`,
Raw HID usage `FF00:61`, Report ID 6, and 64-byte reports. Codex Desktop talks
to it directly: there is no helper, daemon, bridge, Vial protocol, or Vial
configuration route. The normal recommended firmware remains
`release/firmware/prebuilt/agentpad13.uf2`.

The repository builder requires exact Vial-QMK commit
`00fc4627cd038ac9b7e9b8bf2b40b50e9e88aecb`, initialized recursive submodules,
and Arm GNU Toolchain 15.2.Rel1 (gcc 15.2.1). It verifies the repository-owned
`patches/0001-via-command-kb-backport.patch`, applies or verifies
`patches/0002-raw-hid-report-id-chibios.patch`, checks their pinned digests, stages
the keyboard through a temporary link, builds `default`, `vial`, and
`codex_oai`, and publishes only the OAI UF2:

```sh
python3 firmware/tools/build_codex_oai.py \
  --qmk-home /path/to/disposable/pinned-vial-qmk \
  --clean
```

The current output is
`release/firmware/prebuilt/agentpad13_codex_oai.uf2`, 93,696 bytes, SHA-256
`fcb50b2419419be43b7cf90b00a96b16063fcaf182bc24b9642d57e2e8adf54d`.
Run the complete host and emulator gates from the repository root:

```sh
python3 -m unittest discover -s firmware/tests/codex_oai -p 'test_*.py'
cd firmware/tests/emulator
npm ci
npm run smoke:codex-oai
cd ../../..

python3 firmware/tools/verify_codex_oai_artifact.py \
  --uf2 release/firmware/prebuilt/agentpad13_codex_oai.uf2 \
  --elf /path/to/disposable/pinned-vial-qmk/.build/loudest_micro_codex_oai.elf \
  --emulator-evidence firmware/evidence/codex-oai-emulator.json \
  --output firmware/evidence/codex-oai-current-manifest.json
```

The builder and verifier operate on local files only and report zero flash
operations; they do not search for or write a USB device or removable volume.
The current offline evidence is in
[`evidence/codex-oai-emulator.json`](evidence/codex-oai-emulator.json) and
[`evidence/codex-oai-current-manifest.json`](evidence/codex-oai-current-manifest.json).
Physical validation remains PENDING. Before any hardware operation, obtain the
literal approval required by
[`../docs/codex-oai-physical-runbook.md`](../docs/codex-oai-physical-runbook.md);
this build guide does not authorize installation or flashing.

## 4. Flash

Enter the RP2040 bootloader (hold BOOTSEL while plugging in USB, or double-tap
RESET) so the `RPI-RP2` mass-storage drive appears, then:

```bash
qmk flash -kb loudest_micro -km default
# or just copy release/firmware/prebuilt/agentpad13.uf2 (vial) or
# release/firmware/prebuilt/agentpad13_reference.uf2 (plain QMK) onto RPI-RP2
```

**Never wipes user data:** Vial dynamic keymaps/macros live in emulated EEPROM,
not in the firmware image, so reflashing keeps them. A layout that changes the
matrix or layer count is the only thing that forces a `Reset EEPROM`
(bootmagic: hold SW1/`[0,0]` while plugging in).

---

## 4a. Bring-up: first power-on

**The procedure lives in
[`release/firmware/BRING-UP.md`](../release/firmware/BRING-UP.md) — that file is
the single source of truth for it and is not duplicated here.** It was split
out of this section on 2026-08-15 so it can ship in the release bundle
byte-identical (the same arrangement `firmware/POLARITY-NOTE.md` already has):
the audience for bring-up is the owner assembling and powering the first boards,
not a reader of a 400-line toolchain guide. Only the maintainer-side block below
stayed, because its commands need a QMK build tree and repo paths that a bundle
reader does not have.

> **⚠ THE `calibrate` KEYMAP IS DELETED (2026-08-15), AND `BRING-UP.md` HAS NOT
> CAUGHT UP YET.** The separate bring-up firmware — `keymaps/calibrate/`,
> `firmware/prebuilt/loudest_micro_calibrate.uf2`, and its referee
> `firmware/sim/calibrate.cjs` — is gone: the owner flashed it, drove it with
> four `SW1` presses, and it **typed** its measurements into a text editor, and
> the calibration then had to be pasted back into two source files and rebuilt.
> Calibration values now live in the board's own EEPROM (a 14-byte keyboard
> datablock; `config.h`, `docs/PROTOCOL-V1-CONTRACT.md`), survive a power cycle,
> and are applied to all three joystick modes and to the native HID gamepad
> without a rebuild or a reflash.
>
> **RESOLVED later on 2026-08-15 — `BRING-UP.md` has caught up.** That page was
> rewritten around the on-board flow and is followable again end to end: flash
> `agentpad13.uf2`, check the layer LED is pure red, **hold SW14 for a second and
> follow the lights**, then check the touch pad and the encoder. No host, no
> daemon, no CLI, no separate firmware, no reflash — calibration is triggered by
> **SW14 on the board itself** and the board stores its own result.
> (The paragraph this replaces warned that Steps 1–3 could not be followed as
> written, which was true while it stood.) The retired typed-output flow is
> preserved in the release ledger (`release/RELEASE.md`, rows K and L), not
> here. The 0x50/0x51/0x52 commands remain in place
> and working for diagnostics and host tooling; they are simply no longer the
> only path to a calibrated board.

### For maintainers

```bash
qmk compile -kb loudest_micro -km default       # clean under -Werror
qmk compile -kb loudest_micro -km vial          # clean under -Werror (LTO note only)

# Referees for the two shipped artifacts. All four A/B arms are gates:
node firmware/sim/behavior.cjs --touch=board --encoder=board      # 33/33 PASS
node firmware/sim/behavior.cjs --touch=firmware                   # must FAIL (4)
node firmware/sim/behavior.cjs --encoder=firmware                 # must FAIL (2)
node firmware/sim/joystick.cjs                                    # 48/48 PASS
node firmware/sim/joystick.cjs --no-eeprom                        # must FAIL

# Host/device agreement on the wire, no hardware needed:
python3 firmware/tests/conformance/run_conformance.py             # 410/410
```

`joystick.cjs` is the protocol-v1 referee: it boots the real UF2, exercises
0x50/0x51/0x52 and every rejection class, and **proves the calibration survives a
simulated power cycle** rather than assuming it. Its `--no-eeprom` arm removes
the harness's serial-flash model and must fail on exactly the persistence
checks.

---

## 5. Pin map (Rev A — public board `v5_8`; map unchanged from `v5_6`)

Source table: the definitive 30-GPIO table embedded in `check_pins_v4.py`,
originally extracted twice from the final copper and re-verified 20/20 GPIO
against v5_6. The current public board is
`release/hardware/pcb/v5_8.kicad_pcb` (v5_8); relative to v5_6 it retains the
LED20/LED21 correction and adds only the TP5 solder landing, so the GPIO table is unchanged. Direct-pin matrix —
logical `[row][col]` positions unchanged, physical GPIOs follow the board's
x-monotonic routing remap:

| Matrix | Keys | GPIOs |
|---|---|---|
| row 0 | SW1 SW2 SW3 SW4 | GP12 GP9 GP5 GP2 |
| row 1 | SW5 SW6 SW7 SW8 | GP11 GP8 GP4 GP1 |
| row 2 | SW9 SW10 SW11 SW12 | GP10 GP7 GP3 GP0 |
| row 3 | SW13 (2U) · encoder push · touch\* | GP6 · GP15 · *(GP16, see below)* |

\* **GP16 is deliberately NOT in `matrix_pins.direct`** (it is `null` at
`[3][2]`). The board straps the TTP223 **active-HIGH** — `R10` (0 Ω) ties
`TOUCH_AHLB → GND` on the v5 board, so `GP16` idles LOW and drives HIGH while
touched — which is the opposite of the 13 switch-to-GND keys. QMK's only
direct-pin polarity knob, `MATRIX_INPUT_PRESSED_STATE`, is applied **globally**
in `quantum/matrix.c` `readMatrixPin()`, so using it would invert all 13
switches. Instead `loudest_micro.c` configures `GP16` in `keyboard_pre_init_kb()`
(input, pull-**down**) and polls it in `matrix_scan_kb()` with a 5 ms debounce,
injecting `action_exec(MAKE_KEYEVENT(3, 2, pressed))` — so the key keeps its
logical position, keycode, `TO()` layer chain and `TP_TOG` gate. Fixed
2026-08-13; before that the mismatch made `[3,2]` read permanently pressed and
the pad booted into layer 1. Only side effect: Vial's matrix tester cannot show
`[3,2]`, since it reads the scanned `matrix[]`.

Encoder A/B = GP13/GP14 · WS2812 data = GP17 (through the SN74LVC1T45 level
shifter) · joystick X/Y = GP26/GP27 (ADC0/ADC1). GP18/GP19 (I2C1), GP20 and
GP28 go to the DNP J2 expansion header and are unused by firmware. **Trap for
future expansion work:** the J2 net *named* "GP21" is silicon **GPIO24** —
never address it as GPIO21 (`check_pins_v4.py` guards this).

## 6. Raw-HID protocol v0 (LOCKED) and VIA/Vial coexistence

The wire format is LOCKED; the public contract is
`docs/PROTOCOL-V1-CONTRACT.md`. `tests/conformance/protocol_oracle.py` is the
dependency-free host oracle vendored with this tree, and
`tests/conformance/run_conformance.py` asserts the firmware against it
byte-for-byte:

* Descriptor pinned in `config.h`: Usage Page `0xFF60`, Usage `0x61`, VID
  `0xFEED`, PID `0x4C4D`, 32-byte report-ID-less frames.
* `SET_KEY {index,r,g,b,effect}` — `index` is a **raw LED-chain position
  (0–23)**. Because `keyboard.json` authors `rgb_matrix.layout` in chain
  order, chain index == rgb_matrix LED index, so no remap is needed
  (documented in `loudest_micro.h`).
* `SET_LAYER {n}`, `CLEAR`, `PING {token}`.
* CAPS reply: `[0x04, token, 'L'(0x4C), 'D'(0x44), proto=0, led_count=24,
  layer_count=8, features=0x1F]` where features = PER_KEY|UNDERGLOW|
  LAYER_INDICATOR|JOYSTICK|ENCODER. Effects: solid=0, pulse=1, blink=2
  (pulse/blink animated on-device). The host always sends explicit RGB; the
  firmware hardcodes no colors.

### The VIA shadow, and how it is resolved

Under VIA/Vial, `via.c` owns `raw_hid_receive()` and its command switch
consumes IDs 0x01–0x04 (`id_get_protocol_version`,
`id_get/set_keyboard_value`, `id_dynamic_keymap_get_keycode`) before the
`raw_hid_receive_kb()` fallback sees them — which used to shadow the whole
status protocol in the vial build. The fix follows upstream QMK practice: the
`via_command_kb()` pre-hook (present in mainline QMK, missing from the
vial-qmk fork at our pinned commit) is backported by
`patches/0001-via-command-kb-backport.patch` (23 lines, `quantum/via.c` +
`via.h`), and the keyboard implements it as a byte-content dispatcher
(`loudest_micro.c`): frames that are valid v0 protocol commands are handled
and claimed; everything else — including all traffic the Vial GUI actually
sends (verified against vial-gui's `keyboard_comm.py`) — falls through to VIA
untouched.

Three byte patterns are genuinely ambiguous (identical wire bytes, two
meanings). Their dispositions, chosen so both clients stay functional:

| Frame bytes | Could be | Goes to | Cost |
|---|---|---|---|
| `01 00…00` | SET_KEY(0,#000000,solid) / VIA protocol-version handshake | **VIA** | in the vial build, "LED 0 black solid" is expressed via CLEAR or r/g/b ≥ 1 |
| `02 0n 00…` n=1,2,3 | SET_LAYER 1–3 / VIA uptime, layout options, matrix tester | **VIA** | vial build cannot host-switch to layers 1–3 (0 and 4–7 work; the plain-QMK build has the full range; layers remain reachable via touch/Vial GUI) |
| `04 nn 00…` | PING / legacy per-key `get_keycode(n,0,0)` | **loudest** | a legacy VIA client reading key [0,0] would get CAPS bytes; the Vial GUI never sends per-key 0x04 (it bulk-reads via 0x12) |

The **default** (non-VIA) build owns `raw_hid_receive()` outright and runs
the complete protocol with no exceptions. During a Vial security-unlock
sequence (physical key hold) the pre-hook is bypassed and protocol frames are
echoed unhandled — by design, matching Vial's restricted-command window.

---

## 7. Default keymap summary

15 keys, 8 layers. Touch cycles layers via a `TO()` chain (0→1→…→7→0).

* **Layer 0 (BASE):** `F13–F24` on the 4×3 grid; **SW13 (2U hero) = `KC_MPLY`**;
  encoder push = `KC_MUTE`; touch = `TO(1)`.
* **Layer 1 (CTRL):** `JS_MODE`, `TP_TOG`, RGB controls, media transport.
* **Layer 2 (NAV):** arrows / paging / editing.
* **Layers 3–7:** transparent grid (user-customizable), touch keeps the chain alive.
* **Encoder (per-layer map):** volume by default; RGB effect on CTRL; paging on NAV.
* `vial/` keymap = same layers as the compiled-in default, plus `vial.json`
  (15 logical keys, 8 dynamic layers, VialRGB, custom keycodes) and a generated
  `VIAL_KEYBOARD_UID`.

---

## 8. Known follow-ups (no build stubs — these are refinements)

* **Joystick calibration — storage side CLOSED 2026-08-15.** Axes still ship
  with placeholder `0/512/1023` and the 512/300 fallback, but those are now the
  *uncalibrated* case rather than a pending source edit: the board keeps
  per-axis rest/min/max in a 14-byte EEPROM datablock, derives the threshold as
  `floor(60% of the smaller half-swing)`, applies it to the arrow/scroll modes
  and the native gamepad alike, and it survives a power cycle. No source edit,
  no rebuild and no reflash is involved any more. Protocol v1
  (`0x50`/`0x51`/`0x52`, `docs/PROTOCOL-V1-CONTRACT.md`) exposes that store on
  the wire for host tooling and diagnostics. **Still open:** the owner-facing
  way to *start* a calibration, and the `BRING-UP.md` rewrite that goes with it.
  *(This bullet used to say the sweep needed the `calibrate` keymap, which is
  deleted.)* *(This bullet used to say the sweep needed the
  `calibrate` keymap, which is deleted.)*
* **Joystick mode exclusivity.** In arrows/scroll mode the native HID gamepad
  axes keep reporting (QMK's `JOYSTICK_AXIS_IN` task reads every housekeeping
  cycle); the arrow/scroll events are layered on top. To make the modes
  mutually exclusive, switch to virtual axes and drive them manually, or gate
  the joystick task.
* **Persist mode state.** `js_mode` and `touch_enabled` are RAM-only and reset
  on power cycle; persist in EEPROM if desired.
* **Distribution.** Package the status protocol as a QMK Community Module and
  add a VIA V3 JSON for `usevia.app`.

---

## 9. Toolchain gotcha quick-reference

If a fresh build dies with `stdint.h: No such file or directory`, your PATH is
finding the Homebrew `arm-none-eabi-gcc` formula (no newlib) instead of the
official Arm toolchain. Put the extracted `arm-gnu-toolchain/bin` **first** on
PATH.

**Build SERIALLY on macOS.** `qmk compile -j N` adds `--output-sync=target`,
which the GNU Make **3.81** that ships with macOS rejects — the build dies before
compiling anything. The plain `qmk compile` lines in §3 are already serial; do
not add `-j`.

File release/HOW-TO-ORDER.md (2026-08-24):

# HOW TO ORDER — agentpad13 v5

**The configurator at <https://yuz207.github.io/agentpad13/configurator/site/> is the primary way
to build one** — pick your options and get an order sheet whose every line links to the file you
upload or print. **This file is its static form:** the same questions in the same order, on paper.

You order the assembled PCB, and optionally the FR4 plate. Everything else you print. Minimum spend
is roughly $35–45 plus parts — **every price here is an estimate and prices change.** What shipped
and why is [`RELEASE.md`](RELEASE.md).

## 1. LED band

**Do you want the case edges to glow?** **yes** → the **translucent** SKU (10 edge-underglow LEDs
populated, and you want a see-through band); **no** → the **opaque** SKU, same bare board, 20 fewer
parts. It picks the fabpack below and nothing else — the 13 per-key LEDs are on both.

## 2. Board — the one part you cannot make at home

Upload to PCBWay (or any turnkey fab), from `hardware/pcb/fabpack_out_v5_8/`: **`gerbers_v5_8.zip`**
for the PCB quote, **`assembly/bom_<sku>.csv`** + **`assembly/cpl_<sku>.csv`** for assembly
(`<sku>` = `translucent` or `opaque`) — or the all-in-one **`fabpack_<sku>.zip`**.

Form: 2 layers · 84.2 × 100 mm · 1.6 mm FR-4 · qty 5 · single pieces, 1 design · HASL lead-free ·
turnkey assembly, single side. Mask colour only shows through a translucent case; green is
cheapest. Remarks box:

> Please plug/fill the via-in-pad locations (two are on LED pads). Please confirm the 0.2 mm via
> drill is standard tier. Board has intentional reverse-mount LED apertures (through-board cutouts).

The encoder and joystick are both included in the factory placement files. The only normal
user-solder item is the optional `TP5_CONTACT`: a spring, wire, or other conductive contact from
TP5 to an electrode-equipped plate. Omit it for a blank or non-touch plate. The afterlist also
records opt-out rows in case you deliberately exclude the MX sockets or BOOT/RESET switches from
factory assembly.

## 3. Plate — FR4 from a fab, or printed

**Printed:** print `hardware/case/v2/stl/agentpad13_v2_plate.stl` in PETG or resin at 100 % infill
and skip the rest of this card. The matching STEP remains in `hardware/case/v2/step/` for CAD
edits. No copper, so the touch key senses through the panel.

**FR4:** order ONE of these as a bare board, from `hardware/case/v2/fab/`.

- `plate_v5_gerbers.zip` — Ø12 mask opening, an exposed gold disc you touch. **ENIG (lead-free) is
  required**: that is bare copper under a finger, so not a lead-tin alloy, and HASL is not flat.
  The upcharge variant.
- **`plate_v5_ring_gerbers.zip` — the default.** Same electrode tented under the mask (~90 %
  signal) with a Ø16 silk ring. Any finish; HASL lead-free, and the cheapest.
- `plate_v5_blank_gerbers.zip` — no copper. Any finish; the touch key is absent.

Form: 2 layers · **84.4 × 100.0 mm** (deliberately inside the ≤100 mm promo tier) · **1.6 mm**, do
not leave a different default · mask colour = your build's face colour. Remarks: *"Mechanical switch
plate — minimal copper by design; please proceed despite low copper density."*

**⚠️ Tell the fab where the product number goes, or it lands on the face you look at.** PCBWay hide
it under an IC; this panel has none, so ours came back on the visible deck. Set **Customized
Services → `Remove product No.` = `Specify a location`** (free), and write in "Other special
request":

> This is a bare decorative panel with no components. Its top face (the F.Silkscreen side) is the
> visible deck of the finished product. Please place the Product No. on the bottom face — the
> B.Silkscreen side, which faces the tray and is hidden once the case is assembled.

The gerbers also carry PCBWay's `WayWayWay` marker on B.Silkscreen, but that remark is what you
actually rely on.

## 4. Band — the translucent middle

Pick **one** file from `hardware/case/v2/stl/`. The `_w` suffix is the sidewall in mm, the only
thing that differs — everything inside is identical, USB port included.
**`agentpad13_v2_band_1.6mm_w5.4.stl` is the default**, 95.6 × 111.4 mm outside.
`_w3.0` is 90.8 × 106.6 mm and `_w7.4` is 99.6 × 115.4 mm; both are equally valid.
Order it from any SLA resin service in
**clear resin, standard finish — do NOT order polishing** (unpolished prints frosted, which is the
LED-diffusing look), or print it yourself in resin or translucent FDM, upright. Keep it out of sun.

**⚠️ The plate pocket is deliberately tight** — 84.6 × 100.2 mm around the 84.4 × 100.0 mm plate, a
0.1 mm reveal all round, so at a worst-case tolerance stack **the plate may need a light sand to
drop in.** Sand the pocket walls, not the plate.

## 5. Tray — always printed

`hardware/case/v2/stl/agentpad13_v2_tray_v5.stl` — **PETG**, upright, 0.16–0.20 mm layers. PETG is
not a preference: the tray takes the heat-set inserts, and resin cannot.

## 6. Base — optional

**Tray only, or tray plus one base.** All three clip into the same four Ø6 pockets in the tray
underside and print desk-face-down without supports, from `hardware/case/v2/bases/stl/`.

- `riser` — 3.0 mm flat sheet, no angle. TPU for grip, PETG/PLA for a rigid stand; same file.
- `wedge` — same outline, 8° back-raised. That is the typing angle. PETG/PLA.
- `pedestal` — Ø78 tilted drum, the wedge cut to a circle. PETG/PLA, **100 % infill**.

**Print `base_fit_gauge.stl` first:** four peg diameters side by side (Ø5.6 / 5.7 / 5.8 / 5.9), each
marked by raised dots. Push each into a tray pocket, keep the rung that holds, print the matching
`base_<variant>_peg_5pN.stl`. Ø5.8 is the usual answer; TPU wants Ø5.9.

**⚠️ Print the `pedestal` SOLID — structural, not a speed setting.** It is the only base smaller
than the footprint, so its own printed mass is what stops the pad tipping when you press a far
control. Solid it clears the 5 N abuse case; a 20 % gyroid print does not, and there is no ballast
cavity to fall back on.

Every base underside is flat; feet are your business.

## 7. Caps and switches

13 MX-compatible hot-swap switches, no soldering: 12 × 1U + 1 × 2U. Buy keycaps, or print them from
`hardware/PCBWay_keycaps_boxfit_2026-07-24/` — pick one profile (`dish` or `plateau`) and one width
(standard, or the `_17p5` files at 17.5 mm), then print 12 × the `1u` file and 1 × the `2u`. Fitting
a 2U plate-mount stabilizer? Print `2u_stab` instead.

## 8. Toppers — two picks, not one

From `hardware/case/v2/toppers/stl/`; renders of all of them in `../toppers/renders/`.

- **ONE encoder knob** — `knob_v2_A` (helical knurl), `_B2` (deep scoop) or `_C` (cross hatch).
  Each comes as `_clearance_low` and `_clearance_high`. Start with `clearance_low`; use
  `clearance_high` if your printer closes the small internal D-bore. Low is the nominal
  Ø6.0 / 4.5 mm D-shaft size used by commercial push-on knobs; high is Ø6.3 / 4.8 mm
  (0.15 mm clearance, the maximum) for printer/material hole error.
- **ONE stick topper** — choose the compact Ø6.189 dot nub, the restored round Ø9.412 TPU puck,
  or the conventional Ø12 restricted topper. All three use the same 2.00 × 1.25 × 4.00 mm
  rectangular `cell2` socket; the old LOW/HIGH socket ladder is retired. The nub and puck preserve
  the joystick's full 30° travel. The Ø12 topper must be used with
  `ya13_restrictor_cap_TPU_print_roof_down.stl`, which limits throw to about 15.5° so it clears the
  adjacent key. **Print the puck and restrictor in TPU ~95A.** Small TPU sockets and the restrictor's
  retention ribs are printer-sensitive, so confirm seating and throw on the first print.

## 9. Self-buy list

None of this is in the bundle, and every price is an estimate that changes.

- 13 × MX switches
- 1 × Ø6 D-shaft knob, if you are not printing one
- 1 × 2u plate-mount stabilizer, if you want one
- 4 × M3×8 ISO 7380 button-head screws
- 4 × standard Voron-style M3×4×5 heat-set inserts — 4 mm long, nominal 5 mm OD
- optional solderable spring, wire, or other conductive contact from TP5 to an electrode-equipped plate
- 1 × 0.5 mm adhesive-backed PORON sheet, smallest sold — the optional gasket. **Buy 0.5 mm, not
  thicker:** it compresses into a 0.3 mm gap, which 1–2 mm stock will not do. Cut it against
  `hardware/case/v2/gasket/gasket_template.pdf` **at 100 % scale**; see that folder's `README.md`.
- USB-C cable

## 10. Print notes

The five the configurator prints on your sheet — the ones that change what you do:

- Band pocket is deliberately tight — light sand if needed.
- Print the gauge, keep the rung that holds.
- Riser in TPU = grip base, rigid = stand.
- Pedestal prints 100 % solid.
- Printed plate has no copper — touch behaves like the blank variant.

## 11. Assemble

1. Heat-set the four inserts into the tray posts (~245 °C).
2. If using an electrode-equipped touch plate, solder your chosen spring or wire contact to TP5.
3. Fit that contact against the plate electrode; gasket, if you cut one, onto the band ledge.
4. Stack tray → PCB (it just sits on the posts, no screws) → band → plate; drive the four M3 screws.
5. Snap in the switches, supporting the plate from behind on the first few, and cap everything.

## Firmware

Flash `firmware/prebuilt/agentpad13.uf2` — hold BOOTSEL while plugging in and the board mounts as a
drive:

```sh
dd if=firmware/prebuilt/agentpad13.uf2 of=/Volumes/RPI-RP2/fw.uf2 bs=1m
```

**Then calibrate the joystick, once, ever:** hold SW14 — the button in the back — for about a second
and follow the 13 key LEDs. ~15 seconds, no host software and no reflash; the board measures its own
stick and remembers it. Full procedure: [`firmware/BRING-UP.md`](firmware/BRING-UP.md). If an axis
reads backwards that is polarity rather than calibration, and a one-line config edit:
[`firmware/POLARITY-NOTE.md`](firmware/POLARITY-NOTE.md).

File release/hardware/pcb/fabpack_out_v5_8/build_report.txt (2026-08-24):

agentpad13 fab package — build report
generated: 2026-08-24T15:10:30
source board: /Users/yuanz/Documents/GitHub/work-loudest/hardware/pcb/v5_8.kicad_pcb

BARE PCB (identical for both SKUs)
  layers (2): F.Cu, B.Cu, F.Mask, B.Mask, F.SilkS, B.SilkS, Edge.Cuts, F.Paste, B.Paste
  outline bbox (incl. edge stroke): 84.300 x 100.100 mm
  outer outline segments (octagon = 8): 8
  drill holes total: 289  (PTH 241 incl. 186 vias / NPTH 48)
  min copper track: 0.152 mm    min via drill: 0.2 mm
  unconnected ratsnest (informational): 0

PCBWAY TIER HINT: min track 0.152 mm (>=0.152 / 6 mil) -> PCBWay STANDARD-capability trace/space OK. NOTE via drill 0.2 mm (0.30 mm is the classic standard min; 0.20 mm is at the standard/advanced edge — confirm on quote).

ASSEMBLY (per SKU)
  opaque      : CPL 91 placements | BOM 30 lines (place 91, DNP 23)
  translucent : CPL 111 placements | BOM 30 lines (place 111, DNP 3)
  hand-solder afterlist entries: 3

FILES
  gerbers/            15 files
  assembly/           cpl_*.csv, bom_*.csv, hand_solder_afterlist.csv
  gerbers_v5_8.zip   -> PCBWay PCB quote (bare board)
  fabpack_opaque.zip / fabpack_translucent.zip -> complete per-SKU bundles

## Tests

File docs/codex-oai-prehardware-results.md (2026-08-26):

# AgentPad13 direct OAI — pre-hardware results

> **Historical chronology:** the dated sections below retain the exact host,
> build, emulator, and artifact facts recorded at each stage. Every use of
> “current” inside those sections means current at that dated stage and is
> superseded by the destination port rebuild. The current release is
> `release/firmware/prebuilt/agentpad13_codex_oai.uf2`, 93,696 bytes, SHA-256
> `fcb50b2419419be43b7cf90b00a96b16063fcaf182bc24b9642d57e2e8adf54d`.
> All physical observations remain PENDING and no flash occurred.

This is a reproducible pre-hardware record for the isolated `codex_oai`
laboratory keymap. It records what was actually verified locally as of the
AgentPad13 commit below. It does not claim that an unbuilt artifact was
validated and it does not authorize a hardware operation.

## Revision and toolchain

| Item | Recorded value |
|---|---|
| AgentPad13 implementation revision | `bc437a66616edfcec20da4b5f9b70d3e50b813bc` |
| Required Vial-QMK revision | `00fc4627cd038ac9b7e9b8bf2b40b50e9e88aecb` |
| ARM compiler | `arm-none-eabi-gcc (Homebrew ARM GCC 8.5.0_2) 8.5.0` |
| Direct target | `loudest_micro:codex_oai` |
| USB / Raw HID contract | `303A:8360`, `FF00:61`, Report ID 6, 64 bytes |
| flash_operations | `0` |

## Reproduce the host checks

Run these commands from the repository root. They are host-only checks; none
connects to or writes a physical keyboard.

```bash
python3 -m unittest discover -s firmware/tests/codex_oai -p 'test_*.py' -v
cd firmware/tests/emulator && npm run smoke:default && npm run smoke:vial
git diff --check
```

Recorded exits on the revision above:

| Check | Result | Exact count / exit |
|---|---|---|
| OAI host suites | PASS | 36 tests run; 35 passed, 1 expected skip; exit 0 |
| Default RP2040 emulator smoke | PASS | USB, matrix, Raw HID v0 and WS2812 evidence; exit 0 |
| Vial RP2040 emulator smoke | PASS | USB, matrix, Raw HID v0 and WS2812 evidence; exit 0 |
| Diff whitespace check | PASS | exit 0 |

The expected skip is intentional: it is the direct-OAI emulator evidence test
and says that the then-planned Direct OAI UF2 had not yet been produced. The
static OAI report-wrapper and endpoint test still runs.

## Final pre-hardware verification — 2026-08-09

The final host pass was run against implementation revision
`bc437a66616edfcec20da4b5f9b70d3e50b813bc`. It is **not yet a complete
software validation**: the isolated QMK build gate below remains externally
blocked, so no UF2, emulator handshake evidence, or verifier manifest exists.

| Design validation requirement | Result | Evidence from this pass |
|---|---|---|
| 1. OAI parser, reassembly, bounds, readiness and responses | PASS | `test_protocol.py` ran in the 36-test host suite. |
| 2. Byte-for-byte C/Python protocol parity | PASS | handshake, allowlist and malformed-frame parity checks passed. |
| 3. Fifteen physical inputs are allowlisted only | PASS (static) | keymap contract test passed; it checks all 15 positions and encoder routes. Physical observation remains PENDING. |
| 4. Six slots retain RGB/brightness/speed/effect on LEDs 0–5 | PASS (host) | LED parity and per-slot projection checks passed. |
| 5. Stable RGB task/link states, FIFO projection and `uint32_t` rollover | PASS (host) | LED parity, steady-state and rollover checks passed; legacy animations remain an explicit opt-in build. |
| 6. `loudest_micro:codex_oai` lint + clean build | BLOCKED | pinned QMK staging tree has recursive submodules away from recorded revisions. |
| 7. Clean default/Vial builds without functional change | BLOCKED | same external build gate; existing default and Vial emulator smoke tests passed. |
| 8. OAI UF2 RP2040 emulator, descriptor and handshake | BLOCKED | no OAI UF2 may be published before the clean build succeeds. |
| 9. Reproducible verifier manifest/SHA-256 without flash path | BLOCKED | verifier correctly rejected the missing emulator evidence; no hash or manifest was invented. |

The physical runbook remains entirely **PENDING**. No physical check is
reported as PASS by this document.

## Startup LED self-check — 2026-08-17

The direct keymap now includes a host-tested, one-shot power-on diagnostic. It
projects a white pixel through chain indexes `0..23` (documented to the user as
LEDs 1–24, 80 ms per position), flashes the full chain green twice, and then
returns to the existing FIFO task/link renderer. The keymap enables RGB without
EEPROM writes when necessary and keeps it active so task/link LEDs remain
visible after the diagnostic. This is a local WS2812-path check only; USB, OAI
handshake, controls, and physical ordering remain pending until observed on the
PCB.

Host evidence for this change:

```text
test_startup_sweep_visits_all_24_leds_in_order: PASS (C/Python frame parity)
test_startup_led_check_keeps_renderer_enabled_without_persisting: PASS (keymap contract)
flash_operations: 0 (before the rebuild recorded below)
```

### Commands and outcomes

```text
python3 -m unittest discover -s firmware/tests/codex_oai -p 'test_*.py' -v
PASS: 36 run; 35 passed; 1 expected skip; exit 0

npm run smoke:default
PASS: keyboard, matrix, Raw HID v0 and WS2812 evidence

npm run smoke:vial
PASS: keyboard, matrix, Raw HID v0 and WS2812 evidence

npm run smoke:codex-oai
BLOCKED: OAI UF2 unavailable, as required before a successful isolated build

build_codex_oai.py --qmk-home <temporary pinned worktree> --clean
BLOCKED safely: QMK submodules are not at their recorded revisions

verify_codex_oai_artifact.py ...
BLOCKED safely: expected emulator evidence file is absent
```

`git diff --check` passed. The default and Vial keymap diff is empty. The
physical-operation search is empty for `firmware/tools`; its only match in the
host-test tree is the intentional forbidden-vocabulary assertion in
`test_artifact_verifier.py`, not an operation. The original repository still
contains its two user-owned untracked hardware items, and the staged set is
empty.

## External build gate

The isolated build tool is implemented and its seven safety tests pass, but a
fresh external Vial-QMK staging worktree did not have all recursive submodules
at the pinned revisions. The local VIA pre-hook patch was applied to that
disposable tree and the builder then correctly stopped before creating the
temporary keyboard link or publishing an image. Therefore these artifact
facts remain deliberately unavailable:

| Artifact evidence | Status |
|---|---|
| then-planned Direct OAI UF2 | absent |
| matching ELF | absent |
| OAI emulator evidence JSON | absent |
| UF2 SHA-256 | unavailable — do not invent one |
| UF2 byte size | unavailable — do not invent one |
| ELF text/data/bss | unavailable — do not invent values |
| direct-OAI descriptor/emulator result | PENDING external build gate |
| default/vial clean-build regression | PENDING external build gate |

To resolve that gate, create a disposable QMK worktree at the exact revision,
initialize submodules, apply the documented patch, then run the builder:

```bash
qmk_stage_parent="$(mktemp -d /tmp/agentpad13-qmk.XXXXXX)"
qmk_stage_dir="$qmk_stage_parent/qmk"
git -C /path/to/vial-qmk worktree add --detach "$qmk_stage_dir" 00fc4627
git -C "$qmk_stage_dir" submodule update --init --recursive
git -C "$qmk_stage_dir" apply /path/to/agentpad13/firmware/patches/0001-via-command-kb-backport.patch
PATH="/opt/homebrew/opt/arm-none-eabi-gcc@8/bin:$PATH" \
  python3 firmware/tools/build_codex_oai.py --qmk-home "$qmk_stage_dir" --clean
```

After a successful build, run `npm run smoke:codex-oai` in
`firmware/tests/emulator`, then pass the generated UF2, ELF and evidence JSON
to `firmware/tools/verify_codex_oai_artifact.py`. That verifier writes the
real manifest under `firmware/evidence/`; copy its SHA-256, byte size,
text/data/bss and PASS results back into this document only from that manifest.

## Boundary

`codex_oai` has Vial/VIA disabled and uses no helper process. The regular
`default` and `vial` prebuilt UF2s remain separate. This record contains no
automatic install step and no physical USB operation occurred:

```text
flash_operations: 0
```

## Addendum — 2026-08-14: two-layer OAI firmware gate

The direct-OAI keymap now has exactly two default layers (`CODEX` and `FN`),
with a table-driven cycle and an opt-in `CODEX_EXTRA_LAYERS` extension point.
The CODEX layer routes to OAI only after readiness; before readiness it uses
the native Codex fallback with the 600 ms ACCEPT guard, SAFE arming/release
clear, NEW hold terminal action, OS persistence, reasoning and send actions.
The FN layer exposes F2–F12, joystick-mode/touch toggles, and scroll encoder
behavior. FIFO task LED reconciliation and valid-`rgbcfg` handshake revision
resets are covered by the host parity suites.

Fresh verification from the isolated QMK worktree at `00fc4627`:

| Check | Result |
|---|---|
| OAI host suite | PASS — 58 tests, exit 0 |
| pinned lint | PASS — `loudest_micro:codex_oai` |
| clean builds | PASS — `default`, `vial`, `codex_oai` |
| direct-OAI emulator | PASS — keyboard HID, OAI HID, descriptor, rgbcfg/thstatus/device.status ACKs, AG00 event, WS2812 activity |
| artifact verifier | PASS — descriptor, symbols, size/hash, memory evidence |
| default/Vial emulator smokes | PASS |
| `git diff --check` / Python compile / Node check | PASS |

Current direct-OAI artifact evidence:

| Artifact fact | Value |
|---|---|
| UF2 size | `90624` bytes |
| UF2 SHA-256 | `d04ee3cdc62d1955f2f5545622b7491721592802e4ef9f6f10d4419703d1e703` |
| ELF text/data/bss | `45176 / 0 / 265296` |
| VID:PID / usage | `303A:8360` / `FF00:61` |
| Report | ID `6`, `64` bytes |

This is still pre-hardware evidence. No UF2 was copied to a Pico or AgentPad;
all physical rows remain **PENDING** and `flash_operations` remains `0`.

## Addendum — 2026-08-14: runtime OAI keymap RPC

The CODEX/OAI layer now accepts direct HID RPC methods for customization:
`v.oai.keymap.get` returns the compact 15-position map and
`v.oai.keymap.set` validates and persists a replacement. Only layer `0` is
accepted; `ENC` is restricted to the encoder-click position. Invalid requests
return `invalid_keymap` without changing the previous map. The map is stored
with magic/version/checksum in RP2040 wear-leveling and defaults are restored
when the record is absent or corrupt. FN remains ordinary QMK keymap data.

Fresh host/build/emulator evidence for this working tree:

| Check | Result |
|---|---|
| OAI host suite | PASS — 64 tests, exit 0 |
| strict lint | PASS — `loudest_micro:codex_oai` |
| clean builds | PASS — `default`, `vial`, `codex_oai` |
| OAI RP2040 emulator | PASS — descriptor, HID enumeration, ACKs, AG00 event, WS2812 activity |
| default/Vial RP2040 emulator | PASS |
| artifact verifier | PASS — descriptor, symbols, size/hash and emulator binding |
| `py_compile`, `node --check`, `git diff --check` | PASS |

Current direct-OAI artifact (no hardware action):

| Artifact fact | Value |
|---|---|
| UF2 size | `93184` bytes |
| UF2 SHA-256 | `20f475828845db0fda73606785676394586f6a89f6ea1b181899bf6378e28520` |
| ELF text/data/bss | `46340 / 0 / 265296` |
| VID:PID / usage | `303A:8360` / `FF00:61` |
| Report | ID `6`, `64` bytes |

The new RPC contract is host-verified, but all physical rows in the runbook
remain **PENDING**. `flash_operations` remains `0`.

## Addendum — 2026-08-10: clean build and emulator gate completed

The previous external-submodule block is historical. A disposable clone at
QMK `00fc4627` was fully initialized, the repository-owned VIA and ChibiOS
descriptor patches were applied, and the three clean builds completed with
Homebrew ARM GCC 8.5.0 plus binutils. No device was connected or written.

| Check | Result |
|---|---|
| `loudest_micro:codex_oai` strict lint | PASS |
| clean `default`, `vial` and `codex_oai` builds | PASS |
| OAI host suite | 50/50 PASS |
| OAI RP2040 emulator | PASS: USB, keyboard HID, Raw HID, Report ID 6, ACKs, key event and WS2812 activity |
| default/Vial RP2040 emulator | PASS |
| artifact verifier and `git diff --check` | PASS |

The resulting direct-OAI artifact is now available and bound to its emulator
evidence:

| Artifact fact | Value |
|---|---|
| UF2 size | `86016` bytes |
| UF2 SHA-256 | `49edc4d691fb371d69091a80c822589335418a42e2a0eaf992b2319ab0e241d7` |
| ELF text/data/bss | `42840 / 0 / 265296` |
| VID:PID / usage | `303A:8360` / `FF00:0061` |
| Report | ID `6`, `64` bytes |

Physical installation and every Pico/AgentPad control row remain **PENDING**;
the exact pin-by-pin procedure is in
[`codex-oai-pico-runbook.md`](codex-oai-pico-runbook.md). A separate explicit
authorization is required before copying the UF2 to `RPI-RP2`.

## Addendum — 2026-08-17: startup diagnostic, protocol hardening and steady LEDs

This is the current working-tree verification after the last `dev` feature
integration (`e435915`) plus the uncommitted startup-diagnostic changes. It is
the first record that includes the actual rebuilt artifact; it supersedes the
older artifact values above without rewriting their historical records.

| Check | Result |
|---|---|
| OAI host suite | PASS — 75 tests, exit 0 |
| Python compile / Node syntax / `git diff --check` | PASS |
| strict isolated lint | PASS — `loudest_micro:codex_oai` |
| clean builds | PASS — `default`, `vial`, `codex_oai` |
| direct-OAI RP2040 emulator | PASS — USB, keyboard HID, OAI HID, Report ID 6, handshake ACKs, AG00 event, WS2812 activity |
| default/Vial RP2040 emulator | PASS — matrix, USB, Raw HID v0 and WS2812 activity |
| artifact verifier | PASS — descriptor, symbols, ELF metrics, emulator binding and SHA |
| physical flash operations | `0` |

The rebuilt candidate is:

| Artifact fact | Value |
|---|---|
| Target | `loudest_micro:codex_oai` |
| UF2 size | `92160` bytes |
| UF2 SHA-256 | `fe8953013157dd427f7addda1ac3e340ea6b1ded0fda11bfc9d43ae654e5a10f` |
| ELF text/data/bss | `45872 / 0 / 265296` |
| USB / Raw HID | `303A:8360` / `FF00:0061`, Report ID `6`, 64 bytes |

Four software defects found during the audit are now covered by regression
tests: an empty `v.oai.thstatus` array is accepted as a valid readiness no-op
(it does not clear tasks; explicit slot updates still do that), `TP_TOG`
remains reachable after touch has been disabled so FN can re-enable it, and
native fallback NEW now distinguishes a short primary-modifier+N tap from a
held Control+grave terminal gesture. Legacy factory keymaps migrate the 2U
position from SEND to MICROPHONE while custom maps are preserved. The startup
diagnostic is one-shot and
non-persistent: it lights chain indexes
`0..23` one at a time in white for 80 ms, flashes the full chain green twice,
then keeps the RGB-backed task/link renderer active. No hardware was written while
producing this evidence.

The complete physical matrix, actual LED chain order, Codex Desktop host
handshake, F2 output, encoder directions, touch/joystick behavior and task
notifications remain **PENDING** until this exact hash is explicitly flashed
to the assembled board and observed. The previous `20f475...` image does not
contain this startup check and predates the empty-`thstatus` fix.

The latest working-tree correction also keeps RGB runtime-enabled after the
startup sweep. This prevents an EEPROM-disabled RGB state from hiding later
task/link frames; it changes no persistent EEPROM setting. The shipped renderer
now keeps task colours and link status steady until an OAI update or link-state
change, so it does not blink while idle. The legacy effect timing remains an
explicit opt-in (`CODEX_LED_ANIMATION_ENABLE=1`) and is rendered as a slow,
non-zero fade; the default artifact leaves animation disabled.

## Addendum — 2026-08-17: TP5 layer navigation and slow legacy animation

The direct keymap now ships four useful layers: `CODEX`, `FN`, `NAV` and
`MEDIA`. A short encoder click and a TP5 touch both advance the same cyclic
order; the encoder hold remains reserved for the persisted OS-mode toggle.
The grid ACT12 position remains SEND. The 2U position is now the independent
microphone control: it emits `ACT10` press/release, which Codex Desktop
normalizes to its combined `ACT10_ACT11` push-to-talk slot; it no longer emits
ACT12. TP5 no longer emits the legacy touch-to-AG00 event; the 15th OAI map
digit is retained only for wire compatibility, while `TP_TOG` is available on
NAV. The new default compact map is `123456789abced1` (`e` = microphone).

The default LED renderer remains steady. If the historical animation build is
enabled with `CODEX_LED_ANIMATION_ENABLE=1`, task/link output now uses a four
times slower, non-zero triangular fade rather than a hard on/off blink. This
optional path has a dedicated C harness regression; the default artifact keeps
animation disabled.

## Addendum — 2026-08-17: rebuilt OAI-first layer artifact

After the layer contract and TP5 indicator change, the complete host suite and
the pinned clean build were rerun. The disposable QMK worktree was fixed at
`00fc4627`, with initialized recursive submodules and both repository-owned
descriptor patches. No flash or USB write occurred.

| Check | Result |
|---|---|
| OAI host suite | PASS — 77 tests, exit 0 |
| C/Python LED parity | PASS — task FIFO, link states, startup sweep and four layer colours |
| strict lint | PASS — `loudest_micro:codex_oai` |
| clean builds | PASS — `default`, `vial`, `codex_oai` |
| direct-OAI RP2040 emulator | PASS — USB/HID descriptor, handshake ACKs, AG00 event and WS2812 activity |
| artifact verifier | PASS — SHA, size, ELF metrics and required symbols |
| default/Vial emulator smokes | PASS |
| `compileall`, Node syntax and `git diff --check` | PASS |
| flash operations | `0` |

The current unflashed candidate is:

| Artifact fact | Value |
|---|---|
| UF2 size | `92160` bytes |
| UF2 SHA-256 | `333b0e5d94f44d8c489433af74362499f2a6ca8218475ef2af32ff66a3550d1f` |
| ELF text/data/bss | `46056 / 0 / 265296` |
| USB / Raw HID | `303A:8360` / `FF00:0061`, Report ID `6`, 64 bytes |

Human layer 1 is always `CODEX` (QMK index 0) at boot and remains the only
layer accepted by the OAI keymap RPC. Encoder/TP5 cycling still exposes FN,
NAV and MEDIA; LED 13 changes to red/yellow/green/cyan for those four layers,
with an amber/red link tint or slow pulse before readiness. Physical switch,
TP5 and LED observations remain **PENDING**.

## Addendum — 2026-08-17: OAI-first layer indicator

The layer navigation contract now makes the first human layer explicit: `CODEX`
is QMK index `0`, is the only layer accepted by `v.oai.keymap.get/set`, and is
selected at every boot before the auxiliary `FN`, `NAV` and `MEDIA` cycle is
available. Encoder click and TP5 still cycle the auxiliary layers; the long
encoder gesture returns to CODEX while toggling the persisted OS mode.

The physical TP5/layer-indicator LED is chain index 13. It always shows the
active layer as CODEX red, FN yellow, NAV green or MEDIA cyan; the OAI waiting
or error state is an amber/red tint (and a slow pulse in the animation build).
The C renderer and independent Python oracle now cover all four colours; the
physical LED observation remains **PENDING**.

## Addendum — 2026-08-17: function feedback and duplicate SEND correction

The current working tree corrects the previous microphone interpretation. The
matrix key at position 11 and the 2U key at position 12 are both `ACT12`/`SEND`;
the default compact map is now `123456789abccd1`. The microphone action digit
remains available only for an explicitly customized OAI map and is not assigned
to a physical default key.

Action feedback is now selected by physical position rather than by the action
name: positions 6–12 flash white for `CODEX_ACTION_FEEDBACK_MS` (160 ms) on
press, while task positions 0–5 never flash white, even if a custom OAI map
assigns them another action. This keeps task-state LEDs and click feedback
independent.

| Check | Result |
|---|---|
| Host OAI suite | PASS — 78 tests, exit 0 |
| Clean pinned lint/builds | PASS — `default`, `vial`, `codex_oai` |
| OAI/default/Vial emulator smokes | PASS |
| Artifact verifier | PASS — 92,160 bytes, text/data/bss `46024/0/265296` |
| Current UF2 SHA-256 | `0027518334ad985619b8ea4ab548167e9c39a1ba3972cd228212f06890d75806` |
| Flash operations | `0` |

All physical switch, encoder, TP5, task-LED and function-feedback observations
remain **PENDING** until this exact candidate is explicitly authorized and
flashed to the assembled board or Pico test rig.

## Addendum — 2026-08-18: physical key count and 2U microphone assignment

The preceding duplicate-SEND paragraph is superseded by the current physical
map. AgentPad13 has **13 key switches** (the twelve matrix keys plus the
separate 2U key), plus the encoder click and TP5 touch pad. The final default
assignment is:

| Physical control | Function |
|---|---|
| Matrix key 11 (`[2,2]`) | protected `ACCEPT` |
| Matrix key 12 (`[2,3]`) | `ACT12` / `SEND` |
| Separate 2U (`[3,0]`) | `MICROPHONE`, `ACT10` press/release push-to-talk |

The internal OAI map therefore returns `123456789abced1`; index 12 names the
2U route and is not a claim that the 2U is matrix key 12. The source contract,
default-map migration (old version 1 and version 2 factory maps), and host
protocol tests cover this assignment. No flash or physical observation has
been performed.

## Addendum — 2026-08-18: rebuilt 2U-microphone candidate

The clean pinned-QMK build was regenerated after the physical-map correction.
The current unflashed candidate is:

| Artifact fact | Value |
|---|---|
| Target | `loudest_micro:codex_oai` |
| UF2 size | `92160` bytes |
| UF2 SHA-256 | `0b2c9afc5bc1294d232aa1c711c471b37e7ffbce34766608220267c0aff3cc68` |
| ELF text/data/bss | `46056 / 0 / 265296` |
| USB / Raw HID | `303A:8360` / `FF00:0061`, Report ID `6`, 64 bytes |
| Host OAI suite | PASS — 79 tests |
| Emulator + artifact verifier | PASS |
| Flash operations | `0` |

The emulator evidence confirms USB/HID enumeration, all three OAI handshake
acknowledgements, the AG00 event and WS2812 activity. Physical key, 2U
microphone, encoder, TP5 and LED observations remain **PENDING**.

## Addendum — 2026-08-18: official ACT11 order and fresh build

The current `dev` source supersedes the earlier 2U-microphone candidate. The
CODEX physical positions now follow the official action order through position
12: `AG00..AG05`, `ACT06..ACT12`; position 13 is encoder click and position 14
is the legacy protocol slot. In the board geometry this means matrix key 11 is
the protected `ACT10`/ACCEPT route, matrix key 12 is `ACT11` (the second
microphone contact), and the separate 2U position is `ACT12`/SEND. The legacy
`MICROPHONE` digit remains accepted for custom-map compatibility and aliases
`ACT10`.

The persisted keymap format is version 3. Factory records from both prior
layouts (`...abccd1` and `...abced1`) migrate to `123456789abfcd1`; custom
maps survive unchanged. `ACT11` is covered by the byte-exact protocol harness
and by the physical-layout contract test.

Fresh no-hardware verification after this change:

| Check | Result |
|---|---|
| Focused protocol + keymap contract | PASS — 40 tests |
| Full OAI host suite | PASS — 81 tests |
| Clean pinned QMK lint | PASS — `loudest_micro:codex_oai` |
| Clean `default`, `vial`, `codex_oai` builds | PASS — QMK `00fc4627`, Report-ID patch, ARM GCC 8.5 |
| Direct-OAI RP2040 emulator | PASS — new UF2 enumerates, handshakes, AG00 and WS2812 |
| Current UF2 | 92,672 bytes; SHA-256 `11ee3ed649cf198186fc1e3c190fcaf6a7a1cfbdb18f68ebbead974b09a1712b` |
| ELF text/data/bss | `46144 / 0 / 265296`; required symbols and manifest verifier PASS |
| Physical flash operations | `0` |

The emulator emitted one expected rp2040js SIO warning (`Write to invalid SIO
address: 50`) but completed with all required evidence fields true. Hardware
rows remain **PENDING** until the board/Pico is operated and observed.
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

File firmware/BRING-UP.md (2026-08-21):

# BRING-UP — first power-on

**Do this once, on each newly assembled board.** It takes about five minutes.
You need a USB cable and nothing else — no meter, no scope, no soldering, no
software to install, and no electronics knowledge. The board calibrates itself
and stores the result in its own memory.

> **Where this file lives.** `firmware/BRING-UP.md` in the working tree is the
> **single source of truth** for this procedure; `firmware/BUILD.md` §4a points
> here rather than repeating it. A copy ships in the release bundle
> (`release/firmware/BRING-UP.md`), refreshed from this one when the
> bundle is rebuilt. Everything below needs only this page, a USB cable, and the
> `.uf2` files in `firmware/prebuilt/` — no build toolchain and no source
> checkout.

---

## Step 1 — flash the firmware

1. Unplug the board.
2. **Hold the BOOTSEL button (SW14, in the back) and plug the USB cable back
   in.** A USB drive called **`RPI-RP2`** appears on your computer.
3. Drag **`firmware/prebuilt/agentpad13.uf2`** onto that drive.
   md5 `a7b8da85a7d3f0de96b983be8c782ba2`.
4. The drive disappears by itself. That means it worked.

> **If dragging the file fails, use the terminal — this is common on macOS.**
> The bootloader drive is not a real disk. It is a small pretend filesystem
> that accepts exactly one file write and then reboots the board. Anything that
> writes more than the plain file — metadata, extended attributes, a
> preallocation — gets rejected, and you see one of these:
>
> | what you did | what you get |
> |---|---|
> | dragged it in Finder | *"there isn't enough space"* (there is; 132 MB free) |
> | `cp file.uf2 /Volumes/RPI-RP2/` | `Invalid argument` |
> | `cp -X file.uf2 /Volumes/RPI-RP2/` | usually `Invalid argument` too |
>
> **This always works:**
>
> ```
> dd if=firmware/prebuilt/agentpad13.uf2 of=/Volumes/RPI-RP2/fw.uf2 bs=1m
> ```
>
> `dd` writes plain sequential blocks — no metadata, no preallocation, nothing
> the bootloader can refuse. The destination filename is irrelevant; the
> bootloader reads the contents, not the name. You should see roughly
> `109568 bytes transferred`, then the drive disappears on its own.
>
> On Linux, plain `cp` to the mount point normally works. On Windows, dragging
> in Explorer normally works. It is macOS that is fussy here.

> **Do not hold SW1 while plugging in.** SW1 is the top-left key, and holding it
> at plug-in is QMK's **Reset EEPROM** gesture — it wipes your saved settings,
> including the joystick calibration you are about to make.

> **The first time you flash this version, your key layout resets — once.**
> This firmware stores the joystick calibration in a small block of the board's
> memory, which shifts where the layout editor keeps its own data by 14 bytes.
> The board notices and starts that area fresh. If you had customised your
> layout in Vial, redo it after this one upgrade. It will not happen again on
> later updates.

## Step 2 — the ten-second check

Look at the **layer-indicator LED** — the small one just below the top-left key.

* **Pure red** → good. Go on to Step 3.
* **Orange** → this unit is running firmware older than 2026-08-13 and boots
  into the wrong layer. Repeat Step 1; the drag did not take.

## Step 3 — calibrate the joystick

The joystick ships with **placeholder** settings, and until you do this the
arrow and scroll modes may be dead or twitchy. The board fixes this itself.

**Press and hold SW14 — the same button in the back you used to flash — for
about one second, then let go and follow the lights.** The 13 key LEDs are the
whole display. The keyboard keeps working normally the entire time; you can
keep typing if you want to.

| the lights do this | you do this |
|---|---|
| **all 13 keys turn white** | let go of SW14 |
| **a blue bar fills across the keys** (about 2 seconds) | **take your hand off the stick.** It is measuring where the stick rests |
| **a bar fills across the keys again** (about 10 seconds), starting **amber** | **slowly roll the stick around its outside edge**, a few full circles, pushing it as far as it will go |
| **that bar turns green** | you have moved it far enough — keep rolling until the bar finishes |
| **all 13 keys flash green** | **done.** Calibration is stored. It survives unplugging, and you never need to do this again |
| **all 13 keys flash red** | it did not work. Nothing was changed. See below |
| **a brief dim white flash** | cancelled — nothing was changed |

**If you get red,** nothing was stored and your previous settings are untouched.
Just do it again. The two usual causes:

* **You did not move the stick far enough.** Push it all the way to the edge and
  roll it right around the rim, twice, slowly.
* **Your hand was on the stick during the blue bar.** That step measures the
  resting position, so the stick has to be sitting still by itself.

**To cancel at any time,** press SW14 again. The lights flash dim white and
nothing is changed.

> **If your LEDs are switched off,** this step has no display — the lights are
> the only thing the board uses to talk to you here. Turn the RGB back on before
> calibrating, then switch it off again afterwards if you prefer it dark.

## Step 4 — check the touch pad and the encoder

Open a text editor and click into an empty document.

* **Touch pad** — rest a finger on it. It should act while your finger is
  **down**, and stop when you lift. If it behaves backwards — acting when you
  *lift* — this unit predates the touch fix; reflash it (Step 1).
* **Encoder knob** — turn it. **Clockwise should turn the volume up.** If it is
  backwards, note which way is which and report it.
* **Encoder push** — press the knob in. It should mute.

That is the whole bring-up. The board is ready to use.

---

### Notes

**Why SW14 does two things.** Held while you plug the board in, it is the
bootloader button that gives you the `RPI-RP2` drive. Pressed while the board is
already running, it starts calibration. The two can never be confused, because
at plug-in time the calibration firmware is not running yet.

**Nothing here needs a daemon or any host software.** The calibration lives in
the board's own memory and is applied by the board itself, to all three joystick
modes and to the plain USB gamepad.

**A brush cannot start calibration.** The button has to be held for a full
second before the white lights appear.

**If an axis reads reversed** — the stick moves right and the pointer goes left
— that is a separate one-line fix, described in `firmware/POLARITY-NOTE.md`.
Calibration does not correct direction, only range.

Build and flash flow, the pin map, and the maintainer-side gates:
`firmware/BUILD.md` (§3, §4 and the §4a maintainers block). The wire protocol
and the exact calibration maths: `docs/PROTOCOL-V1-CONTRACT.md`.

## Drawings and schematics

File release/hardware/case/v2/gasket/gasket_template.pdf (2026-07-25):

# agentpad13 v2 — optional PORON ledge-gasket kit

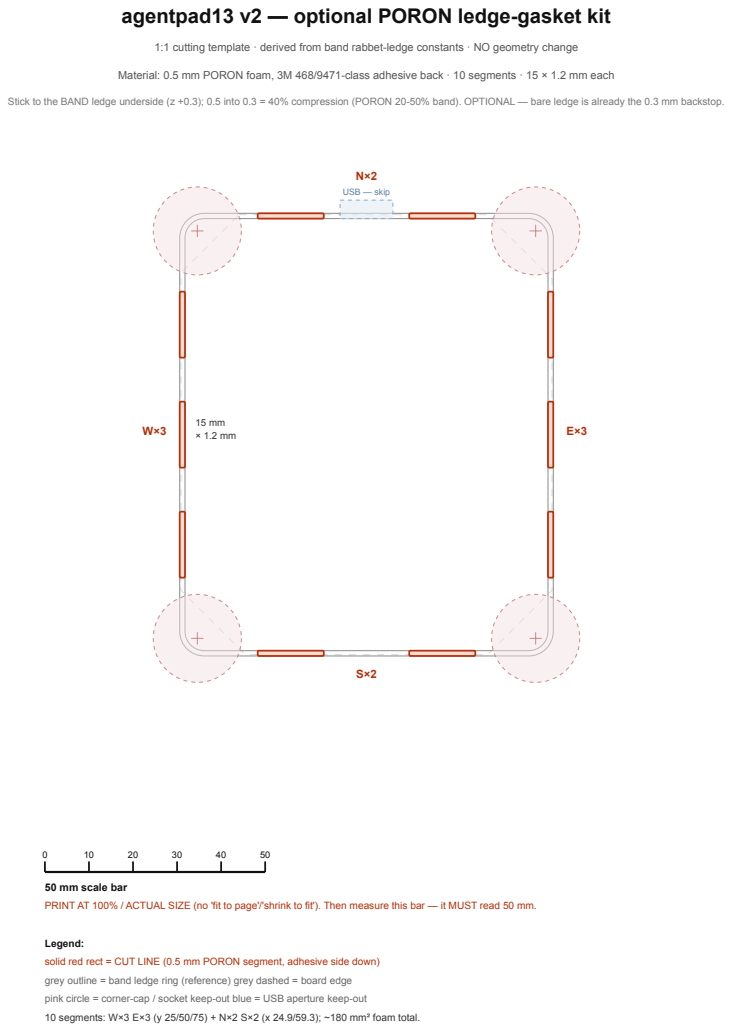
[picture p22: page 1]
USB — skip

1:1 cutting template · derived from band rabbet-ledge constants · NO geometry change

Material: 0.5 mm PORON foam, 3M 468/9471-class adhesive back · 10 segments · 15 × 1.2 mm each

Stick to the BAND ledge underside (z +0.3); 0.5 into 0.3 = 40% compression (PORON 20-50% band). OPTIONAL — bare ledge is already the 0.3 mm backstop.

50 mm scale bar
PRINT AT 100% / ACTUAL SIZE (no 'fit to page'/'shrink to fit'). Then measure this bar — it MUST read 50 mm.

Legend:
solid red rect = CUT LINE (0.5 mm PORON segment, adhesive side down)
grey outline = band ledge ring (reference) grey dashed = board edge
pink circle = corner-cap / socket keep-out blue = USB aperture keep-out
10 segments: W×3 E×3 (y 25/50/75) + N×2 S×2 (x 24.9/59.3); ~180 mm² foam total.

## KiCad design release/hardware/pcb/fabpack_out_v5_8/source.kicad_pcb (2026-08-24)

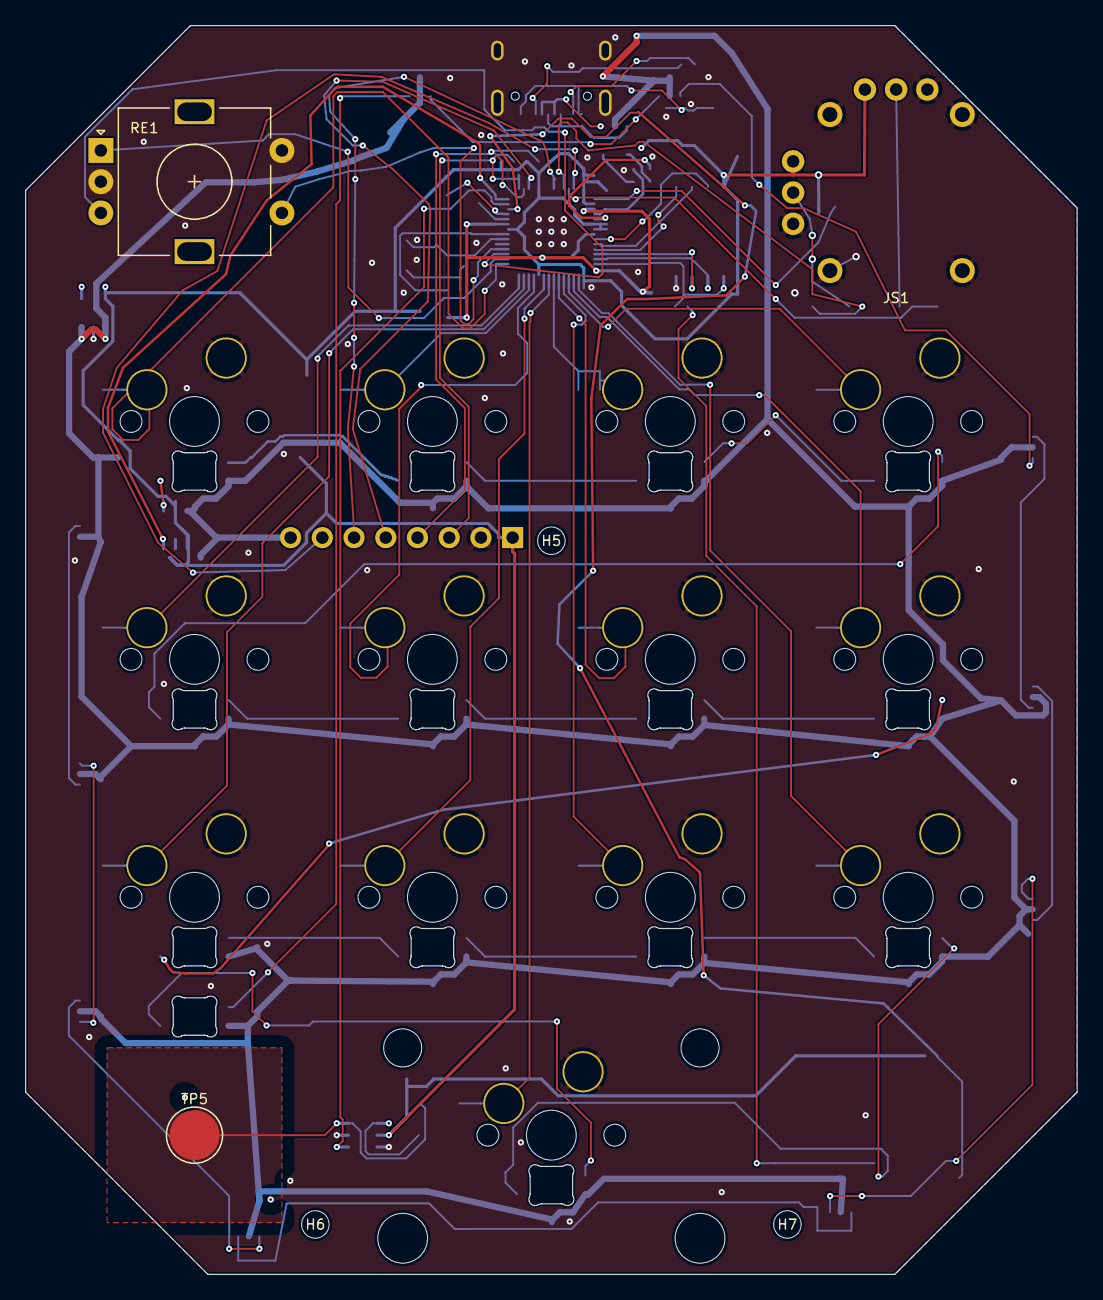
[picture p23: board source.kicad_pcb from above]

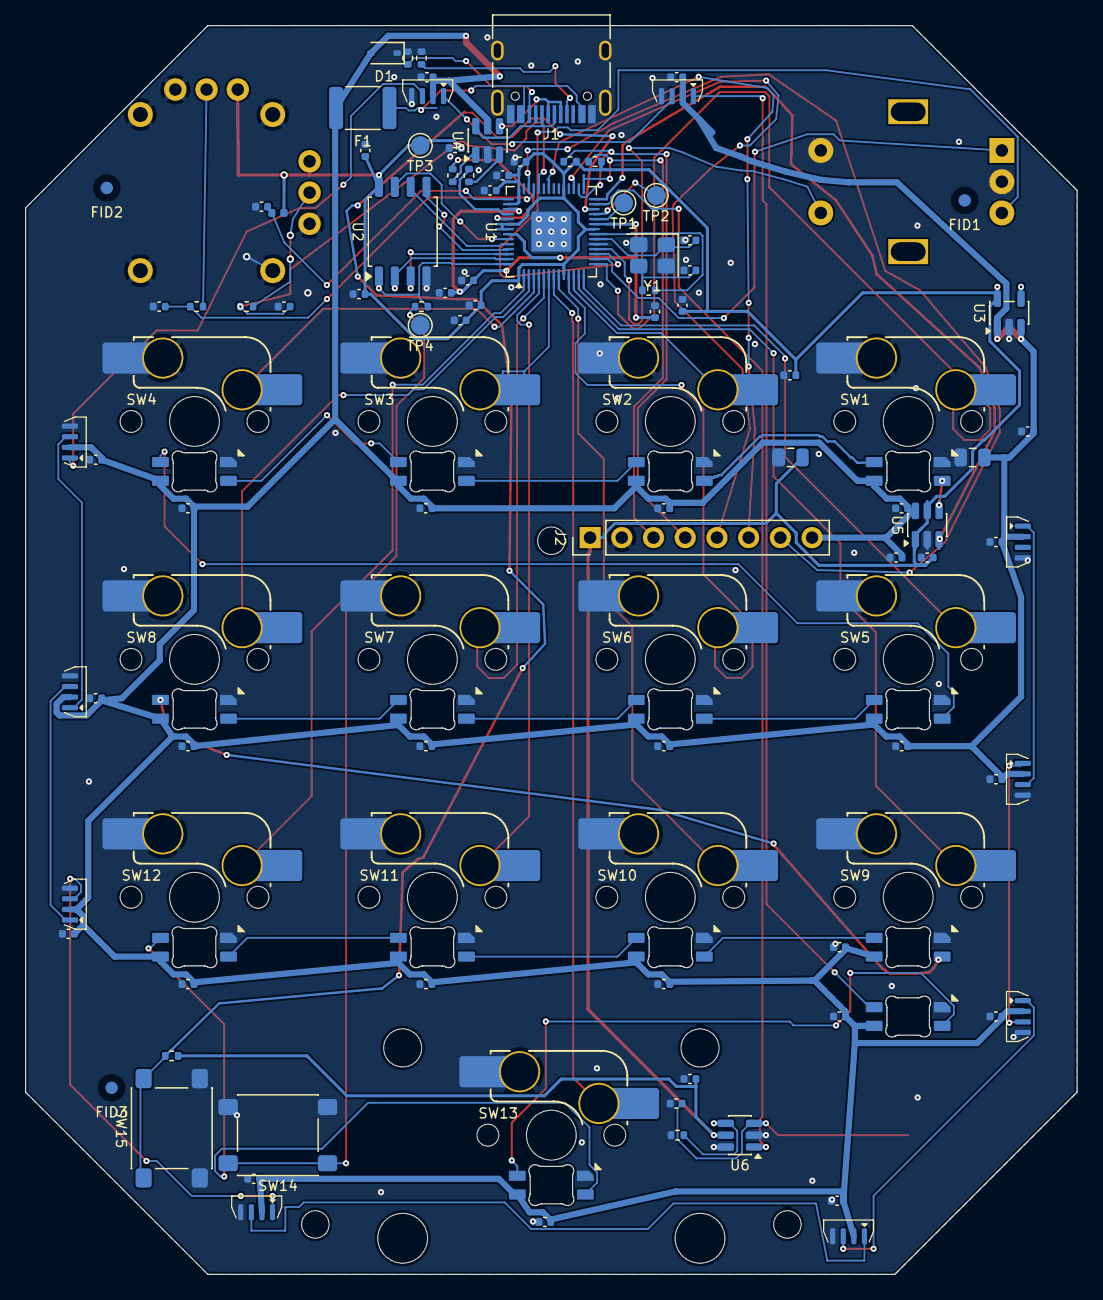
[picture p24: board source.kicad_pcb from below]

Board: 2 copper layers, 84.2 x 100.0 mm, 126 parts (119 on the bottom side), 80 nets.

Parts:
C1, C2, C3, C4, C5, C6, C7, C8, C9, C10, C13, C20, C21, C22, C23, C24, C26, C27, C28, C29, C30, C31, C32, C33, C34, C35, C36, C37, C38, C39, C40, C41, C42, C43, C44, C45, C46, C47, C48, C49: 100n; C_0402_1005Metric
C11, C12, C14, C15: 1u; C_0402_1005Metric
C16, C17: 10u; C_0805_2012Metric
C18, C19: 15p; C_0402_1005Metric
C25: DNP; C_0402_1005Metric
D1: SD05C; D_SOD-323
F1: 750mA; Fuse_1812_4532Metric
FB1: 600R@100MHz; L_0402_1005Metric
FID1, FID2, FID3: Fiducial_1mm_Mask2mm
H5, H6, H7: (no value)
J1: USB-C; USB_C_Receptacle_HRO_TYPE-C-31-M-12
J2: EXPANSION; PinHeader_1x08_P2.54mm_Vertical
JS1: YA13-FL7.4-B5Ka; YA13-FL7.4-B5Ka_C37323742
LED1, LED2, LED3, LED4, LED5, LED6, LED7, LED8, LED9, LED10, LED11, LED12, LED13, LED14: SK6812MINI-E; LED_6028R
LED15, LED16, LED17, LED18, LED19, LED20, LED21, LED22, LED23, LED24: SK6812-SIDE; LED_WS2812_4020
R1, R2: 5.1k; R_0402_1005Metric
R3, R4: 27; R_0402_1005Metric
R5, R6, R11, R12: 1k; R_0402_1005Metric
R7: 10k; R_0402_1005Metric
R8, R9: 4.7k; R_0402_1005Metric
R10: 0R; R_0402_1005Metric
RE1: EC11; RotaryEncoder_Alps_EC11E-Switch_Vertical_H20mm
STAB1: MX_2u_stab; STAB_MX_2u
SW1, SW2, SW3, SW4, SW5, SW6, SW7, SW8, SW9, SW10, SW11, SW12, SW13: MX_Hotswap; SW_MX_HS_CPG151101S11_1u
SW14: BOOT; SW_SPST_PTS645Sx43SMTR92
SW15: RESET; SW_SPST_PTS645Sx43SMTR92
TP1: SWCLK; TestPoint_Pad_D1.5mm
TP2: SWDIO; TestPoint_Pad_D1.5mm
TP3: 3V3; TestPoint_Pad_D1.5mm
TP4: GND; TestPoint_Pad_D1.5mm
TP5: TOUCHPAD; TestPoint_Pad_D4.0mm
U1: RP2040; QFN-56-1EP_7x7mm_P0.4mm_EP3.2x3.2mm
U2: W25Q128JVSIQ; SOIC-8_5.3x5.3mm_P1.27mm
U3: AP2112K-3.3; SOT-23-5
U4: USBLC6-2SC6; SOT-23-6
U5: SN74LVC1T45; SOT-23-6
U6: TTP223; SOT-23-6
Y1: 12MHz ABM8-272-T3; Crystal_SMD_3225-4Pin_3.2x2.5mm

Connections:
+1V1: C7.1, C8.1, C12.1, U1.23, U1.45, U1.50
+3V3: C1.1, C2.1, C3.1, C4.1, C5.1, C6.1, C10.1, C11.1, C13.1, C15.1, C17.1, C20.1, C22.1, FB1.1, J2.1, JS1.1, JS1.4, R7.1, R8.1, R9.1, TP3.1, U1.1, U1.10, U1.22, U1.33, U1.42, U1.44, U1.48, U1.49, U2.8, U3.5, U5.1, U5.5, U6.5
+5V: C14.1, C16.1, C21.1, C26.1, C27.1, C28.1, C29.1, C30.1, C31.1, C32.1, C33.1, C34.1, C35.1, C36.1, C37.1, C38.1, C39.1, C40.1, C41.1, C42.1, C43.1, C44.1, C45.1, C46.1, C47.1, C48.1, C49.1, D1.2, F1.2, J2.8, LED1.1, LED2.1, LED3.1, LED4.1, LED5.1, LED6.1, LED7.1, LED8.1, LED9.1, LED10.1, LED11.1, LED12.1, LED13.1, LED14.1, LED15.2, LED16.2, LED17.2, LED18.2, LED19.2, LED20.2, LED21.2, LED22.2, LED23.2, LED24.2, U3.1, U3.3, U4.5, U5.6
ADC_AVDD: C9.1, FB1.2, U1.43
BOOTSEL: R6.2, SW14.1
CC1: J1.A5, R1.1
CC2: J1.B5, R2.1
DM: R4.2, U1.46
DP: R3.2, U1.47
ENC_A: RE1.A, U1.16
ENC_B: RE1.B, U1.17
ENC_SW: RE1.S1, U1.18
GND: C1.2, C2.2, C3.2, C4.2, C5.2, C6.2, C7.2, C8.2, C9.2, C10.2, C11.2, C12.2, C13.2, C14.2, C15.2, C16.2, C17.2, C18.2, C19.2, C20.2, C21.2, C22.2, C23.2, C24.2, C25.2, C26.2, C27.2, C28.2, C29.2, C30.2, C31.2, C32.2, C33.2, C34.2, C35.2, C36.2, C37.2, C38.2, C39.2, C40.2, C41.2, C42.2, C43.2, C44.2, C45.2, C46.2, C47.2, C48.2, C49.2, D1.1, J1.A1, J1.A12, J1.B1, J1.B12, J1.S1, J2.2, JS1.3, JS1.6, JS1.MP1, JS1.MP2, JS1.MP3, JS1.MP4, LED1.4, LED2.4, LED3.4, LED4.4, LED5.4, LED6.4, LED7.4, LED8.4, LED9.4, LED10.4, LED11.4, LED12.4, LED13.4, LED14.4, LED15.4, LED16.4, LED17.4, LED18.4, LED19.4, LED20.4, LED21.4, LED22.4, LED23.4, LED24.4, R1.2, R2.2, R10.2, RE1.C, RE1.S2, SW1.2, SW2.2, SW3.2, SW4.2, SW5.2, SW6.2, SW7.2, SW8.2, SW9.2, SW10.2, SW11.2, SW12.2, SW13.2, SW14.2, SW15.2, TP4.1, U1.19, U1.57, U2.4, U3.2, U4.2, U5.2, U6.2, U6.6, Y1.2, Y1.4
GP20: J2.5, U1.31
GP21: J2.6, U1.36
GP28: J2.7, U1.40
JOY_X: JS1.2, R11.1
JOY_X_ADC: C23.1, R11.2, U1.38
JOY_Y: JS1.5, R12.1
JOY_Y_ADC: C24.1, R12.2, U1.39
PORT_DM: J1.A7, J1.B7, U4.4
PORT_DP: J1.A6, J1.B6, U4.6
QSPI_CLK: U1.52, U2.6
QSPI_CS: R6.1, U1.56, U2.1
QSPI_SD0: U1.53, U2.5
QSPI_SD1: U1.55, U2.2
QSPI_SD2: U1.54, U2.3
QSPI_SD3: U1.51, U2.7
RGB_D00: LED1.3, U5.4
RGB_D01: LED1.2, LED2.3
RGB_D02: LED2.2, LED3.3
RGB_D03: LED3.2, LED4.3
RGB_D04: LED4.2, LED5.3
RGB_D05: LED5.2, LED6.3
RGB_D06: LED6.2, LED7.3
RGB_D07: LED7.2, LED8.3
RGB_D08: LED8.2, LED9.3
RGB_D09: LED9.2, LED10.3
RGB_D10: LED10.2, LED11.3
RGB_D11: LED11.2, LED12.3
RGB_D12: LED12.2, LED13.3
RGB_D13: LED13.2, LED14.3
RGB_D14: LED14.2, LED15.1
RGB_D15: LED15.3, LED16.1
RGB_D16: LED16.3, LED17.1
RGB_D17: LED17.3, LED18.1
RGB_D18: LED18.3, LED19.1
RGB_D19: LED19.3, LED20.1
RGB_D20: LED20.3, LED21.1
RGB_D21: LED21.3, LED22.1
RGB_D22: LED22.3, LED23.1
RGB_D23: LED23.3, LED24.1
RGB_MCU: U1.28, U5.3
RUN: R7.2, SW15.1, U1.26
SCL: J2.4, R9.2, U1.30
SDA: J2.3, R8.2, U1.29
SW1: SW1.1, U1.15
SW2: SW2.1, U1.12
SW3: SW3.1, U1.7
SW4: SW4.1, U1.4
SW5: SW5.1, U1.14
SW6: SW6.1, U1.11
SW7: SW7.1, U1.6
SW8: SW8.1, U1.3
SW9: SW9.1, U1.13
SW10: SW10.1, U1.9
SW11: SW11.1, U1.5
SW12: SW12.1, U1.2
SW13: SW13.1, U1.8
SWCLK: TP1.1, U1.24
SWDIO: TP2.1, U1.25
TOUCH_AHLB: R10.1, U6.4
TOUCH_OUT: U1.27, U6.1
TOUCH_PAD: C25.1, TP5.1, U6.3
USB_DM: R4.1, U4.3
USB_DP: R3.1, U4.1
VBUS: F1.1, J1.A4, J1.A9, J1.B4, J1.B9
XIN: C18.1, U1.20, Y1.1
XOUT: R5.1, U1.21
XOUT_XTAL: C19.1, R5.2, Y1.3

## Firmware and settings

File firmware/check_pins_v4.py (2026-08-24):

#!/usr/bin/env python3
"""agentpad13 Rev A firmware pin-map checker.

Asserts every pin in the firmware configuration against the definitive Rev A
per-GPIO table embedded below. The table was extracted twice from the final
board (netlist + pcbnew copper, identical on all 57 U1 pads), re-verified 20/20
against v5_6, and remains unchanged on the current public v5_8 board.

Checks, in order:
  1. keyboard.json matrix_pins.direct == the table, per logical key position.
  1b. TOUCH_OUT (GP16) is deliberately NOT in that matrix (the board straps the
     TTP223 active-HIGH and QMK's polarity knob is global), so instead: it is
     bound and read active-HIGH in loudest_micro.c and injected at [3,2], and
     MATRIX_INPUT_PRESSED_STATE stays undefined.
  2. keyboard.json encoder / ws2812 / joystick pins == the table.
  3. No firmware reference to any spare/NC GPIO (GP18-GP25, GP28, GP29) -
     including the "GP21" J2 net-name trap: that NET is silicon GPIO24 and
     must never appear in firmware as a GPIO number.
  4. Source scan: every GPnn token in the keyboard C sources is one of the
     pins the table assigns to firmware.
  5. (--qmk-info FILE) the same pin assertions against the resolved build
     config emitted by `qmk info -kb loudest_micro -f json`.
  6. (--qmk-home DIR) the vial-qmk tree contains the via_command_kb()
     backport (firmware/patches/0001-via-command-kb-backport.patch), without
     which the vial build silently loses status-protocol commands to VIA.

Exit code 0 with a final "PASS" line only if every assertion holds.

Usage:
    python3 check_pins_v4.py [--qmk-info info.json] [--qmk-home /path/to/vial-qmk]
"""
import argparse
import json
import re
import sys
from pathlib import Path

HERE = Path(__file__).resolve().parent
KEYBOARD_DIR = HERE / "loudest_micro"

# --- The authority: definitive GPIO table, verified against the v5 board ---
# function -> GPIO (only the firmware-relevant, assigned pins)
TABLE = {
    "SW1": "GP12",   # U1 pad 15, net SW1
    "SW2": "GP9",    # U1 pad 12, net SW2
    "SW3": "GP5",    # U1 pad 7,  net SW3
    "SW4": "GP2",    # U1 pad 4,  net SW4
    "SW5": "GP11",   # U1 pad 14, net SW5
    "SW6": "GP8",    # U1 pad 11, net SW6
    "SW7": "GP4",    # U1 pad 6,  net SW7
    "SW8": "GP1",    # U1 pad 3,  net SW8
    "SW9": "GP10",   # U1 pad 13, net SW9
    "SW10": "GP7",   # U1 pad 9,  net SW10
    "SW11": "GP3",   # U1 pad 5,  net SW11
    "SW12": "GP0",   # U1 pad 2,  net SW12
    "SW13": "GP6",   # U1 pad 8,  net SW13
    "ENC_A": "GP13",     # U1 pad 16, net ENC_A
    "ENC_B": "GP14",     # U1 pad 17, net ENC_B
    "ENC_SW": "GP15",    # U1 pad 18, net ENC_SW
    "TOUCH_OUT": "GP16", # U1 pad 27, net TOUCH_OUT
    "RGB_MCU": "GP17",   # U1 pad 28, net RGB_MCU (ws2812 data)
    "JOY_X_ADC": "GP26", # U1 pad 38, ADC0, net JOY_X_ADC
    "JOY_Y_ADC": "GP27", # U1 pad 39, ADC1, net JOY_Y_ADC
}

# Logical key grid -> function name. SW1-SW4 = row 0 left-to-right, SW5-SW8 =
# row 1, SW9-SW12 = row 2, SW13 (2U hero) = [3,0], encoder push = [3,1],
# [3,2] = touch (NOT a scanned matrix pin - see below), [3,3] unused.
#
# [3,2] is None ON PURPOSE (2026-08-13). The board straps the TTP223 ACTIVE-HIGH
# (R10 0R: TOUCH_AHLB -> GND on the current v5_8 board), the opposite sense of the 13
# switch-to-GND keys, and QMK's MATRIX_INPUT_PRESSED_STATE is global. So GP16 is
# removed from matrix_pins.direct and polled with its own sense in
# loudest_micro.c, which injects the key event at logical [3,2]. The check that
# GP16 is still claimed by firmware moved to check_touch_outside_matrix().
MATRIX_FUNCTIONS = [
    ["SW1", "SW2", "SW3", "SW4"],
    ["SW5", "SW6", "SW7", "SW8"],
    ["SW9", "SW10", "SW11", "SW12"],
    ["SW13", "ENC_SW", None, None],
]

# Reporting labels for positions with no scanned pin, so a `null` that is
# deliberate does not print as "unused".
MATRIX_LABELS = {(3, 2): "TOUCH_OUT (GP16, out of matrix by design)"}

# GPIOs firmware must never reference: I2C spares to the DNP J2 header
# (GP18 SDA / GP19 SCL / GP20 / GP28) plus every NC pad (GPIO21/22/23/25/29)
# and GPIO24 - the trap: the J2 net NAMED "GP21" is silicon GPIO24.
FORBIDDEN = {f"GP{n}" for n in (18, 19, 20, 21, 22, 23, 24, 25, 28, 29)}

ALLOWED = set(TABLE.values())

failures = []
checks = 0


def check(desc, ok, detail=""):
    global checks
    checks += 1
    status = "ok" if ok else "FAIL"
    line = f"  [{status}] {desc}"
    if detail and not ok:
        line += f"  <- {detail}"
    print(line)
    if not ok:
        failures.append(desc)


def assert_pin_config(cfg, source_name):
    """Assert matrix/encoder/ws2812/joystick pins in a keyboard.json-shaped dict."""
    print(f"-- {source_name}")
    direct = cfg["matrix_pins"]["direct"]
    check(f"{source_name}: matrix is 4 rows x 4 cols",
          len(direct) == 4 and all(len(r) == 4 for r in direct))
    for r, row in enumerate(MATRIX_FUNCTIONS):
        for c, func in enumerate(row):
            want = TABLE[func] if func else None
            got = direct[r][c]
            # qmk info resolves null to the string "NO_PIN"
            if got in (None, "NO_PIN"):
                got = None
            label = func or MATRIX_LABELS.get((r, c), "unused")
            check(f"{source_name}: [{r},{c}] {label} = {want or 'null'}",
                  got == want, f"got {got}")
    enc = cfg["encoder"]["rotary"][0]
    check(f"{source_name}: encoder pin_a ENC_A = {TABLE['ENC_A']}",
          enc["pin_a"] == TABLE["ENC_A"], f"got {enc['pin_a']}")
    check(f"{source_name}: encoder pin_b ENC_B = {TABLE['ENC_B']}",
          enc["pin_b"] == TABLE["ENC_B"], f"got {enc['pin_b']}")
    check(f"{source_name}: ws2812 pin RGB_MCU = {TABLE['RGB_MCU']}",
          cfg["ws2812"]["pin"] == TABLE["RGB_MCU"], f"got {cfg['ws2812']['pin']}")
    axes = cfg["joystick"]["axes"]
    check(f"{source_name}: joystick x JOY_X_ADC = {TABLE['JOY_X_ADC']}",
          axes["x"]["input_pin"] == TABLE["JOY_X_ADC"], f"got {axes['x']['input_pin']}")
    check(f"{source_name}: joystick y JOY_Y_ADC = {TABLE['JOY_Y_ADC']}",
          axes["y"]["input_pin"] == TABLE["JOY_Y_ADC"], f"got {axes['y']['input_pin']}")
    # Forbidden-pin sweep over the whole config. Documentation keys ("$..."
    # comments) may legitimately NAME spare pins while explaining that they
    # are unused, so they are stripped: only configuration values count.
    def strip_comments(node):
        if isinstance(node, dict):
            return {k: strip_comments(v) for k, v in node.items()
                    if not k.startswith("$")}
        if isinstance(node, list):
            return [strip_comments(v) for v in node]
        return node

    blob = json.dumps(strip_comments(cfg))
    hits = sorted(set(re.findall(r"\bGP(?:18|19|2[0-5]|28|29)\b", blob)))
    check(f"{source_name}: no spare/NC GPIO in configuration values (GP18-25/28/29)",
          not hits, f"found {hits}")


def check_touch_outside_matrix():
    """TOUCH_OUT (GP16) left the scanned matrix, so assert it is still claimed.

    The board straps the TTP223 active-HIGH (R10 0R: TOUCH_AHLB -> GND), so GP16
    cannot ride the direct-pin matrix, whose polarity knob is global. It must
    instead be bound to its own pin, read with an active-HIGH sense, and injected
    at logical [3,2]. Without these assertions, dropping GP16 from
    matrix_pins.direct would silently look like "touch removed".
    """
    print("-- touch (GP16) handled outside the matrix")
    src = (KEYBOARD_DIR / "loudest_micro.c").read_text()
    check(f"loudest_micro.c binds TOUCH_PIN to {TABLE['TOUCH_OUT']}",
          re.search(r"#define\s+TOUCH_PIN\s+" + TABLE["TOUCH_OUT"] + r"\b", src) is not None)
    check("loudest_micro.c declares the touch input ACTIVE-HIGH "
          "(TOUCH_PRESSED_STATE 1; board strap R10 TOUCH_AHLB->GND)",
          re.search(r"#define\s+TOUCH_PRESSED_STATE\s+1\b", src) is not None)
    check("loudest_micro.c injects the touch event at logical [3,2]",
          re.search(r"#define\s+TOUCH_MATRIX_ROW\s+3\b", src) is not None
          and re.search(r"#define\s+TOUCH_MATRIX_COL\s+2\b", src) is not None
          and "action_exec(MAKE_KEYEVENT(TOUCH_MATRIX_ROW, TOUCH_MATRIX_COL" in src)
    check("loudest_micro.c configures GP16 itself (matrix_init_pins no longer does)",
          "gpio_set_pin_input_low(TOUCH_PIN)" in src)
    # The global knob would invert the 13 genuinely active-low switches. Only a
    # real #define / config key counts here - the comments that explain WHY it
    # must not be used name the token on purpose.
    defs = []
    for f in sorted(KEYBOARD_DIR.rglob("*")):
        if not f.is_file() or f.suffix not in (".c", ".h", ".json", ".mk"):
            continue
        text = f.read_text()
        if re.search(r"^[ \t]*#[ \t]*define[ \t]+MATRIX_INPUT_PRESSED_STATE\b",
                     text, re.M):
            defs.append(f"{f.name} (#define)")
        if re.search(r'"MATRIX_INPUT_PRESSED_STATE"[ \t]*:', text):
            defs.append(f"{f.name} (json key)")
    check("MATRIX_INPUT_PRESSED_STATE is NOT defined (it is global; it would "
          "invert all 13 active-low switches)", not defs, f"defined in {defs}")


def main():
    ap = argparse.ArgumentParser()
    ap.add_argument("--qmk-info", type=Path,
                    help="JSON dump from: qmk info -kb loudest_micro -f json")
    ap.add_argument("--qmk-home", type=Path,
                    help="vial-qmk checkout; verifies the via_command_kb backport")
    args = ap.parse_args()

    print("agentpad13 Rev A pin-map check "
          "(embedded definitive table; current public board v5_8)")

    kb_json = json.loads((KEYBOARD_DIR / "keyboard.json").read_text())
    assert_pin_config(kb_json, "keyboard.json")
    check_touch_outside_matrix()

    print("-- source scan")
    src_pins = set()
    for f in sorted(KEYBOARD_DIR.rglob("*.[ch]")):
        src_pins |= set(re.findall(r"\bGP\d+\b", f.read_text()))
    stray = sorted(src_pins - ALLOWED)
    check(f"sources reference only table-assigned pins ({sorted(src_pins)})",
          not stray, f"stray pins {stray}")
    check("sources reference no forbidden pin (incl. the GP21=GPIO24 net-name trap)",
          not (src_pins & FORBIDDEN), f"found {sorted(src_pins & FORBIDDEN)}")

    if args.qmk_info:
        info = json.loads(args.qmk_info.read_text())
        assert_pin_config(info, f"qmk info ({args.qmk_info.name})")
        print("-- resolved build config extras")
        check("qmk info: WS2812_DI_PIN resolves from ws2812.pin",
              info.get("ws2812", {}).get("pin") == TABLE["RGB_MCU"])
        check("qmk info: processor is RP2040",
              info.get("processor") == "RP2040", f"got {info.get('processor')}")

    if args.qmk_home:
        print("-- vial-qmk tree")
        via_c = args.qmk_home / "quantum" / "via.c"
        patched = via_c.exists() and "via_command_kb" in via_c.read_text()
        check("vial-qmk quantum/via.c carries the via_command_kb backport "
              "(patches/0001-via-command-kb-backport.patch)", patched,
              "unpatched tree: VIA will shadow status-protocol IDs 0x01-0x04")

    print()
    if failures:
        print(f"FAIL: {len(failures)}/{checks} checks failed")
        for f in failures:
            print(f"  - {f}")
        return 1
    print(f"PASS: all {checks} pin-map checks against the definitive "
          "v5 GPIO table succeeded")
    return 0


if __name__ == "__main__":
    sys.exit(main())

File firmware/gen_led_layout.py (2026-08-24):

#!/usr/bin/env python3
"""Generate the QMK rgb_matrix.layout block from the Rev A board file.

Usage:
    python3 gen_led_layout.py path/to/agentpad13.kicad_pcb

Reads the LED1..LED24 footprint centroids and the Edge.Cuts outline straight
out of the KiCad board file, scales them into QMK rgb_matrix space
(x 0-224, y 0-64, origin top-left), and prints the JSON "layout" array to
paste into keyboard.json.

THE TRANSFORM IS ISOTROPIC: ONE scale factor for BOTH axes.
    s        = 64 / bbox_height            (0.640 units/mm on v5_8)
    y_qmk    = round((y_mm - y0) * s)
    x_qmk    = round(112 + (x_mm - x_center) * s)
The board is portrait (84.2 x 100.0 mm) and QMK's coordinate space is landscape
(224 x 64), so the height is the binding axis: y is scaled to fill 0..64 and x
gets the SAME units/mm, which leaves the LED cloud only ~54 units wide. It is
therefore CENTERED on x = 112 -- QMK's default effect center
(k_rgb_matrix_center = {112, 32}, quantum/rgb_matrix/rgb_matrix.c:32), so no
RGB_MATRIX_CENTER override is needed: the default is correct by construction.
LED13 sits at board x = 42.1 mm = exactly the bbox center, so it lands on
x = 112 dead on.

(CHANGED 2026-08-15, recorded in `release/RELEASE.md` row K. This used to
normalise each axis INDEPENDENTLY to the bbox --
"x = round((x_mm - x0) / w * 224)", "y = round((y_mm - y0) / h * 64)" -- giving
x 2.660 units/mm against y 0.640 units/mm, an aspect distortion of 4.16:1. That
is QMK's own convention and is not a bug, but on a portrait board it skews every
geometry-bearing animation: of the 10 enabled here, cycle_pinwheel, cycle_spiral,
dual_beacon and rainbow_moving_chevron all read the LED coordinates as a plane.
The y column is NUMERICALLY UNCHANGED by this rewrite -- (y_mm - y0) * (64/h) is
the same arithmetic as (y_mm - y0) / h * 64 -- so only x moved, on 23 of the 24
entries. LED13 was already 112 under both transforms, because 42.1 mm is the
midpoint of the 0..84.2 span as well as the bbox center.)

THE CURRENT PUBLIC BOARD IS `release/hardware/pcb/v5_8.kicad_pcb`
(v5_8, md5 8c32ff4a6e6d77a87c4584029d4a1c75) -- run this against that file.
The layout was originally diffed against v5_6 at 24/24 entries and 0
mismatches. v5_8 retains the v5.7 LED20/LED21 correction and changes only TP5,
not any LED centroid, net, or board-outline coordinate
(`release/hardware/pcb/V5-NOTES.md`).

Chain order (electrical, verified on the board: U5.B -> RGB_D00 -> LED1 ...
LED14 -> RGB_D14 -> LED15 ... LED24):
    chain 0-12  = LED1-LED13  = per-key, under SW1-SW13   (flags 4)
    chain 13    = LED14       = layer indicator           (flags 8)
    chain 14-23 = LED15-LED24 = edge underglow            (flags 2)

Per-key chain positions carry the QMK "matrix" association: SW1-SW4 = row 0,
SW5-SW8 = row 1, SW9-SW12 = row 2, SW13 (2U hero) = [3, 0].
"""
import json
import re
import sys


def footprint_positions(board_text):
    """Map footprint reference -> (x_mm, y_mm) for every footprint."""
    refs = {}
    for m in re.finditer(r'\(footprint\s+"[^"]+"', board_text):
        depth, i = 0, m.start()
        while i < len(board_text):
            c = board_text[i]
            if c == "(":
                depth += 1
            elif c == ")":
                depth -= 1
                if depth == 0:
                    break
            i += 1
        block = board_text[m.start() : i + 1]
        at = re.search(r"\(at\s+([-\d.]+)\s+([-\d.]+)(?:\s+[-\d.]+)?\)", block)
        ref = re.search(r'\(property\s+"Reference"\s+"([^"]+)"', block)
        if at and ref:
            refs[ref.group(1)] = (float(at.group(1)), float(at.group(2)))
    return refs


def outline_bbox(board_text):
    xs, ys = [], []
    for m in re.finditer(
        r"\(gr_(?:line|arc|rect|circle)[^)]*?\(start\s+([-\d.]+)\s+([-\d.]+)\)"
        r".*?\(end\s+([-\d.]+)\s+([-\d.]+)\).*?\(layer\s+\"Edge\.Cuts\"\)",
        board_text,
        re.S,
    ):
        xs += [float(m.group(1)), float(m.group(3))]
        ys += [float(m.group(2)), float(m.group(4))]
    return min(xs), min(ys), max(xs), max(ys)


# QMK's default RGB-matrix effect center, i.e. the point every geometry-bearing
# animation spins/sweeps around: quantum/rgb_matrix/rgb_matrix.c:32,
# `const led_point_t k_rgb_matrix_center = {112, 32};` (used whenever
# RGB_MATRIX_CENTER is not defined). Centering the LED cloud here is what makes
# the default correct, so the keyboard does not have to override it.
QMK_CENTER_X = 112

# The current public v5_8 board, for the sanity assertion below.
PUBLIC_BOARD_SCALE = 0.64  # = 64 / 100.0 mm bbox height
PUBLIC_BOARD_X_CENTER = 42.1  # = (0.0 + 84.2) / 2 mm
_EPS = 1e-9


def main():
    if len(sys.argv) != 2:
        sys.exit(__doc__)
    board_text = open(sys.argv[1]).read()
    refs = footprint_positions(board_text)
    x0, y0, x1, y1 = outline_bbox(board_text)
    w, h = x1 - x0, y1 - y0

    # ONE scale for both axes (see the module docstring). Height is binding
    # because the board is portrait and QMK's space is landscape.
    s = 64.0 / h
    x_center = (x0 + x1) / 2.0

    # Fail loudly rather than silently emit a layout for some other board: every
    # number downstream (keyboard.json rgb_matrix.layout, and the claim that the
    # default k_rgb_matrix_center is correct) is pinned to the public v5_8 board.
    if abs(s - PUBLIC_BOARD_SCALE) > _EPS or abs(x_center - PUBLIC_BOARD_X_CENTER) > _EPS:
        sys.exit(
            "REFUSING TO EMIT: this board's derived transform does not match the\n"
            "current public v5_8 board.\n"
            f"  Edge.Cuts bbox : x {x0} .. {x1}  (w {w})   y {y0} .. {y1}  (h {h})\n"
            f"  derived scale  : 64/h = {s!r}          expected {PUBLIC_BOARD_SCALE!r}\n"
            f"  derived center : (x0+x1)/2 = {x_center!r}   expected {PUBLIC_BOARD_X_CENTER!r}\n"
            "If the outline really changed, re-verify the x=112 centering claim and\n"
            "whether RGB_MATRIX_CENTER now needs an explicit override before\n"
            "relaxing this check."
        )

    def qmk(ref, flags, matrix=None):
        x_mm, y_mm = refs[ref]
        entry = {}
        if matrix is not None:
            entry["matrix"] = matrix
        entry["x"] = round(QMK_CENTER_X + (x_mm - x_center) * s)
        entry["y"] = round((y_mm - y0) * s)
        entry["flags"] = flags
        return entry

    leds = []
    # chain 0-11: LED1-LED12 under the SW1-SW12 4x3 grid
    for chain in range(12):
        leds.append(qmk(f"LED{chain + 1}", 4, matrix=[chain // 4, chain % 4]))
    # chain 12: LED13 under SW13 (2U hero)
    leds.append(qmk("LED13", 4, matrix=[3, 0]))
    # chain 13: LED14 layer indicator
    leds.append(qmk("LED14", 8))
    # chain 14-23: LED15-LED24 underglow ring
    for n in range(15, 25):
        leds.append(qmk(f"LED{n}", 2))

    print(json.dumps({"layout": leds}, indent=4))


if __name__ == "__main__":
    main()

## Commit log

2026-07-15 Loudest Micro Rev A: hardware (KiCad schematic + build123d case) and firmware (vial-qmk port)
    Moved from the work-loudest design repo (full design history remains there).
    - hardware/pcb: KiCad 9 schematic, 118 components, 34-line draft BOM, review notes
    - hardware/case: parametric build123d shell+lid, 5 tolerance coupons, STL/STEP, khana-checked
    - firmware: compiling vial-qmk tree + prebuilt UF2s, Raw HID agent-status protocol v0
    [BOM-draft.csv, assembly.step, coupon_encoder_js_opening.step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]
2026-07-18 Rev A v4: complete PCB layout — DRC-clean 2-layer, gerbers + assembly bundles
    [BOM-draft.csv, BOM.csv, agentpad13.kicad_pcb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]
2026-07-18 Case v2: plate-as-deck + printed tray — STL/STEP + plate fab files
    [agentpad13_v2_band.step, agentpad13_v2_band.stl, agentpad13_v2_coupon_panel.kicad_pcb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]
2026-07-18 Firmware v4: validated pin map, VIA fix, emulator-tested UF2s
    [check_pins_v4.py, gen_led_layout.py, harness.c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]
2026-07-18 Add case v2 product renders to README
2026-07-19 Case v2: close-fit Ø3.2 plate screw holes + widened band plate-recess (printed-band fit)
    - Plate/coupon-panel screw holes Ø3.4 -> Ø3.2 (ISO 273 close fit): the four
    screws now center the plate to +/-0.1 so the deck reveal stays even.
    - Band plate recess widened to plate + 0.3/side so an FDM-printed band
    (inner cavities typically print 0.1-0.3 tight) still swallows a
    worst-case fab plate; nominal reveal is 0.3 mm. Plate seat and all
    other geometry unchanged; assembly interference/clearance gates re-run
    green (62/62 case, 15/15 coupons).
    - README: tray XY-scale calibration note + pin-vise fallback for the
    close-fit holes; reveal/fit rationale.
    [agentpad13_v2_band.step, agentpad13_v2_band.stl, agentpad13_v2_coupon_panel.kicad_pcb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]
2026-07-19 Case v2: capacitive-touch electrode in the default plate + gold-disc marker; blank plate variant
    - Default plate now carries the touch electrode: Ø14 top pad with Ø12
    soldermask opening = exposed ENIG gold disc marking the touch key
    (finger lands directly on the electrode); Ø14 underside landing pad
    with Ø8 mask opening for a conductive-foam pillar down to the board's
    touch pad; 2 vias hidden under the masked annulus. Order ENIG.
    - agentpad13_v2_plate_blank.kicad_pcb added: no-copper variant for
    anyone skipping the pad/ENIG (falls back to weaker through-air touch).
    - Touch chip now carries the identical electrode construction so the
    jig tests the real stack (with/without foam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
    [agentpad13_v2_plate.kicad_pcb, agentpad13_v2_plate_blank.kicad_pcb, agentpad13_v2_touch_chip.kicad_pcb]
2026-07-19 README: plate options — gold-disc touch plate (ENIG) + blank variant
2026-07-20 v5: corrected board (encoder/USB-C/joystick), case v2.5 + toppers + gasket, ordering guide
    [BOM.csv, agentpad13.kicad_pcb, agentpad13_v2_band.step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]
2026-07-20 Docs: remove legacy product-name references — the project is agentpad13
    [agentpad13.kicad_sch]
2026-07-20 Renders: assembled product hero + six-view turntable; hero embedded in README
2026-07-21 Keycaps: vertical-wall plateau/dish caps, Box + MX, 17.5/18.0 mm, print-ready STLs
    [cap_dish_1u.stl, cap_dish_1u_17p5.stl, cap_dish_2u.stl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]
2026-07-22 Keycaps: correct height (6.6/6.0 mm) + one universal cap; drop the fabricated 9.9 mm Box variant
    The prior split shipped a taller "Box" cap built on a wrong model — that a Kailh
    Box hides a fixed shroud the cap must swallow. It doesn't: the box is one piece
    with the moving stem, so it travels down with the cap and keycap height is
    independent of switch travel. Corrected to the true exposed-cross geometry
    (cavity 4.5 mm), which is identical for Box Jade, Cherry MX, and Gateron KS-9
    (verified against four manufacturer drawings).
    - ONE universal cap replaces the box/ + mx/ split: plateau/dish × 1U/2U/2U-stab
    × 17.5/18.0 mm — 12 STLs, all khana-verified (fit, pitch, press-fit, box).
    - B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
    [cap_dish_1u.stl, cap_dish_1u_17p5.stl, cap_dish_2u.stl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]
2026-07-25 Case v2.7: band sidewall 5.4 mm default, three gated wall variants
    The 2.4 mm-wall band is retired (a fab 3D-print review flagged its corners
    as too thin) and removed from the repo. The band now ships in three gated
    wall thicknesses, exported under their own _w{WALL} names so no supersession
    is silent:
    _w3.0 90.8 x 106.6 mm corner 1.59 887b2538619db46d63b07cf044762bab
    _w5.4 95.6 x 111.4 mm corner 4.40 34be6bf79a6bb81995807448639f4822 DEFAULT
    _w7.4 99.6 x 115.4 mm corner 6.40 163669962a928793a4e65347a80e4cfe
    Only the outside of the band moves. The ledge, plate recess, boss sockets,
    screw pass and USB aperture are frozen, so the plate, tray, PCB and gasket
    kit are th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
    [agentpad13_v2_band_1.6mm.step, agentpad13_v2_band_1.6mm.stl, agentpad13_v2_band_1.6mm_w3.0.step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]
2026-07-25 Keycaps: lobed boss + compliant crush-rib socket
    A fab 3D-print review measured the cruciform socket wall at 0.628/0.648 mm
    and offered "thicken to 1.0 mm" or "accept the risk". Neither: 1.0 mm is
    physically unreachable — the moat between the switch's cross and its box wall
    is 0.90 mm and already fully spent (0.10 slot-to-cross + 0.65 wall + 0.15
    boss-to-bore), so a 1.0 mm wall would put the boss 0.20 mm into interference
    and the cap would never seat.
    Two internal changes; the outside of the cap — footprint, height, walls, top
    surface — is bit-for-bit unchanged:
    1. Boss profile is lobed, Circle(3.00) & Rectangle(5.5,5.5) instead of a plain
    O5.50 circle. Still 5.50 across the flats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
    [cap_dish_1u.stl, cap_dish_1u_17p5.stl, cap_dish_2u.stl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]
2026-07-25 Docs: v2.7 band + keycap socket; drop superseded case references
    README / HOW-TO-ORDER caught up with the case v2.7 band and the revised
    keycap socket:
    - case v2.5 -> v2.7 throughout; outer size 89.6 x 105.4 -> 95.6 x 111.4 mm
    (default 5.4 wall), with the wall-choice table and the "do not print the
    unsuffixed band if you find it in an old copy" warning.
    - HOW-TO-ORDER card 3 orders the _w5.4 band by name and explains the suffix;
    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
2026-07-25 Renders: v2.7 thick-wall band hero + turntable
    Regenerated both product renders against the shipping case geometry
    (agentpad13_case_v2.py at WALL 5.4, OUTER 95.6 x 111.4). The old pair was
    built on the retired 2.4 mm sidewall, so the case read 6 mm narrower than
    what ships and had no USB port funnel.
    Same pipeline, same part set, same colour scheme and same output size as
    before (hero 2275x1995, turntable 2392x1522), so the README embeds are
    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
2026-08-05 BOM: SW14/SW15 tact was the wrong part for its footprint (PCBWay catch)
    The BOOT/RESET tact switches were specified as XKB TS-1187A (LCSC C318884)
    against the footprint SW_SPST_PTS645Sx43SMTR92 — a C&K PTS645 6.0 x 6.0 mm /
    H4.3 gull-wing land pattern. The TS-1187A is a 5.1 x 5.1 mm part with a 6.5 mm
    lead span against this footprint's 7.96 mm pad span: its leads land ~45 um over
    the pad edge (~9 % of pad area). Not solderable. PCBWay's component
    verification caught it during the order review.
    Corrected part (land-pattern verified to 0.01 mm X / 0.00 mm Y):
    C&K PTS645SM43SMTR92 LFS — LCSC C221880, DigiKey CKN9112CT-ND
    6.0 x 6.0 mm SMT gull-wing, H4.3, 160 gf, SPST-NO, ~$0.313@10
    D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
    [BOM.csv, agentpad13.kicad_sch, bom_opaque.csv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]
2026-08-05 JS1: public mirror was carrying the dead Adafruit 3103; re-sync to the YA13
    The 2026-07-19 joystick reversal (Adafruit 3103 PSP-slider -> YTL
    YA13-FL7.4-B5Ka(45-10)-R-Y06, LCSC C37323742, machine-placed THT) landed in
    the private source but not here, so this repo had become the one telling
    readers to buy and meter a part that is no longer used.
    - hardware/pcb/agentpad13/agentpad13.kicad_sch: re-snapshotted from the
    corrected private schematic, re-applying only the 2 branding hunks
    (title_block, descriptive text). Diff vs private is back to exactly those
    2 hunks / 4 lines -- it was 5 hunks before this commit. JS1 is now
    Joystick:YA13_Tilt_Gimbal with MP1-MP4 GND frame lugs declared.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
    [agentpad13.kicad_sch]
2026-08-06 Plate fab set was PRE-TRIM: 100.2 mm long axis, outside the <=100 mm promo tier
    The mirror was shipping the plate as it existed BEFORE the owner's 2026-07-21
    long-axis trim. Measured from Edge.Cuts on every copy here:
    agentpad13_v2_plate_v5.kicad_pcb 84.400 x 100.200 -> 84.400 x 100.000
    agentpad13_v2_plate_tented_ring_v5.kicad_pcb 84.400 x 100.200 -> 84.400 x 100.000
    agentpad13_v2_plate_blank_v5.kicad_pcb 84.400 x 100.200 -> 84.400 x 100.000
    plate_v5_gerbers.zip (Edge_Cuts.gm1) 84.400 x 100.200 -> 84.400 x 100.000
    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
    [agentpad13_v2_plate_blank_v5.kicad_pcb, agentpad13_v2_plate_tented_ring_v5.kicad_pcb, agentpad13_v2_plate_v5.dxf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]
2026-08-15 Prebuilts were the pre-touch-fix pair: this repo shipped a board that boots into the wrong layer
    Anyone who flashed these prebuilts got the ships-broken firmware: the touch
    key's polarity was inverted, so the pad powered on with that key stuck pressed,
    jumped straight to the second layer (base layer unreachable, SW1 dead), and
    the touch pad triggered on finger-lift. The fix has existed upstream since
    2026-08-13; this repo was last synced before it.
    Re-synced to the current upstream firmware tree (22 files):
    - prebuilts: default 88064 B -> 88576 B (1c0ff911...), vial 104448 B
    (286fb09d...). The touch key now lives outside the scanned matrix and is
    polled active-high with its own debounce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
    [check_pins_v4.py, gen_led_layout.py, keymap.c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]
2026-08-19 Bring-up needed a second firmware and a text editor; now it needs one button
    The joystick shipped on placeholder calibration, and the only way to
    replace it was to flash a separate 'calibrate' build, type its numbers
    into a text editor, paste them back into source and rebuild. This repo
    still told you to do that -- against a UF2 that no longer exists.
    Now: flash agentpad13.uf2, hold SW14 (the button in the back) for a
    second, and the 13 key LEDs walk you through it. White armed, blue bar
    while it finds where the stick rests, amber-to-green while you roll it
    around the edge, green flash stored. About 15 seconds. It lives in the
    board's own memory and survives unplugging and reflashing, so it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
    [harness.c, keymap.c, loudest_micro.c]
2026-08-19 Ordering: tell PCBWay to put their product number on the hidden face
    The top plate is a bare decorative panel with no components, so PCBWay's
    normal rule for hiding their product number ('under the IC') has nothing
    to aim at -- and on our own order it came back printed on the top face,
    the visible deck of the finished product.
    On the order form set 'Remove product No.' = 'Specify a location' (this
    option is free), and in the 'Other special request' box state that the
    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
2026-08-19 Board: the bottom two underglow LEDs were firing out of the case, not into it
    Six of the ten underglow LEDs point inward and diffuse through the band.
    Four pointed outward and read as visible dots instead of a glow. Found on
    an assembled board.
    Not an assembly fault. These are daisy-chained SK6812-SIDE parts, so a
    180-degree misplacement would reverse VDD/VSS and DIN/DOUT and kill that
    LED plus everything downstream of it. All ten light. The fab placed
    exactly what the files said.
    The generator declared a coherent all-inward rotation set, then applied
    the rotation and only afterwards flipped each part to the back copper.
    That flip negates orientation, so the two LEDs firing along Y reverse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
    [agentpad13.kicad_pcb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]
2026-08-19 Fabpack: the ordering notes inside the zips said the wrong revision
    The gerbers were named v5_7 but the ORDERING.md packaged beside them
    still said v5_6 -- every technical claim in it was correct, it just
    named the wrong board. Re-packaged with the revision templated at the
    source so it cannot drift again.
    Gerbers, drill, CPL and BOM are byte-identical to what was already
    published; only the ordering notes changed. gerbers.zip needed no
    update at all.
2026-08-19 Bring-up: explain the Mac 'not enough space' error when flashing
    Dragging the UF2 in Finder fails with a disk-space error on macOS. Not a
    space problem, and nothing wrong with the board: the bootloader is a fake
    filesystem that takes exactly one file write, Finder tries to add its own
    hidden metadata, the volume refuses, and Finder calls it a space error.
    Copy from a terminal and it works every time. Linux equivalent included;
    Explorer on Windows is normally fine.
2026-08-19 Bring-up: the flash command needs cp -X, not plain cp
    Without -X, macOS tries to attach extended attributes to the copy, the
    bootloader drive refuses the second write, and you get 'Invalid argument'.
    -X copies the file and nothing else.
2026-08-20 Case: the encoder didn't fit the plate, and the tray was mirrored
    Two separate defects in the published case files, both of which cost you a
    part if you built from them.
    The plate's encoder aperture was 13.0 x 13.0 mm, centred on the shaft. Common
    EC11 encoders are not that small: the ones this build was validated against
    measure about 13.7 mm across the pin axis, and the body fouled one wall of the
    opening on assembly -- it seated fine on one side and bound on the other. The
    opening is now 14.0 x 13.0 mm. The extra 1.0 mm went entirely onto the side
    that bound; the opposite edge did not move, so the shaft now sits 0.5 mm off
    the aperture centre by design. Corner radius stays 1.5 mm, delibe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
    [agentpad13_v2_plate.step, agentpad13_v2_plate_blank_v5.kicad_pcb, agentpad13_v2_plate_tented_ring_v5.kicad_pcb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]
2026-08-20 Case: the plate floated in the band, because the pocket fit a plate we never made
    The band's plate pocket was cut 85.0 x 100.8 mm around a plate that is
    84.4 x 100.0 mm. That leaves 0.8 mm of slack along the long axis, and since
    nothing centres the plate, all of it shows up as a gap at one end -- close to a
    millimetre of daylight on a part whose whole job is to look flush.
    The cause was a split source of truth. The plate was trimmed from 100.2 to
    100.0 mm early on, to land inside the cheaper sub-100 mm fab tier, but that trim
    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
    [agentpad13_v2_band_1.6mm_w3.0.step, agentpad13_v2_band_1.6mm_w3.0.stl, agentpad13_v2_band_1.6mm_w5.4.step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]
2026-08-20 Case: the tray bases ship, and every base underside is now flat
    The tray has had four Ø6 mounting pockets in its underside since the central
    mount landed, and nothing to put in them was ever published. Three bases now
    ship: a full-footprint TPU mat for grip, a wedge that gives a 6.5 degree
    back-raised typing angle, and a Ø70 circular pedestal. They all clip into the
    same four pockets, so tray-only and tray-plus-base are both complete products
    and you can change your mind later without touching anything else.
    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
    [base_fit_gauge.stl, base_mat_peg_5p6.stl, base_mat_peg_5p7.stl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]
2026-08-20 Bases: three of them now, at a real typing angle, and the pedestal carries itself
    The base family shipped last week as a demonstration that the mounting pattern
    works for any shape. This turns it into an actual catalog of three, and every
    one of them changed, so read this before reprinting.
    riser replaces mat. Same 91.6 x 107.4 outline, but 3.0 mm thick instead of 2.4.
    It is one file for two jobs: print it in TPU and it is a grip base, print it in
    PETG or PLA and it is a rigid stand that lifts the pad slightly. If you printed
    a mat, the riser is its replacement -- the old files are gone rather than kept
    around to be printed by mistake.
    The wedge angle went from 6.5 to 8 degrees. That was n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
    [base_mat_peg_5p6.stl, base_mat_peg_5p7.stl, base_mat_peg_5p8.stl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]
2026-08-21 Toppers v2: if you printed a v1 knob or stick cap, print it again
    The v1 topper family is retired and no longer ships. Two of the changes are
    fit corrections rather than taste: the old 18 mm knob never quite covered the
    plate's encoder opening, and it was too short for the shaft on your board.
    Every v2 knob is 19.0 mm, tops out at +27.0, and seats the shaft uncut.
    The family is now three knobs -- A helical knurl, B2 scooped top, C cross
    hatch, one size in three bores -- and two stick parts instead of four caps:
    a dot nub that clears the neighbouring 2U keycap at full throw, and a
    one-piece TPU puck whose integral cone land is the throw restrictor. What
    changed and why is in release/RELEASE.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
    [agentpad13_v2_band_1.6mm_w3.0.step, agentpad13_v2_band_1.6mm_w3.0.stl, agentpad13_v2_band_1.6mm_w5.4.step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]
2026-08-21 The configurator is how you build one
    The order sheet now lists the last four things you buy yourself -- the four
    M3 button-head screws, the heat-set inserts, the conductive foam pillar for
    the touch pad, and a small sheet of 0.5 mm PORON for the optional gasket --
    so nothing is left to find in a document.
    HOW-TO-ORDER.md is now the configurator's static form: the same questions in
    the same order, for people who would rather read than click. Everything it
    used to explain twice now lives once, in RELEASE.md.
    The README is shorter.
2026-08-21 Configurator: shorten the visible encoder stem
2026-08-21 fix: address Direct OAI firmware review
    [keymap.c, loudest_micro.c]
2026-08-21 fix: reject invalid Direct OAI status updates
    [codex_oai.c]
2026-08-23 Refresh AgentPad13 v5.7 release artifacts
    [BOM.csv, agentpad13.kicad_pcb, agentpad13.kicad_sch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]
2026-08-24 Publish current joystick toppers and restrictor
    [stick_nub_v2_C2_cell2.stl, stick_nub_v2_C2_clearance_high.stl, stick_nub_v2_C2_clearance_low.stl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]
2026-08-24 Release AgentPad13 v5.8
    [agentpad13_v2_tray_v5.step, agentpad13_v2_tray_v5.stl, bom_opaque.csv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]

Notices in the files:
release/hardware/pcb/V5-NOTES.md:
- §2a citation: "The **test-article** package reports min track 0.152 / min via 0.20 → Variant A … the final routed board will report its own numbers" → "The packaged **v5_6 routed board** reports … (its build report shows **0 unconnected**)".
